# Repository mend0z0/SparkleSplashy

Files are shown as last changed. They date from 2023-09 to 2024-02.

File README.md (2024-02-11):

## Latest update

``
Latest update, or process that is going through
``

# Project

Description...

## Category

__Home/Office Automation__

## Features

- 
- 
- 

## Tech Stack

### Hardware

- **MCU:** ATSAM4SD16BA
- **Connection:** 
- **PCB Layers:** 4Layers (None-controlled Impedance)
- **CAD:** KiCAD

### Firmware

- **OS:** FreeRTOS
- **Programming Language:** C
- **IDE:** Microchip Studio

### Application

- **IDE:** Qt6
- **Operating System:** Linux/Windows
- **Device:** Laptop

### Mechanical

- **CAD:** Solid Edge
- **Printing Method:** 3D Printing

## Block Diagrams

SystemDesign

Hardware

Firmware

## Screenshots

### Hardware

#### CAD View

_CADView

#### 3D_View

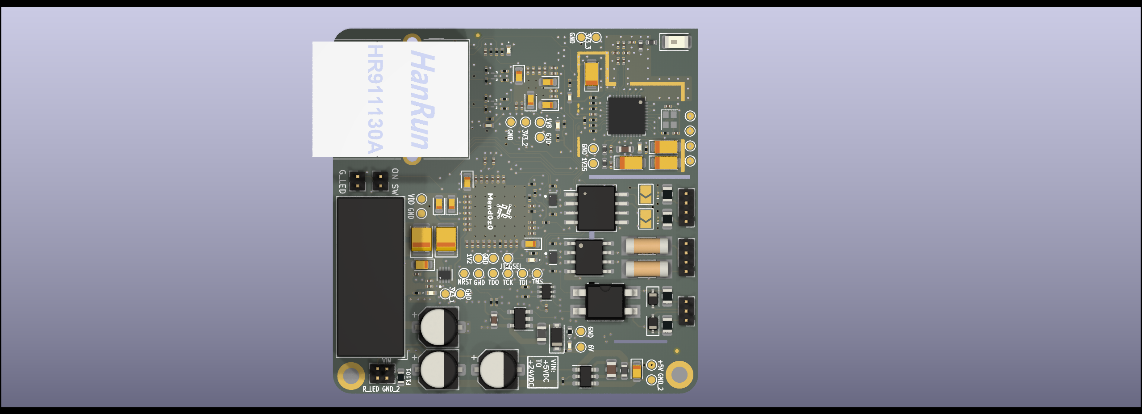
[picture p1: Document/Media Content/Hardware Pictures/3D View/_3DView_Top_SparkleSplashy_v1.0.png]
_3DView_Top


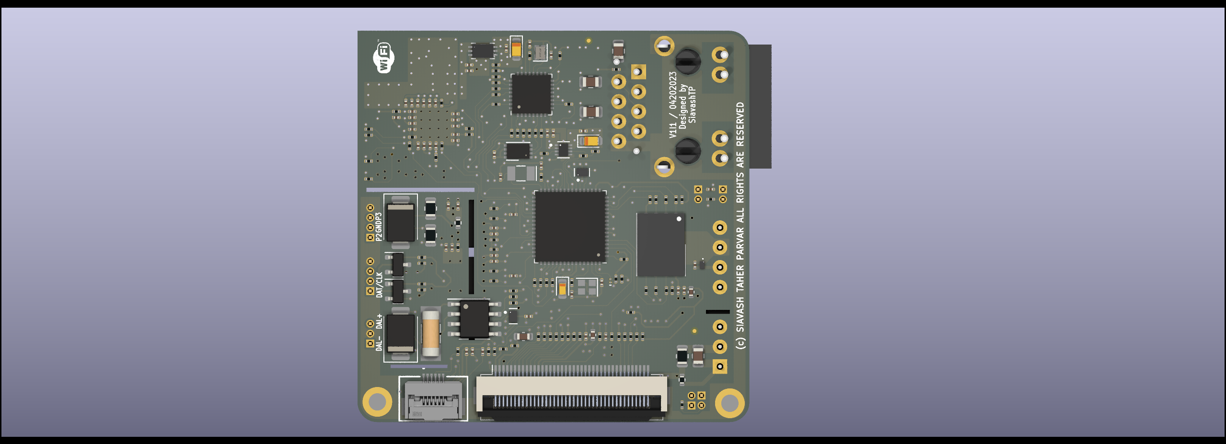
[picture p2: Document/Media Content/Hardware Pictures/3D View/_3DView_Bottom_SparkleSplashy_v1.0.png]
_3DView_Bottom

 
#### Assembled Hardware

_ASMView_Top

_ASMView_Bottom

### Application
App Screenshot

## Demo

Insert gif or link to demo, it'll be my youtube channel

## LOGO

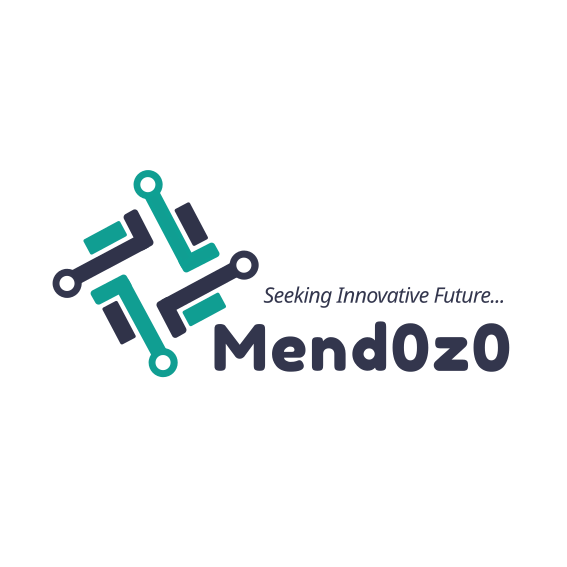
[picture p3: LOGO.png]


## Author

- [@Siavash Taher Parvar](https://www.linkedin.com/in/mend0z0)

## Support

[Support Link](https://github.com/sponsors/mend0z0)

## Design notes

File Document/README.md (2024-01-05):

1. Block Diagrams: 
	1. _FBD_HW_Prj_vXY.svg
	2. _FBD_SYS_Prj_vXY.svg
	3. _FBD_FW_Prj_vXY.svg

2. Datasheet: 

3. Media Content: 
	1. Application Screenshot:

	2. Hardware Picture:
		1. 3D View:
			1. _3DView_Top_Prj_vXY.png
			2. _3DView_Bottom_Prj_vXY.png

		2. Assembled Hardware:
			1. _ASMView_Top_Prj_vXY.png
			2. _ASMView_Bottom_Prj_vXY.png

		3. CAD View:
			1._CADView_Prj_vXY.svg

	3. Videos:

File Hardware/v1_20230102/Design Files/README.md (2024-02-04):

# TODO list

A brief description of this todo list belongs to what project

## Tasks

- #### MUST to DO (List the works that proper working of project depends on these tasks):
    - Correct 24KR_1/20W footprint
    - Review the schematic and replacing the limiting resistor possibly with PTC!
    - Correcting the link for part -CW105550A-15NJ-.
    - It's absolete (NC7WZ14P6X-L22347) find another one!
    - Adding the LCD to BOM! (correcting it's library)
    - 
- #### Important (List the works that efficient and optimized functionality of project depends on these tasks):
    - 
    -
    - 
- #### General (List tasks that are good to be done but the functionality of project doesn't depend on these):
    - 
    -
    -

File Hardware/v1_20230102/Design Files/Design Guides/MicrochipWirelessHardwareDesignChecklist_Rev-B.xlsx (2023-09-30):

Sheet: Checklist
Microchip Wireless Hardware Design Checklist
Introduction: This checklist is provided as a "Best Pratice" guide for your RF design. It can be used as-is or as part of our free design review service called WirelessCheck. If you would like use this value added service, please click here->. |  |  |  |  |  |  | Link to WirelessCheck (https://www.microchip.com/design-check-services)
Instructions for WirelessCheck Customers: Fill in "Customer" column for all checkpoints during the design phase and prior to requesting design review support from Microchip. While raising design review support request, attach the completed checklist along with the design files (Schematic, BoM, PCB Layout File, Gerber files). A Microchip Support Engineer will review and provide his/her comments in the "Microchip" column and communicate this back to you.
Instructions for as-is useage: Fill in "Customer" column for all checkpoints during the design phase. This will provide you with a checklist of typical areas of concern for your RF design and some suggestions on best practices from Microchip RF Engineers.
S.No. | Design Item | Description | Customer |  | Microchip |  | Customer
 |  |  | Verified (Yes/No/NA) | Comment if any | OK/NOT OK | Microchip Review Comments | Response for Review Comments
1 | General Considerations:
1.1 | Documentation | Did you refer the latest version of the documents for the design such as Silicon chip/Module datasheet, Errata and Reference/Evaluation kit design documents, chip-down collateral package (for chip-down design)?
1.2 | Device (Silicon Chip/Module) | Is the device ordering part number used in the design BoM verified?
1.3 | Reference Design File | Microchip Wireless Reference PCB design files will be mostly in Altium Tool format. Customer should convert into their other CAD tools if needed.
1.4 | Pin check | Is the pinout of the schematic logical symbol against the data sheet verified?
1.5 | Footprint Check | Is the PCB footprint of the silicon chip/module verified against the package outline drawing or recommended footprint/land pattern drawing detailed in the data sheet? It is recommended to use the same footprint as in the reference design.
2 | PCB Stack Up Considerations:
2.1 | PCB Stack up | Use the same PCB Layer Stackup as in the reference design. If in case following a different PCB layer stackup to meet the custom design requirement, confirm the following items before the start of the design • Check with PCB Fabrication Vendor for the manufacturability of the stackup. • Ensure to follow a good reference plane for RF ground and Digital/Analog Ground plane and other high speed design requirements. • Check the controlled trace impedance requirements for the design and get the required trace width and spacing details from the PCB Fabrication Vendor.
3 | Power Supply Considerations:
3.1 | Power Supply Pins | Do all the power pins connected to the correct supply rails in the design and it is within the required tolerance value as detailed in the datasheet?
3.2 | Power Supply Source | Is the power supply source clean without any noise? Note: It is recommended to use LDO. If you are using the switching regulator, ensure that the sufficient filtering are added to suppress the switching noise (ripple) on the power rail as it impacts the RF performance.
3.3 | Power Budgeting | Is the power budgeting performed to ensure the power source component capable to supply the required current to the circuit in all functional conditions?
3.4 | Power Trace | Is the power rail trace thickness/width selected appropriately based on the expected peak power consumption, with certain margin? Use a power trace calculator to find the minimum required trace width. PCB Trace Width Calculator (For Reference): https://www.desmith.net/NMdS/Electronics/TraceWidth.html
3.5 | Ground | Do the grounding specification followed as in the datasheet or in the corresponding silicon chip/module reference/evaluation design kit? It is preferred to use simple solid ground plane unless otherwise specified.
3.6 | Power Sequencing | Did you check the device (silicon/module) requires any specific power up/down sequencing in terms of the order and delays of the power supplies?
3.7 | Thermal Pad /Ground Paddle | Did you check whether the device (silicon chip/module) require thermal pad ground connection? Note: Ensure that an array of GND vias connecting the thermal pad to the ground plane has sufficient low impedance ground return path which provides a better ground to the device and also acts as thermal sink. Also, connect the GND pin to the GND Paddle for better grounding in addition to the separate ground via.
3.8 | Ferrite Beads | Did you verify whether the ferrite beads placed in the design as specified in the recommended power pins of the silicon chip/module? Note: Place the ferrite beads as close as possible to the power pin.
3.9 | Bulk Capacitors | Did you verify whether the recommended bulk capacitors placed on the power rails of the design? Refer the Datasheet and/or reference design document for the recommended values.
3.10 | Decoupling/Bypass Capacitors | Did you verify whether the recommended decoupling capacitors placed on each power pins in the design? Refer the Datasheet and/or reference design document for the recommended values. Note: Ensure that the decoupling capacitors are effective at Radio Frequencies. Many passive capacitors are self-resonant at RF, therefore review S21 plots and frequency response curves. It is recommended to use COG and avoid Y5V and Z5U dielectric type capacitors.
3.11 | Placement & Routing | a. Prioiritze the placement and routing in the following order, (i) RF Section (ii) Buck or Boost LC Section (iii) Clock Section (iv) High Speed Signals (v) Other Power Section (vi) and finally low priority section placement and signals. b. Did you place the decoupling capacitors close to the power pins for high-frequency noise filtering? Note: Refer "Reference" worksheet Image-1 for the recommended decap routing. c. Did you verify whether each Ground pin have at least one ground via? d. Did you place vias very close to the power pads to connect the power/ground pins to the power/ground plane? This helps in minimizing stray inductance and IR (voltage) drop on the power line. e. Did you place multiple vias when Power trace/island changes the plane for current distribution?
3.12 | Copper Pour | Did you eliminate Island (Unconnected or floating or Dead) Copper Pour amd peninsulas of copper pour? Note: Refer "Reference" worksheet, Image-3 and Image-4 to know more about Island/s and peninsula/s.
4 | Reset and Chip Enable Considerations:
4.1 | Reset | Did you verify the connection and pullup/pulldown recommendation for the RESET pin in the datasheet?
4.2 | Chip Enable | Did you verify the connection and pullup/pulldown recommendation for the Chip Enable pin in the datasheet?
5 | Clocking Considerations:
5.1 | Clock Source | Recommend to follow the same clock source part (Crystal/TCXO) as in the reference design. As the clock parameters directly impact the RF performancem, customer should understand the impact on the performance involved if using different clock source part.
5.2 | Clock Trace Routing | a. Are the clock traces routed away from RF signals? b. Are the guarding ground vias placed along the crystals and the clock traces?
6 | I/O's:
6.1 | Pullups/Pulldowns | Are the recommended pullup and pulldown resistors placed on the I/O's with the suggested values as listed in the datasheet or reference design?
6.2 | Application Interface | Are the mandatory interfaces connected to communicate with the device (silicon chip/module) for the end application requirement?
6.3 | Impedance controlled trace | Is the impedance control requirement verified? Note: Unless otherwise stated, the single ended trace impedance should be 50Ω , differential trace impedance of USB should be 90Ω and other differential trace impedance should be 100Ω. Refer Device Datasheet and its design guide. Use an impedance calculator to calculate the trace width for a specific trace impedance. Check with fab house to optimize the materials and controlled impedance. Request for a TDR (Time Domain Reflectometry) test to the PCB fabricator for QA.
6.4 | Signal integrity | Did you complete the Signal integrity check such as, trace length match, impedance control requirements, proper termination requirement for the critical highspeed signals? Refer the reference kit design document for cross verification.
6.5 | Debug Interface | Did you check the required programming and debug interfaces like JTAG,SW? Ensure to expose the traces for debug.
6.6 | Test Interface | Did you check whether any dedicated test interface requires to communicate with the RF transceiver to perform RF level test such as, continuous Tx, Rx with Tx power control, channel selection, data rate selection for RF Validation, Regulatory Certification, and Production testing?
6.7 | Unused pins | Does all unused inputs terminated as recommened in datasheet?. Refer the evaluation kit design document and datasheet guidance.
6.8 | Test coverage | Did you check whether every (maximum possible) trace have a touch-down point (open solder mask on the via or some passive component pads apart from IC pads) for continuity testing in PCB manufacturing?
7 | RF Design Considerations:
7.1 | Module Based Designs - RF Design Considerations:
7.1.1 | Module Placement | Is the module placed in the base board as per the datasheet recommendation for best RF performance case? Refer "Reference" worksheet -> FCC KDB : Reference-1 for the FCC Guidance
7.1.2 | Mechanical Cutout/Slot | Did you verify the host board for mechanical cut out/slot area requirement? Refer module datasheet recommendation.
7.1.3 | Electrical Keep out Area | Did you check the host board copper keep out area requirement for the Top placement layer and all other PCB layers? Refer the module datasheet for the recommendation. Note: Ensure that no traces/metal structures are placed under antennas.
7.1.4 | GND Shielding and Stitching Vias | Are the sufficient GND area, fences/stitching vias for RF traces placed? Refer "Reference" worksheet Image-2 for the proper "via" stitching fences.
7.1.5 | Clearance | Is the minimum clearance requirement verified? • Antenna on the module must not be placed in direct contact or close proximity to plastic casing/objects. • Do not enclose the antenna within a metal structure.
7.1.6 | External Antenna (Applicable for only a module with external antenna connector) | Did you use the same antenna as specified in the Microchip Module certification test report? Note: If different antenna is preferred to use, refer to Q&A especially section III, B, C and D of FCC KDB (https://apps.fcc.gov/oetcf/kdb/forms/FTSSearchResultPage.cfm?switch=P&id=39060) for to use the Microchip regulatory compliance certification of the module.
7.2 | Chip-down Based Designs -RF Design Considerations:
7.2.1 | RF Front End Components and PCB layout. | Did you use the same RF front end design as specified in the reference design (Module design/Evaluation Kit)? Note: It is recommended to use the RF front end components and PCB Layout "AS IS" in the reference design (Module design/Evaluation Kit) to achieve the target RF Performance. Any deviation leads to degradation in RF performance.
7.2.2 | RF trace - Impedance control | Is the impedance control requirement verified for RF traces? Note: Unless otherwise stated, all the single ended RF trace impedance should be 50Ω and differential RF trace impedance should be 100Ω. Refer Device Datasheet and its design guide.
7.2.3 | Balun | Did you use the same balun circuitry as in reference design (Module design/Reference kit)? Note: All RF currents flow though the Balun. Make sure balun ground connections are solid.
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

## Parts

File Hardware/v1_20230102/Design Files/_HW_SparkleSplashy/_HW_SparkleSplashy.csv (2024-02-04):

Source: | D:\Projects\STP\SparkleSplashy\Hardware\v1_20230102\Design Files\_HW_SparkleSplashy\_HW_SparkleSplashy.kicad_sch
Date: | 2/4/2024 2:45:05 AM
Tool: | Eeschema 7.0.9
Generator: | C:\Program Files\KiCad\7.0\bin\scripting\plugins/bom_csv_grouped_by_value.py
Component Count: | 344
Collated Components:
Item | Qty | Reference(s) | Value | LibPart | Footprint | Datasheet | DNP | CURRENT RATING | Current Rating | D.C.R | DCR | Description | DescriptionCL05A475KQ5NRNC | ESR | INDCUTANCE | INDUCTANCE | Ihold | Inductance | Link | MAX DC | Package | Part NumbeR | Part Number | Part Numbner | RATED CURRENT | SCH CHECK | VBR | VOLTAGE RATE | VOLTAGE RATED | Voltage Off State | Voltage Rated
1 | 1 | ANT501 | 2450AT18A100E | _SCHLIB_SparkleSplashy:ANT_2450AT18A100E | RF_Antenna:Johanson_2450AT18x100 | https://www.johansontechnology.com/datasheets/2450AT18A100/2450AT18A100.pdf |  |  |  |  |  | 2.4GHz Chip RF Antenna 2.4GHz ~ 2.5GHz 0.5dBi Solder Surface Mount |  |  |  |  |  |  | https://www.digikey.com/en/products/detail/johanson-technology-inc/2450AT18A100E/1560676 |  |  |  | 2450AT18A100E |  |  | CHECKED
2 | 35 | C301, C302, C303, C304, C316, C317, C318, C324, C325, C332, C404, C408, C409, C410, C414, C504, C507, C508, C510, C520, C521, C524, C526, C529, C530, C603, C605, C803, C805, C1003, C1005, C1201, C1202, C1204, C1205 | 100nF/6V3 | _SCHLIB_SparkleSplashy:CAP_100nF/6V3 | Capacitor_SMD:C_0201_0603Metric | https://www.yageo.com/upload/media/product/productsearch/datasheet/mlcc/UPY-GPHC_X7R_6.3V-to-250V_22.pdf |  |  |  |  |  | 0.1 µF ±10% 6.3V Ceramic Capacitor X7R 0201 (0603 Metric) |  |  |  |  |  |  | https://www.digikey.ca/en/products/detail/yageo/CC0201KRX7R5BB104/12698853 |  | C0201 |  | CC0201KRX7R5BB104 |  |  | CHECKED
3 | 16 | C305, C306, C307, C308, C326, C327, C328, C329, C405, C411, C412, C413, C415, C501, C514, C703 | 10nF/6V3 | _SCHLIB_SparkleSplashy:CAP_10nF/6V3 | Capacitor_SMD:C_0201_0603Metric | http://www.passivecomponent.com/wp-content/uploads/datasheet/WTC_MLCC_General_Purpose.pdf |  |  |  |  |  | 10000 pF ±10% 6.3V Ceramic Capacitor X7R 0201 (0603 Metric) |  |  |  |  |  |  | https://www.digikey.ca/en/products/detail/walsin-technology-corporation/0201B103K6R3CT/9354618 |  | C0201 |  | 0201B103K6R3CT |  |  | CHECKED
4 | 4 | C309, C310, C311, C312 | 1nF/50V | _SCHLIB_SparkleSplashy:CAP_1nF/50V | Capacitor_SMD:C_0201_0603Metric | https://search.murata.co.jp/Ceramy/image/img/A01X/G101/ENG/GRM0335C1H102JE01-01A.pdf |  |  |  |  |  | 1000 pF ±5% 50V Ceramic Capacitor C0G, NP0 0201 (0603 Metric) |  |  |  |  |  |  | https://www.digikey.ca/en/products/detail/murata-electronics/GRM0335C1H102JE01D/16033845 |  | C0201 |  | GRM0335C1H102JE01D |  |  | CHECKED
5 | 31 | C313, C314, C315, C319, C331, C417, C502, C505, C506, C509, C515, C516, C519, C525, C527, C528, C602, C801, C802, C804, C901, C902, C1001, C1002, C1004, C1206, C1207, C1208, C1209, C1210, C1211 | 2u2F/6V3 | _SCHLIB_SparkleSplashy:CAP_2u2F/6V3 | Capacitor_SMD:C_0201_0603Metric | https://ele.kyocera.com/assets/products/capacitor/CM_Series_e.pdf |  |  |  |  |  | 2.2 µF ±20% 6.3V Ceramic Capacitor X5R 0201 (0603 Metric) |  |  |  |  |  |  | https://www.digikey.ca/en/products/detail/kyocera-avx/CM03X5R225M06AH/10815044 |  | C0201 |  | CM03X5R225M06AH |  |  | CHECKED
6 | 8 | C320, C321, C322, C323, C406, C407, C522, C523 | 12pF/50V | _SCHLIB_SparkleSplashy:CAP_12pF/50V | Capacitor_SMD:C_0201_0603Metric | https://www.yageo.com/upload/media/product/productsearch/datasheet/mlcc/UPY-GP_NP0_16V-to-50V_18.pdf |  |  |  |  |  | 12 pF ±5% 50V Ceramic Capacitor C0G, NP0 0201 (0603 Metric) |  |  |  |  |  |  | https://www.digikey.ca/en/products/detail/yageo/CC0201JRNPO9BN120/5194994 |  | C0201 |  | CC0201JRNPO9BN120 |  |  | CHECKED
7 | 1 | C330 | 470pF/50V | _SCHLIB_SparkleSplashy:CAP_470pF/50V | Capacitor_SMD:C_0201_0603Metric | https://product.tdk.com/system/files/dam/doc/product/capacitor/ceramic/mlcc/catalog/mlcc_automotive_general_en.pdf |  |  |  |  |  | 470 pF ±20% 50V Ceramic Capacitor X7R 0201 (0603 Metric) |  |  |  |  |  |  | https://www.digikey.ca/en/products/detail/tdk-corporation/CGA1A2X7R1H471M030BA/3949350 |  | C0201 |  | CGA1A2X7R1H471M030BA |  |  | CHECKED
8 | 1 | C401 | 10uF/50V | _SCHLIB_SparkleSplashy:CAP_10uF/50V | Capacitor_SMD:C_0805_2012Metric | https://search.murata.co.jp/Ceramy/image/img/A01X/G101/ENG/GRM21BR61H106KE43-01A.pdf |  |  |  |  |  | 10 µF ±10% 50V Ceramic Capacitor X5R 0805 (2012 Metric) |  |  |  |  |  |  | https://www.digikey.ca/en/products/detail/murata-electronics/GRM21BR61H106KE43L/10326316 |  | C0805 |  | GRM21BR61H106KE43L |  |  | CHECKED
9 | 4 | C402, C403, C1101, C1102 | 100nF/63V | _SCHLIB_SparkleSplashy:CAP_100nF/63V | Capacitor_SMD:C_0805_2012Metric | https://connect.kemet.com:7667/gateway/IntelliData-ComponentDocumentation/1.0/download/datasheet/C0805C104MMREC7210 |  |  |  |  |  | 0.1 µF ±20% 63V Ceramic Capacitor X7R 0805 (2012 Metric) |  |  |  |  |  |  | https://www.digikey.ca/en/products/detail/kemet/C0805C104MMREC7210/8645408 |  | C0805 |  | C0805C104MMREC7210 |  |  | CHECKED
10 | 5 | C416, C531, C601, C606, C702 | 1uF/6V3 | _SCHLIB_SparkleSplashy:CAP_1uF/6V3 | Capacitor_SMD:C_0201_0603Metric | http://weblib.samsungsem.com/mlcc/mlcc-ec-data-sheet.do?partNumber=CL03A105MQ3CSN |  |  |  |  |  | 1 µF ±20% 6.3V Ceramic Capacitor X5R 0201 (0603 Metric) |  |  |  |  |  |  | https://www.digikey.ca/en/products/detail/samsung-electro-mechanics/CL03A105MQ3CSNH/3894097 |  | C0201 |  | CL03A105MQ3CSNH |  |  | CHECKED
11 | 3 | C503, C511, C512 | 1pF/50V | _SCHLIB_SparkleSplashy:CAP_1pF/50V | Capacitor_SMD:C_0201_0603Metric | https://media.digikey.com/pdf/Data%20Sheets/Taiyo%20Yuden%20PDFs%20URL%20links/UMK063CG010CTHF_SS.pdf |  |  |  |  |  | 1 pF ±0.25pF 50V Ceramic Capacitor C0G, NP0 0201 (0603 Metric) |  |  |  |  |  |  | https://www.digikey.com/en/products/detail/taiyo-yuden/UMK063CG010CTHF/4811142 |  | C0201 |  | UMK063CG010CTHF |  |  | CHECKED
12 | 3 | C513, C1203, C1212 | 10uF/16V | _SCHLIB_SparkleSplashy:CAP_10uF/16V | Capacitor_SMD:C_0603_1608Metric | https://search.murata.co.jp/Ceramy/image/img/A01X/G101/ENG/GRT188R61C106KE13-01.pdf |  |  |  |  |  | 10 µF ±10% 16V Ceramic Capacitor X5R 0603 (1608 Metric) |  |  |  |  |  |  | https://www.digikey.ca/en/products/detail/murata-electronics/GRT188R61C106KE13J/13904802 |  | C0603 |  | GRT188R61C106KE13J |  |  | CHECKED
13 | 2 | C517, C518 | 1p8F/50V | _SCHLIB_SparkleSplashy:CAP_1p8F/50V | Capacitor_SMD:C_0201_0603Metric | https://media.digikey.com/pdf/Data%20Sheets/Taiyo%20Yuden%20PDFs%20URL%20links/UMK063CG1R8CTHF_SS.pdf |  |  |  |  |  | 1.8 pF ±0.25pF 50V Ceramic Capacitor C0G, NP0 0201 (0603 Metric) |  |  |  |  |  |  | https://www.digikey.com/en/products/detail/taiyo-yuden/UMK063CG1R8CTHF/7066046 |  | C0201 |  | UMK063CG1R8CTHF |  |  | CHECKED
14 | 2 | C604, C701 | 4u7F/6V3 | _SCHLIB_SparkleSplashy:CAP_4u7F/6V3 | Capacitor_SMD:C_0402_1005Metric | https://media.digikey.com/pdf/Data%20Sheets/Samsung%20PDFs/CL05A475KQ5NRNC_Spec.pdf |  |  |  |  |  | 1 µF ±20% 6.3V Ceramic Capacitor X5R 0201 (0603 Metric) | 4.7 µF ±10% 6.3V Ceramic Capacitor X5R 0402 (1005 Metric) |  |  |  |  |  | https://www.digikey.ca/en/products/detail/samsung-electro-mechanics/CL05A475KQ5NRNC/3887139 |  | C0402 |  | CL05A475KQ5NRNC |  |  | CHECKED
15 | 1 | C1103 | 100nF/16V | _SCHLIB_SparkleSplashy:CAP_100nF/16V | Capacitor_SMD:C_0201_0603Metric | http://www.passivecomponent.com/wp-content/uploads/datasheet/WTC_MLCC_General_Purpose.pdf |  |  |  |  |  | 0.1 µF ±10% 16V Ceramic Capacitor X5R 0201 (0603 Metric) |  |  |  |  |  |  | https://www.digikey.ca/en/products/detail/walsin-technology-corporation/0201X104K160CT/9354659 |  | C0201 |  |  | 0201X104K160CT |  | CHECKED
16 | 2 | D401, D402 | RCLAMP0512TQTNT | _SCHLIB_SparkleSplashy:TVS_RCLAMP0512TQTNT | _PCBLIB_SparkleSplashy:3-XDFN | https://media.digikey.com/pdf/Data%20Sheets/Semtech%20PDFs/RCLAMP0512TQ_Rev6_12-17-15.pdf |  |  |  |  |  | 8.5V Clamp 20A (1.2/50µs) Ipp Tvs Diode Surface Mount SGP1006N3T |  |  |  |  |  |  | https://www.digikey.ca/en/products/detail/semtech-corporation/RCLAMP0512TQTNT/5642185 |  |  |  | RCLAMP0512TQTNT |  |  | CHECKED
17 | 1 | D801 | TISP4011H1BJR-S | _SCHLIB_SparkleSplashy:SCR_TISP4011H1BJR-S | Diode_SMD:D_SMB | https://www.bourns.com/docs/Product-Datasheets/tisp4011h1bj.pdf |  |  |  |  |  | 5.25V Off-State Ipp TVS Thyristor DO-214AA, SMB |  |  |  |  |  |  | https://www.digikey.ca/en/products/detail/bourns-inc/TISP4011H1BJR-S/6236760 |  | SMB |  | TISP4011H1BJR-S |  |  | CHECKED |  |  |  | 5.25V
18 | 2 | D802, D803 | ESDZV5H-1BU2 | _SCHLIB_SparkleSplashy:TVS_ESDZV5H-1BU2 | Diode_SMD:Nexperia_DSN0603-2_0.6x0.3mm_P0.4mm | https://www.st.com/resource/en/datasheet/esdzv5h-1bu2.pdf |  |  |  |  |  | 11V Clamp 4A (8/20µs) Ipp Tvs Diode Surface Mount ST0201 |  |  |  |  |  |  | https://www.digikey.ca/en/products/detail/stmicroelectronics/ESDZV5H-1BU2/10414282 |  | ST0201 |  | ESDZV5H-1BU2 |  |  | CHECKED | 5.5V
19 | 1 | D901 | TISP4025H1BJR-S | _SCHLIB_SparkleSplashy:SCR_TISP4025H1BJR-S | Diode_SMD:D_SMB | https://www.bourns.com/data/global/pdfs/TISP40xxH1BJ.pdf |  |  |  |  |  | 13V Off-State 400 A Ipp TVS Thyristor DO-214AA, SMB |  |  |  |  |  |  | https://www.digikey.ca/en/products/detail/bourns-inc/TISP4025H1BJR-S/5816300 |  | SMB |  | TISP4025H1BJR-S |  |  | CHECKED |  |  |  | 13 V
20 | 2 | D902, D903 | SD22-01FTG | _SCHLIB_SparkleSplashy:TVS_SD22-01FTG | Diode_SMD:D_SOD-323 | https://www.littelfuse.com/~/media/electronics/datasheets/tvs_diode_arrays/littelfuse_tvs_diode_array_sd22_datasheet.pdf.pdf |  |  |  |  |  | 35.5V (Typ) Clamp 27A (8/20µs) Ipp Tvs Diode Surface Mount SOD-323 |  |  |  |  |  |  | https://www.digikey.ca/en/products/detail/littelfuse-inc/SD22-01FTG/13532036 |  | SOD-323 |  | SD22-01FTG |  |  | CHECKED | 23V
21 | 1 | D1101 | AQ1250-01ETG | _SCHLIB_SparkleSplashy:TVS_AQ1250-01ETG | _PCBLIB_SparkleSplashy:SOD882 | https://www.littelfuse.com/~/media/electronics/datasheets/tvs_diode_arrays/littelfuse_tvs_diode_array_aq1250-01etg_datasheet.pdf.pdf |  |  |  |  |  | 10V Clamp 50A (8/20µs) Ipp Tvs Diode Surface Mount SOD-882 |  |  |  |  |  |  | https://www.digikey.ca/en/products/detail/littelfuse-inc/AQ1250-01ETG/14317741 |  | SOD882 |  | AQ1250-01ETG |  |  | CHECKED | 5V5
22 | 1 | D1201 | NSR01F30NXT5G | _SCHLIB_SparkleSplashy:DIODE_NSR01F30NXT5G | Diode_SMD:Nexperia_DSN0603-2_0.6x0.3mm_P0.4mm | https://www.onsemi.com/pdf/datasheet/nsr01f30-d.pdf |  |  | 100 mA |  |  | Diode 30 V 100mA Surface Mount 2-DSN (0.60x0.30) |  |  |  |  |  |  | https://www.digikey.ca/en/products/detail/onsemi/NSR01F30NXT5G/2194403 |  | DSN2 |  | NSR01F30NXT5G |  |  | CHECKED |  |  |  |  | 30 V
23 | 1 | D1202 | 1N5819HW1-7-F | _SCHLIB_SparkleSplashy:DIODE_1N5819HW1-7-F | Diode_SMD:D_SOD-123F | https://www.diodes.com/assets/Datasheets/1N5819HW1.pdf |  |  | 1 A |  |  | Diode 40 V 1A Surface Mount SOD-123F |  |  |  |  |  |  | https://www.digikey.ca/en/products/detail/diodes-incorporated/1N5819HW1-7-F/5768523 |  | SOD_123F |  | 1N5819HW1-7-F |  |  | CHECKED |  |  |  |  | 40 V
24 | 1 | DIS601 | AFY240320A1-2.8INTH-C1 | _SCHLIB_SparkleSplashy:MECH_DIS_AFY240320A1-2.8INTH-C1 |  | https://www.orientdisplay.com/wp-content/uploads/2021/11/AFY240320A1-2.8INTH-C1.pdf |  |  |  |  |  | Capacitive Graphic LCD Display Module Transmissive Red, Green, Blue (RGB) TFT - Color, IPS (In-Plane Switching) MIPI, RGB, SPI 2.8" (71.12mm) 240 x 320 |  |  |  |  |  |  | https://www.digikey.ca/en/products/detail/orient-display/AFY240320A1-2-8INTH-C1/15790821 |  |  |  | AFY240320A1-2.8INTH-C1 |  |  | CHECKED
25 | 3 | EC1101, EC1102, EC1103 | 10uF/50V | _SCHLIB_SparkleSplashy:ECAP_10uF/50V | Capacitor_SMD:CP_Elec_5x5.3 | https://industrial.panasonic.com/cdbs/www-data/pdf/AAB8000/AAB8000C226.pdf |  |  |  |  |  | 10 µF 50 V Aluminum - Polymer Capacitors Radial, Can - SMD 80mOhm 1000 Hrs @ 125°C |  | 80mR |  |  |  |  | https://www.digikey.ca/en/products/detail/panasonic-electronic-components/50SVPK10M/7564810 |  | SMD(5.3X5.3) |  | 50SVPK10M |  |  | CHECKED
26 | 4 | F801, F802, F901, F902 | 0805L010/24YR | _SCHLIB_SparkleSplashy:FUSE_0805L010/24YR | Fuse:Fuse_0805_2012Metric | https://www.littelfuse.com/~/media/electronics/datasheets/resettable_ptcs/littelfuse_ptc_0805l_datasheet.pdf.pdf |  |  |  |  |  | Polymeric PTC Resettable Fuse 24V 100 mA Ih Surface Mount 0805 (2012 Metric), Concave |  |  |  |  | 100 mA |  | https://www.digikey.ca/en/products/detail/littelfuse-inc/0805L010-24YR/4556346 |  | F0805 |  | 0805L010/24YR |  |  | CHECKED |  |  |  |  | 24 V
27 | 1 | F1101 | ERB-RE1R00V | _SCHLIB_SparkleSplashy:FUSE_ERB-RE1R00V | Fuse:Fuse_0603_1608Metric | https://industrial.panasonic.com/cdbs/www-data/pdf/AFA0000/AFA0000C7.pdf |  |  |  |  |  | 1 A AC 32 V DC Fuse Board Mount (Cartridge Style Excluded) Surface Mount 0603 (1608 Metric) |  |  |  |  |  |  | https://www.digikey.ca/en/products/detail/panasonic-electronic-components/ERB-RE1R00V/2796790 |  | F0603 |  | ERB-RE1R00V |  | 1A | CHECKED |  | 32VDC
28 | 4 | FD1301, FD1302, FD1303, FD1304 | ~ | _SCHLIB_SparkleSplashy:MECH_FD | Fiducial:Fiducial_0.5mm_Mask1mm
29 | 1 | J401 | SI-60005-F | _SCHLIB_SparkleSplashy:CONN_SI-60005-F | _PCBLIB_SparkleSplashy:RJ45_Bel_SI-60062-F | https://www.belfuse.com/resources/drawings/magneticsolutions/dr-mag-si-60005-f.pdf |  |  |  |  |  | 1 Port RJ45Through Hole 10/100 Base-T, AutoMDIX |  |  |  |  |  |  | https://www.digikey.ca/en/products/detail/bel-fuse-inc/SI-60005-F/1642348 |  |  |  | SI-60005-F |  |  | CHECKED
30 | 1 | J601 | CF31401D0R0-05-NH | _SCHLIB_SparkleSplashy:CONN_CF31401D0R0-05-NH | _PCBLIB_SparkleSplashy:FPC_FH12-40S-0.5SH_1x40-1MP_P0.50mm_Horizontal | https://www.cvilux.com/uploads/drawings/101/073/CF3103S.pdf |  |  |  |  |  | 40 Position FFC, FPC Connector Contacts, Bottom 0.020" (0.50mm) Surface Mount, Right Angle |  |  |  |  |  |  | https://www.digikey.ca/en/products/detail/cvilux-usa/CF31401D0R0-05-NH/15793184 |  |  |  | CF31401D0R0-05-NH |  |  | CHECKED
31 | 1 | J602 | F305-1A7H1-11006-E100 | _SCHLIB_SparkleSplashy:CONN_F305-1A7H1-11006-E100 | _PCBLIB_SparkleSplashy:CONN_FPC_6POS_0.5P,BOTTOM | https://cdn.amphenol-cs.com/media/wysiwyg/files/drawing/f305-1.pdf |  |  |  |  |  | 6 Position FFC, FPC Connector Contacts, Bottom 0.020" (0.50mm) Surface Mount, Right Angle6 Position FFC, FPC Connector Contacts, Bottom 0.020" (0.50mm) Surface Mount, Right Angle |  |  |  |  |  |  | https://www.digikey.ca/en/products/detail/amphenol-cs-fci/F305-1A7H1-11006-E100/11564562 |  |  |  | F305-1A7H1-11006-E100 |  |  | CHECKED
32 | 1 | L501 | L-07C3N9SV6T | _SCHLIB_SparkleSplashy:INDC_L-07C3N9SV6T | Inductor_SMD:L_0402_1005Metric | https://www.johansontechnology.com/downloads/jti-cat-rf-ind.pdf |  | 300mA |  | 220mR |  | 3.9 nH Unshielded Multilayer Inductor 300 mA 220mOhm Max 0402 (1005 Metric) |  |  | 3n9H |  |  |  | https://www.digikey.com/en/products/detail/johanson-technology-inc/L-07C3N9SV6T/1915227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 |  | L0402 |  | L-07C3N9SV6T |  |  | CHECKED
33 | 1 | L502 | L-07C2N7SV6T | _SCHLIB_SparkleSplashy:INDC_L-07C2N7SV6T | Inductor_SMD:L_0402_1005Metric | https://www.johansontechnology.com/downloads/jti-cat-rf-ind.pdf |  | 300mA |  |  | 170mR | 2.7 nH Unshielded Multilayer Inductor 300 mA 170mOhm Max 0402 (1005 Metric) |  |  |  | 2n7H |  |  | https://www.digikey.com/en/products/detail/johanson-technology-inc/L-07C2N7SV6T/1830166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 |  | L0402 |  | L-07C2N7SV6T |  |  | CHECKED
34 | 2 | L503, L504 | WLCM0603TGB3N3TB | _SCHLIB_SparkleSplashy:INDC_WLCM0603TGB3N3TB | Inductor_SMD:L_0201_0603Metric | http://www.passivecomponent.com/wp-content/uploads/inductor/WLCM0603TG_Series.pdf |  | 400mA |  | 300mR |  | 3.3 nH Unshielded Multilayer Inductor 400 mA 300mOhm Max 0201 (0603 Metric) |  |  |  | 3n3H |  |  | https://www.digikey.com/en/products/detail/walsin-technology-corporation/WLCM0603TGB3N3TB/14563850 |  | L0201 |  | WLCM0603TGB3N3TB |  |  | CHECKED
35 | 1 | L505 | MLZ1005M2R2WT000 | _SCHLIB_SparkleSplashy:INDC_MLZ1005M2R2WT000 | Inductor_SMD:L_0402_1005Metric | https://product.tdk.com/en/system/files |  | 350mA |  |  | 550mR | 2.2 µH Shielded Multilayer Inductor 350 mA 550mOhm 0402 (1005 Metric) |  |  |  | 2u2H |  |  | https://www.digikey.ca/en/products/detail/tdk-corporation/MLZ1005M2R2WT000/2465140 |  | L0402 |  | MLZ1005M2R2WT000 |  |  | CHECKED
36 | 1 | L506 | CW105550A-15NJ | _SCHLIB_SparkleSplashy:INDC_CW105550A-15NJ | Inductor_SMD:L_0402_1005Metric | https://www.bourns.com/docs/Product-Datasheets/CW105550A.pdf |  | 560mA |  |  | 172mR | 15 nH Unshielded Inductor 560 mA 172mOhm Max 0402 (1005 Metric) |  |  |  | 15nH |  | 15nH | https://www.digikey.ca/en/products/detail/bourns-inc/CW105550A-15NJ/9826723 |  | L0402 |  | CW105550A-15NJ |  |  | CHECKED
37 | 1 | L1101 | 4u7H | _SCHLIB_SparkleSplashy:INDC_4u7H/420mA | Inductor_SMD:L_0603_1608Metric | https://www.bourns.com/docs/product-datasheets/cwf1610.pdf |  | 420mA |  |  | 970mR | 4.7 µH Unshielded Inductor 420 mA 970mOhm 0603 (1608 Metric) |  |  |  |  |  |  | https://www.digikey.ca/en/products/detail/bourns-inc/CWF1610-4R7K/14644638 |  | L0603 |  | CWF1610-4R7K |  |  | CHECKED
38 | 1 | L1201 | 10uH | _SCHLIB_SparkleSplashy:INDC_10uH/300mA | Inductor_SMD:L_0805_2012Metric | https://product.tdk.com/en/system/files |  | 300mA |  |  | 680mR | 10 µH Shielded Multilayer Inductor 300 mA 680mOhm 0805 (2012 Metric) |  |  |  |  |  |  | https://www.digikey.ca/en/products/detail/tdk-corporation/MLZ2012M100HTD25/4743207 |  | L0805 |  | MLZ2012M100HTD25 |  |  | CHECKED
39 | 1 | LED301 | ORANGE | _SCHLIB_SparkleSplashy:LED_ORANGE_0402 | LED_SMD:LED_0402_1005Metric | https://media.digikey.com/pdf/Data%20Sheets/Harvatek%20PDFs/B2841UD--20D000614U1930.pdf |  |  |  |  |  | Orange 605nm LED Indication - Discrete 2V 0402 (1005 Metric) |  |  |  |  |  |  | https://www.digikey.ca/en/products/detail/harvatek-corporation/B2841UD-20D000614U1930/16729512 |  | LED0402 |  | B2841UD--20D000614U1930 |  |  | CHECKED |  |  | 2V
40 | 1 | LED302 | RED | _SCHLIB_SparkleSplashy:LED_RED_0402 | LED_SMD:LED_0402_1005Metric | https://media.digikey.com/pdf/Data%20Sheets/Harvatek%20PDFs/B2841USD-20D001014U1930.pdf |  |  |  |  |  | Red 624nm LED Indication - Discrete 2V 0402 (1005 Metric) |  |  |  |  |  |  | https://www.digikey.ca/en/products/detail/harvatek-corporation/B2841USD-20D001014U1930/16729514 |  | LED0402 |  | B2841USD-20D001014U1930 |  |  | CHECKED |  |  | 2V
41 | 2 | LED303, LED401 | AMBER | _SCHLIB_SparkleSplashy:LED_AMBER_0402 | LED_SMD:LED_0402_1005Metric | https://media.digikey.com/pdf/Data%20Sheets/Harvatek%20PDFs/B2841UY--20D000414U1930.pdf |  |  |  |  |  | Amber LED Indication - Discrete 2V 0402 (1005 Metric) |  |  |  |  |  |  | https://www.digikey.ca/en/products/detail/harvatek-corporation/B2841UY-20D000414U1930/16729525 |  | LED0402 |  | B2841UY--20D000414U1930 |  |  | CHECKED |  |  | 2V
42 | 3 | LED1201, LED1202, LED1203 | GREEN | _SCHLIB_SparkleSplashy:LED_GREEN_0402 | LED_SMD:LED_0402_1005Metric | https://media.digikey.com/pdf/Data%20Sheets/Harvatek%20PDFs/B2841NG--05D000514U1930.pdf |  |  |  |  |  | Green 529nm LED Indication - Discrete 2.8V 0402 (1005 Metric) |  |  |  |  |  |  | https://www.digikey.ca/en/products/detail/harvatek-corporation/B2841NG-05D000514U1930/16729536 |  | LED0402 |  | B2841NG--05D000514U1930 |  |  | CHECKED |  |  | 2V8
43 | 1 | LED1204 | BLUE | _SCHLIB_SparkleSplashy:LED_BLUE_0402 | LED_SMD:LED_0402_1005Metric | https://media.digikey.com/pdf/Data%20Sheets/Harvatek%20PDFs/B2841NB--20C001414U1930.pdf |  |  |  |  |  | Blue 470nm LED Indication - Discrete 3.3V 0402 (1005 Metric) |  |  |  |  |  |  | https://www.digikey.ca/en/products/detail/harvatek-corporation/B2841NB-20C001414U1930/16729522 |  | LED0402 |  | B2841NB--20C001414U1930 |  |  | CHECKED |  |  | 3V3
44 | 2 | MH1301, MH1302 | ~ | _SCHLIB_SparkleSplashy:MECH_MH | MountingHole:MountingHole_2.2mm_M2_DIN965_Pad_TopBottom
45 | 2 | Q1001, Q1002 | 2N7002AQ-7 | _SCHLIB_SparkleSplashy:MOSFET_2N7002AQ-7 | Package_TO_SOT_SMD:SOT-23 | https://www.diodes.com/assets/Datasheets/2N7002AQ.pdf |  |  |  |  |  | N-Channel 60 V 180mA (Ta) 370mW (Ta) Surface Mount SOT-23-3 |  |  |  |  |  |  | https://www.digikey.ca/en/products/detail/diodes-incorporated/2N7002AQ-7/6186937 |  | SOT-23-3 |  | 2N7002AQ-7 |  |  | CHECKED
46 | 25 | R301, R425, R427, R519, R601, R603, R604, R605, R606, R607, R608, R610, R611, R612, R613, R707, R708, R709, R1101, R1201, R1205, R1206, R1207, R1208, R1210 | 10KR_1/20W | _SCHLIB_SparkleSplashy:RES_10KR_1/20W | Resistor_SMD:R_0201_0603Metric | https://www.seielect.com/Catalog/SEI-RMCF_RMCP.pdf |  |  |  |  |  | 10 kOhms ±1% 0.05W, 1/20W Chip Resistor 0201 (0603 Metric) Thick Film |  |  |  |  |  |  | https://www.digikey.ca/en/products/detail/stackpole-electronics-inc/RMCF0201FT10K0/1714990 |  | R0201 |  | RMCF0201FT10K0 |  |  | CHECKED
47 | 7 | R302, R303, R304, R305, R306, R903, R905 | 3K3R_1/20W | _SCHLIB_SparkleSplashy:RES_3K3R_1/20W | Resistor_SMD:R_0201_0603Metric | https://www.seielect.com/Catalog/SEI-RMCF_RMCP.pdf |  |  |  |  |  | 3.3 kOhms ±1% 0.05W, 1/20W Chip Resistor 0201 (0603 Metric) Thick Film |  |  |  |  |  |  | https://www.digikey.ca/en/products/detail/stackpole-electronics-inc/RMCF0201FT3K30/4439996 |  | R0201 |  | RMCF0201FT3K30 |  |  | CHECKED
48 | 22 | R307, R308, R309, R310, R311, R406, R506, R801, R802, R803, R804, R901, R902, R1001, R1002, R1003, R1004, R1007, R1008, R1211, R1212, R1213 | 100R_1/20W | _SCHLIB_SparkleSplashy:RES_100R_1/20W | Resistor_SMD:R_0201_0603Metric | https://www.seielect.com/Catalog/SEI-RMCF_RMCP.pdf |  |  |  |  |  | 100 Ohms ±1% 0.05W, 1/20W Chip Resistor 0201 (0603 Metric) Thick Film |  |  |  |  |  |  | https://www.digikey.ca/en/products/detail/stackpole-electronics-inc/RMCF0201FT100R/1714988 |  | R0201 |  | RMCF0201FT100R |  |  | CHECKED
49 | 6 | R312, R313, R314, R408, R409, R426 | 499R_1/20W | _SCHLIB_SparkleSplashy:RES_499R_1/20W | Resistor_SMD:R_0201_0603Metric | https://www.seielect.com/Catalog/SEI-RMCF_RMCP.pdf |  |  |  |  |  | 499 Ohms ±1% 0.05W, 1/20W Chip Resistor 0201 (0603 Metric) Thick Film |  |  |  |  |  |  | https://www.digikey.ca/en/products/detail/stackpole-electronics-inc/RMCF0201FT499R/3906018 |  | R0201 |  | RMCF0201FT499R |  |  | CHECKED
50 | 4 | R315, R316, R418, R424 | 4K7R_1/20W | _SCHLIB_SparkleSplashy:RES_4K7R_1/20W | Resistor_SMD:R_0201_0603Metric | https://www.seielect.com/Catalog/SEI-RMCF_RMCP.pdf |  |  |  |  |  | 4.7 kOhms ±1% 0.05W, 1/20W Chip Resistor 0201 (0603 Metric) Thick Film |  |  |  |  |  |  | https://www.digikey.ca/en/products/detail/stackpole-electronics-inc/RMCF0201FT4K70/1715026 |  | R0201 |  | RMCF0201FT4K70 |  |  | CHECKED
51 | 10 | R401, R410, R411, R412, R413, R501, R502, R503, R504, R505 | 0R_1/20W | _SCHLIB_SparkleSplashy:RES_0R_1/20W | Resistor_SMD:R_0201_0603Metric | https://www.seielect.com/Catalog/SEI-RMCF_RMCP.pdf |  |  |  |  |  | 0 Ohms Jumper Chip Resistor 0201 (0603 Metric) Thick Film |  |  |  |  |  |  | https://www.digikey.ca/en/products/detail/stackpole-electronics-inc/RMCF0201ZT0R00/1756897 |  | R0201 |  | RMCF0201ZT0R00 |  |  | CHECKED
52 | 4 | R402, R403, R404, R405 | 49R9_1/20W | _SCHLIB_SparkleSplashy:RES_49R9_1/20W | Resistor_SMD:R_0201_0603Metric | https://www.seielect.com/Catalog/SEI-RMCF_RMCP.pdf |  |  |  |  |  | 49.9 Ohms ±1% 0.05W, 1/20W Chip Resistor 0201 (0603 Metric) Thick Film |  |  |  |  |  |  | https://www.digikey.ca/en/products/detail/stackpole-electronics-inc/RMCF0201FT49R9/1715030 |  | R0201 |  | RMCF0201FT49R9 |  |  | CHECKED
53 | 1 | R407 | 3K01R_1/20W | _SCHLIB_SparkleSplashy:RES_3K01R_1/20W | Resistor_SMD:R_0201_0603Metric | https://www.yageo.com/upload/media/product/productsearch/datasheet/rchip/PYu-RC_Group_51_RoHS_L_12.pdf |  |  |  |  |  | 3.01 kOhms ±1% 0.05W, 1/20W Chip Resistor 0201 (0603 Metric) Moisture Resistant Thick Film |  |  |  |  |  |  | https://www.digikey.ca/en/products/detail/yageo/RC0201FR-073K01L/3202405 |  | R0201 |  | RC0201FR-073K01L |  |  | CHECKED
54 | 23 | R414, R415, R416, R417, R420, R421, R422, R423, R509, R510, R511, R512, R609, R614, R615, R616, R617, R701, R702, R703, R704, R705, R706 | 27R4_1/20W | _SCHLIB_SparkleSplashy:RES_27R4_1/20W | Resistor_SMD:R_0201_0603Metric | https://www.yageo.com/upload/media/product/productsearch/datasheet/rchip/PYu-RC_Group_51_RoHS_L_12.pdf |  |  |  |  |  | 27.4 Ohms ±1% 0.05W, 1/20W Chip Resistor 0201 (0603 Metric) Moisture Resistant Thick Film |  |  |  |  |  |  | https://www.digikey.ca/en/products/detail/yageo/RC0201FR-0727R4L/5280413 |  | R0201 |  | RC0201FR-0727R4L |  |  | CHECKED
55 | 4 | R419, R513, R602, R618 | 100KR_1/20W | _SCHLIB_SparkleSplashy:RES_100KR_1/20W | Resistor_SMD:R_0201_0603Metric | https://industrial.panasonic.com/cdbs/www-data/pdf/RDA0000/AOA0000C304.pdf |  |  |  |  |  | 100 kOhms ±1% 0.05W, 1/20W Chip Resistor 0201 (0603 Metric) Automotive AEC-Q200 Thick Film |  |  |  |  |  |  | https://www.digikey.ca/en/products/detail/panasonic-electronic-components/ERJ-1GNF1003C/2036340 |  | R0201 |  | ERJ-1GNF1003C |  |  | CHECKED
56 | 4 | R507, R508, R518, R520 | 1MR_1/20W | _SCHLIB_SparkleSplashy:RES_1MR_1/20W | Resistor_SMD:R_0201_0603Metric | https://www.seielect.com/Catalog/SEI-RMCF_RMCP.pdf |  |  |  |  |  | 1 MOhms ±1% 0.05W, 1/20W Chip Resistor 0201 (0603 Metric) Thick Film |  |  |  |  |  |  | https://www.digikey.com/en/products/detail/stackpole-electronics-inc/RMCF0201FT1M00/3906028 |  | R0201 |  | RMCF0201FT1M00 |  |  | CHECKED
57 | 10 | R514, R515, R516, R517, R1103, R1104, R1202, R1203, R1204, R1209 | 1KR_1/20W | _SCHLIB_SparkleSplashy:RES_1KR_1/20W | Resistor_SMD:R_0201_0603Metric | https://www.seielect.com/Catalog/SEI-RMCF_RMCP.pdf |  |  |  |  |  | 1 kOhms ±1% 0.05W, 1/20W Chip Resistor 0201 (0603 Metric) Thick Film |  |  |  |  |  |  | https://www.digikey.ca/en/products/detail/stackpole-electronics-inc/RMCF0201FT1K00/1714998 |  | R0201 |  | RMCF0201FT1K00 |  |  | CHECKED
58 | 3 | R805, R1005, R1006 | 10R_1/20W | _SCHLIB_SparkleSplashy:RES_10R_1/20W | Resistor_SMD:R_0201_0603Metric | https://www.seielect.com/Catalog/SEI-RMCF_RMCP.pdf |  |  |  |  |  | 10 Ohms ±5% 0.05W, 1/20W Chip Resistor 0201 (0603 Metric) Thick Film |  |  |  |  |  |  | https://www.digikey.ca/en/products/detail/stackpole-electronics-inc/RMCF0201JT10R0/3906030 |  | R0201 |  | RMCF0201JT10R0 |  |  | CHECKED
59 | 1 | R806 | 1R_1/4W | _SCHLIB_SparkleSplashy:RES_1R_1/4W | Resistor_SMD:R_0402_1005Metric | https://www.koaspeer.com/pdfs/SG73P.pdf |  |  |  |  |  | 1 Ohms ±5% 0.25W, 1/4W Chip Resistor 0402 (1005 Metric) Automotive AEC-Q200, Pulse Withstanding Thick Film |  |  |  |  |  |  | https://www.digikey.ca/en/products/detail/koa-speer-electronics-inc/SG73P1EWTTP1R0J/14316746 |  | R0402 | SG73P1EWTTP1R0J |  |  |  | CHECKED
60 | 2 | R807, R808 | 680R_1/8W | _SCHLIB_SparkleSplashy:RES_680R_1/8W | Resistor_SMD:R_0805_2012Metric | https://www.seielect.com/Catalog/SEI-RMCF_RMCP.pdf |  |  |  |  |  | 680 Ohms ±5% 0.125W, 1/8W Chip Resistor 0805 (2012 Metric) Automotive AEC-Q200 Thick Film |  |  |  |  |  |  | https://www.digikey.ca/en/products/detail/stackpole-electronics-inc/RMCF0805JT680R/1757825 |  | R0805 |  | RMCF0805JT680R |  |  | CHECKED
61 | 1 | R904 | 820R_1/20W | _SCHLIB_SparkleSplashy:RES_820R_1/20W | Resistor_SMD:R_0201_0603Metric | https://industrial.panasonic.com/cdbs/www-data/pdf/RDA0000/AOA0000C304.pdf |  |  |  |  |  | 820 Ohms ±1% 0.05W, 1/20W Chip Resistor 0201 (0603 Metric) Automotive AEC-Q200 Thick Film |  |  |  |  |  |  | https://www.digikey.ca/en/products/detail/panasonic-electronic-components/ERJ-1GNF8200C/2036102 |  | R0201 |  | ERJ-1GNF8200C |  |  | CHECKED
62 | 1 | R906 | 4K7R_1W | _SCHLIB_SparkleSplashy:RES_4K7R_1W | Resistor_SMD:R_MELF_MMB-0207 | https://www.seielect.com/catalog/sei-mlfa.pdf |  |  |  |  |  | 4.7 kOhms ±1% 1W Chip Resistor MELF, 0207 Automotive AEC-Q200 Metal Film |  |  |  |  |  |  | https://www.digikey.ca/en/products/detail/stackpole-electronics-inc/MLFA1FTC4K70/8571818 |  | MELF |  | MLFA1FTC4K70 |  |  | CHECKED
63 | 2 | R1009, R1011 | 47KR_1/20W | _SCHLIB_SparkleSplashy:RES_47KR_1/20W | Resistor_SMD:R_0201_0603Metric | https://www.seielect.com/Catalog/SEI-RMCF_RMCP.pdf |  |  |  |  |  | 47 kOhms ±5% 0.05W, 1/20W Chip Resistor 0201 (0603 Metric) Thick Film |  |  |  |  |  |  | https://www.digikey.ca/en/products/detail/stackpole-electronics-inc/RMCF0201JT47K0/1758250 |  | R0201 |  | RMCF0201JT47K0 |  |  | CHECKED
64 | 2 | R1010, R1012 | 1KR_1W | _SCHLIB_SparkleSplashy:RES_1KR_1W | Resistor_SMD:R_MELF_MMB-0207 | https://www.seielect.com/catalog/sei-mlfa.pdf |  |  |  |  |  | 1 kOhms ±1% 1W Chip Resistor MELF, 0207 Automotive AEC-Q200 Metal Film |  |  |  |  |  |  | https://www.digikey.ca/en/products/detail/stackpole-electronics-inc/MLFA1FTC1K00/8571812 |  | MELF |  | MLFA1FTC1K00 |  |  | CHECKED
65 | 1 | R1102 | 0.1R_1/2W | _SCHLIB_SparkleSplashy:RES_0.1R_1/2W | Resistor_SMD:R_0805_2012Metric | https://industrial.panasonic.com/cdbs/www-data/pdf/RDN0000/AOA0000C313.pdf |  |  |  |  |  | 100 mOhms ±1% 0.5W, 1/2W Chip Resistor 0805 (2012 Metric) Automotive AEC-Q200, Current Sense Thick Film |  |  |  |  |  |  | https://www.digikey.ca/en/products/detail/panasonic-electronic-components/ERJ-6DSFR10V/6004391 |  | R0805 |  | ERJ-6DSFR10V |  |  | CHECKED
66 | 1 | R1214 | 93K1R_1/20W | _SCHLIB_SparkleSplashy:RES_93K1R_1/20W | Resistor_SMD:R_0201_0603Metric | https://www.seielect.com/Catalog/SEI-RMCF_RMCP.pdf |  |  |  |  |  | 93.1 kOhms ±1% 0.05W, 1/20W Chip Resistor 0201 (0603 Metric) Thick Film |  |  |  |  |  |  | https://www.digikey.ca/en/products/detail/stackpole-electronics-inc/RMCF0201FT93K1/5965937 |  | R0201 |  | RMCF0201FT93K1 |  |  | CHECKED
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

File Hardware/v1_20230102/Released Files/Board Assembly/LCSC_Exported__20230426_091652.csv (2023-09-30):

LCSC Part Number | Manufacture Part Number | Manufacturer | Customer NO. | Package | Description | RoHS | Order Qty. | Min\Mult Order Qty. | Unit Price | Order Price
C131223 | 16-213/BHC-AN1P2/3T | Everlight Elec |  | 402 | blue 0402 Light Emitting Diodes (LED) ROHS | YES | 10 | 1\10 | 0.0378 | 0.38
C138139 | RC0201FR-0747KL | YAGEO |  | 201 | 50mW Thick Film Resistors ±1% 47kΩ 0201 Chip Resistor - Surface Mount ROHS | YES | 100 | 100\100 | 0.001 | 0.1
C843835 | CRCW0201100KFKED | Vishay Intertech |  | 201 | 50mW Thick Film Resistors ±1% 100kΩ 0201 Chip Resistor - Surface Mount ROHS | YES | 50 | 50\50 | 0.0086 | 0.43
C161411 | GRM0335C1H1R0WA01D | Murata Electronics |  | 201 | 50V 1pF C0G 0201 Multilayer Ceramic Capacitors MLCC - SMD/SMT ROHS | YES | 50 | 50\50 | 0.0103 | 0.52
C161477 | GRM033R61E102KA01D | Murata Electronics |  | 201 | 25V 1nF X5R ±10% 0201 Multilayer Ceramic Capacitors MLCC - SMD/SMT ROHS | YES | 100 | 1\100 | 0.0026 | 0.26
C2889502 | 0805 ±1% 680Ω | VO |  | 805 | 125mW Thick Film Resistors ±1% 680Ω 0805 Chip Resistor - Surface Mount ROHS | YES | 100 | 100\100 | 0.0019 | 0.19
C171936 | WR02X100JAL | Walsin Tech Corp |  | 201 | 50mW Thick Film Resistors ±5% 10Ω 0201 Chip Resistor - Surface Mount ROHS | YES | 100 | 100\100 | 0.0011 | 0.11
C2979784 | MMB02070C1001FB200 | Vishay Intertech |  | MELF | 1W Thin Film Resistor ±1% 1kΩ MELF Chip Resistor - Surface Mount ROHS | YES | 5 | 5\5 | 0.0684 | 0.34
C161372 | GRM0335C1E120JA01D | Murata Electronics |  | 201 | 25V 12pF C0G ±5% 0201 Multilayer Ceramic Capacitors MLCC - SMD/SMT ROHS | YES | 100 | 100\100 | 0.0025 | 0.25
C86044 | GRM21BR72A104KAC4L | Murata Electronics |  | 805 | 100V 100nF X7R ±10% 0805 Multilayer Ceramic Capacitors MLCC - SMD/SMT ROHS | YES | 20 | 20\20 | 0.0288 | 0.58
C2969937 | LD56100DPU33R | STMicroelectronics |  | DFN-8(1.2x1.6) | 1A null 12V~12V positive 5.5V DFN-8(1.2x1.6) Linear Voltage Regulators (LDO) ROHS | YES | 4 | 1\1 | 0.856 | 3.42
C226534 | AC0201FR-073K3L | YAGEO |  | 201 | 50mW Thick Film Resistors ±1% 3.3kΩ 0201 Chip Resistor - Surface Mount ROHS | YES | 100 | 100\100 | 0.0017 | 0.17
C318540 | CL03A105MO3NRNC | Samsung Electro-Mechanics |  | 201 | 16V 1uF X5R ±20% 0201 Multilayer Ceramic Capacitors MLCC - SMD/SMT ROHS | YES | 10 | 10\10 | 0.0461 | 0.46
C880757 | 0201B103K250CT | Walsin Tech Corp |  | 201 | 25V 10nF X7R ±10% 0201 Multilayer Ceramic Capacitors MLCC - SMD/SMT ROHS | YES | 50 | 50\50 | 0.0147 | 0.74
C1952739 | F980J476MMA | Kyocera AVX |  | 603 | 47uF 6.3V 10Ω@100kHz ±20% 0603 Tantalum Capacitors ROHS | YES | 20 | 1\1 | 0.3023 | 6.05
C207019 | 0805L010/24YR | Littelfuse |  | 805 | 24V 100mA 100A 300mA 0805 Resettable Fuses ROHS | YES | 10 | 5\5 | 0.0695 | 0.7
C89334 | 2450AT18A100E | Johanson Dielectrics |  | 1206 | 0.5dBi 2.4GAntenna 2.4GHz 2W 1206 Antennas ROHS | YES | 3 | 1\1 | 0.4455 | 1.34
C2839439 | CL03A225MQ3CSNC | Samsung Electro-Mechanics |  | 201 | 6.3V 2.2uF 0201 Multilayer Ceramic Capacitors MLCC - SMD/SMT ROHS | YES | 60 | 20\20 | 0.0182 | 1.09
C474863 | RC0201FR-0793K1L | YAGEO |  | 201 | 50mW Thick Film Resistors ±1% 93.1kΩ 0201 Chip Resistor - Surface Mount ROHS | YES | 100 | 100\100 | 0.0007 | 0.07
C138165 | RC0201FR-071KL | YAGEO |  | 201 | 50mW Thick Film Resistors ±1% 1kΩ 0201 Chip Resistor - Surface Mount ROHS | YES | 100 | 100\100 | 0.0009 | 0.09
C2932476 | CL21A106KBYQNNE | Samsung Electro-Mechanics |  | 805 | 50V 10uF X5R ±10% 0805 Multilayer Ceramic Capacitors MLCC - SMD/SMT ROHS | YES | 5 | 1\5 | 0.1171 | 0.59
C474642 | RC0201FR-073K01L | YAGEO |  | 201 | 50mW Thick Film Resistors ±1% 3.01kΩ 0201 Chip Resistor - Surface Mount ROHS | YES | 100 | 1\100 | 0.0011 | 0.11
C2844318 | C0201X6S104K160NT | SANYEAR |  | 201 | 16V 100nF 0201 Multilayer Ceramic Capacitors MLCC - SMD/SMT ROHS | YES | 100 | 50\50 | 0.0072 | 0.72
C161416 | GRM0335C1H1R8WA01D | Murata Electronics |  | 201 | 50V 1.8pF C0G 0201 Multilayer Ceramic Capacitors MLCC - SMD/SMT ROHS | YES | 50 | 50\50 | 0.008 | 0.4
C364993 | HPCR0402F330RK9 | Resistor.Today |  | 402 | 100mW Thick Film Resistors ±1% 330Ω 0402 Chip Resistor - Surface Mount ROHS | YES | 100 | 1\100 | 0.0063 | 0.63
C295786 | RC0201FR-071ML | YAGEO |  | 201 | 50mW Thick Film Resistors ±1% 1MΩ 0201 Chip Resistor - Surface Mount ROHS | YES | 100 | 100\100 | 0.0009 | 0.09
C716999 | ERJ1GN0R00C | PANASONIC |  | 201 | 50mW Thick Film Resistors 0Ω 0201 Chip Resistor - Surface Mount ROHS | YES | 100 | 100\100 | 0.007 | 0.7
C130722 | NCD0402C1 | Foshan NationStar Optoelectronics |  | 402 | Green/Yellow-Green 0402 Light Emitting Diodes (LED) ROHS | YES | 20 | 20\20 | 0.0359 | 0.72
C29276 | AQY212EHAX | PANASONIC |  | SOP-4-2.54mm | 1 Form A(SPST-NO) 1.25V 60V 0.85Ω 550mA AC,DC SOP-4-2.54mm Solid State Relays - MOS Output (PhotoMOS) ROHS | YES | 3 | 1\1 | 0.856 | 2.57
C965400 | NQ01WMF1000TEE | UNI-ROYAL(Uniroyal Elec) |  | 201 | 50mW ±1% 100Ω 0201 Chip Resistor - Surface Mount ROHS | YES | 100 | 100\100 | 0.0027 | 0.27
C3000902 | CRCW02014K70FKED | Vishay Intertech |  | 201 | 50mW Thick Film Resistors ±1% 4.7kΩ 0201 Chip Resistor - Surface Mount ROHS | YES | 50 | 50\50 | 0.0089 | 0.45
C226565 | AC0201FR-0749R9L | YAGEO |  | 201 | 50mW Thick Film Resistors ±1% 49.9Ω 0201 Chip Resistor - Surface Mount ROHS | YES | 100 | 100\100 | 0.0018 | 0.18
C71911 | 16-213/SDRC/S530-A3/TR8 | Everlight Elec |  | 402 | 639nm~639nm Red 0402 Light Emitting Diodes (LED) ROHS | YES | 10 | 10\10 | 0.0505 | 0.51
C507855 | 2N7002AQ-7 | Diodes Incorporated |  | SOT-23 | 60V 180mA 5Ω@10V,115mA 370mW N Channel SOT-23 MOSFETs ROHS | YES | 10 | 1\10 | 0.0325 | 0.33
C907680 | W25N01GVZEIG | Winbond Elec |  | WSON-8-EP(6.1x8) | WSON-8-EP(6.1x8) NAND FLASH ROHS | YES | 3 | 1\1 | 1.2075 | 3.62
C86277 | GRM188R61C106MA73D | Murata Electronics |  | 603 | 16V 10uF X5R ±20% 0603 Multilayer Ceramic Capacitors MLCC - SMD/SMT ROHS | YES | 10 | 10\10 | 0.0425 | 0.43
C423620 | 0201WMF274JTEE | UNI-ROYAL(Uniroyal Elec) |  | 201 | 50mW Thick Film Resistors ±1% 27.4Ω 0201 Chip Resistor - Surface Mount ROHS | YES | 100 | 1\100 | 0.0005 | 0.05
C2686246 | JMK105BBJ475MVMF | Taiyo Yuden |  | 402 | 6.3V 4.7uF 0402 Multilayer Ceramic Capacitors MLCC - SMD/SMT ROHS | YES | 20 | 20\20 | 0.0261 | 0.52
C273599 | TJ-S1005SW4TGLC0A-A5 | TOGIALED |  | 402 | Orange 0402 Light Emitting Diodes (LED) ROHS | YES | 20 | 10\10 | 0.0465 | 0.93
C2071056 | AP63205WU-7 | Diodes Incorporated |  | TSOT-26-6 | Step-down type Fixed 2A 5V 3.8V~32V TSOT-26-6 DC-DC Converters ROHS | YES | 6 | 1\1 | 0.4901 | 2.94
C713497 | ERJ1GNF4990C | PANASONIC |  | 201 | 50mW Thick Film Resistors ±1% 499Ω 0201 Chip Resistor - Surface Mount ROHS | YES | 50 | 50\50 | 0.0114 | 0.57
C170195 | WR02X1002FAL | Walsin Tech Corp |  | 201 | 50mW Thick Film Resistors ±1% 10kΩ 0201 Chip Resistor - Surface Mount ROHS | YES | 100 | 100\100 | 0.0007 | 0.07
C383389 | MLZ1005M2R2WT000 | TDK |  | 402 | 350mA 2.2uH ±20% 60mA 550mΩ 0402 Inductors (SMD) ROHS | YES | 10 | 10\10 | 0.0621 | 0.62
C404749 | MLZ2012M100HTD25 | TDK |  | 805 | 300mA 10uH ±20% 200mA 680mΩ 0805 Inductors (SMD) ROHS | YES | 5 | 1\5 | 0.1125 | 0.56
C2675856 | SN74LVC2G17DRYR | Texas Instruments |  | SON-6(1x1.5) | Schmitt Trigger 1 32mA 1.65V~5.5V 32mA SON-6(1x1.5) Buffer/Driver/Transceiver ROHS | YES | 10 | 1\1 | 0.2641 | 2.64
C5266012 | CR0201FH2402G | LIZ Elec |  | 201 | ±1% 24kΩ 0201 Chip Resistor - Surface Mount ROHS | YES | 100 | 100\100 | 0.001 | 0.1
C5142541 | TCC0201X7R104K6R3ZT | CCTC |  | 201 | 6.3V 100nF X7R 0201 Multilayer Ceramic Capacitors MLCC - SMD/SMT ROHS | YES | 100 | 1\100 | 0.001 | 0.1
C542290 | 50SVPK10M | PANASONIC |  | SMD | 50V 10uF Polymer ±20% 80mΩ 27.5mA@120Hz SMD Solid Capacitors ROHS | YES | 5 | 1\1 | 0.7446 | 3.72
C2041435 | L-07C2N7SV6T | Johanson Dielectrics |  | 402 | 300mA 2.7nH 170mΩ 0402 Inductors (SMD) ROHS | YES | 20 | 20\20 | 0.0273 | 0.55
C2759531 | HP02WAF100KTCE | UNI-ROYAL(Uniroyal Elec) |  | 402 | 100mW ±1% 1Ω 0402 Chip Resistor - Surface Mount ROHS | YES | 50 | 1\50 | 0.0039 | 0.2
C720289 | LMERW330F4K70Q9L | Resistor.Today |  | MELF | 330mW Metal Film Resistors ±1% 4.7kΩ MELF Chip Resistor - Surface Mount ROHS | YES | 20 | 20\20 | 0.0372 | 0.74
C308920 | TPSB336M016R0350 | Kyocera AVX |  | CASE-B-3528 | 33uF 16V 350mΩ@100kHz ±20% CASE-B-3528 Tantalum Capacitors ROHS | YES | 6 | 1\1 | 0.2482 | 1.49
C308915 | TPSA226K006R0500 | Kyocera AVX |  | CASE-A-3216 | 22uF 6.3V 500mΩ@100kHz ±10% CASE-A-3216 Tantalum Capacitors ROHS | YES | 10 | 1\1 | 0.1396 | 1.4
C965350 | NQ01WMF8200TEE | UNI-ROYAL(Uniroyal Elec) |  | 201 | 50mW ±1% 820Ω 0201 Chip Resistor - Surface Mount ROHS | YES | 100 | 100\100 | 0.0012 | 0.12
C694489 | CGA1A2X7R1H471KT0YNN | TDK |  | 201 | 50V 470pF X7R ±10% 0201 Multilayer Ceramic Capacitors MLCC - SMD/SMT ROHS | YES | 20 | 20\20 | 0.0356 | 0.71
C102618 | AP3012KTR-G1 | Diodes Incorporated |  | SOT-23-5 | boost converterType Adjustable 1.25V~29V 500mA 2.6V~16V SOT-23-5 DC-DC Converters ROHS | YES | 5 | 5\5 | 0.1178 | 0.59

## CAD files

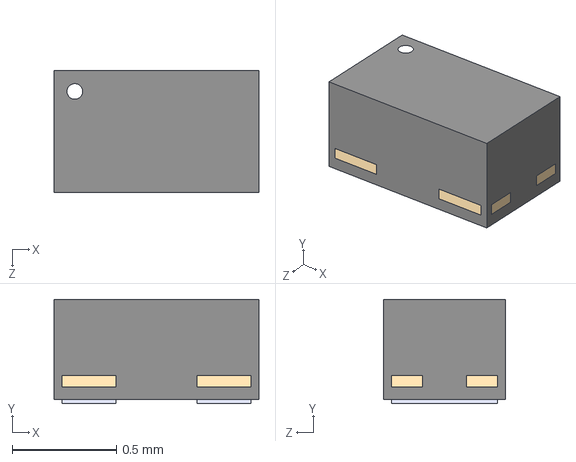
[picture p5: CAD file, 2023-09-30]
Hardware/v1_20230102/Design Files/_HW_SparkleSplashy/3D Parts/PMEG2005AEL_315.step
0.985 x 0.5 x 0.585 mm

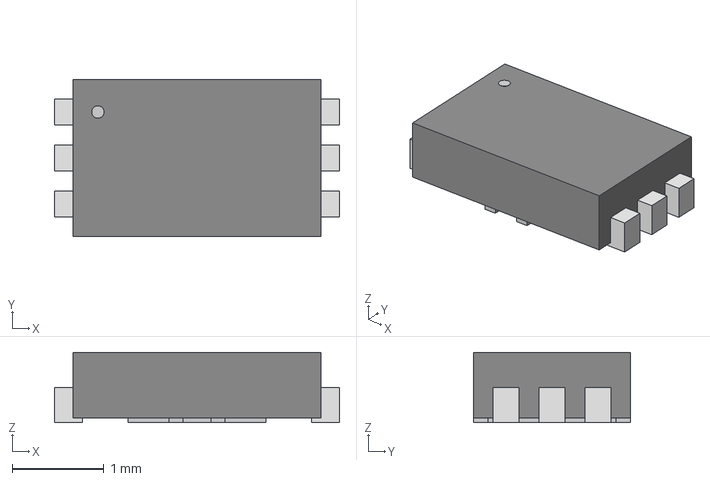
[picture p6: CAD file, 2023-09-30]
Hardware/v1_20230102/Released Files/Source Files/3D Parts/HVSOF6_ROM.step
3.10 x 1.70 x 0.765 mm

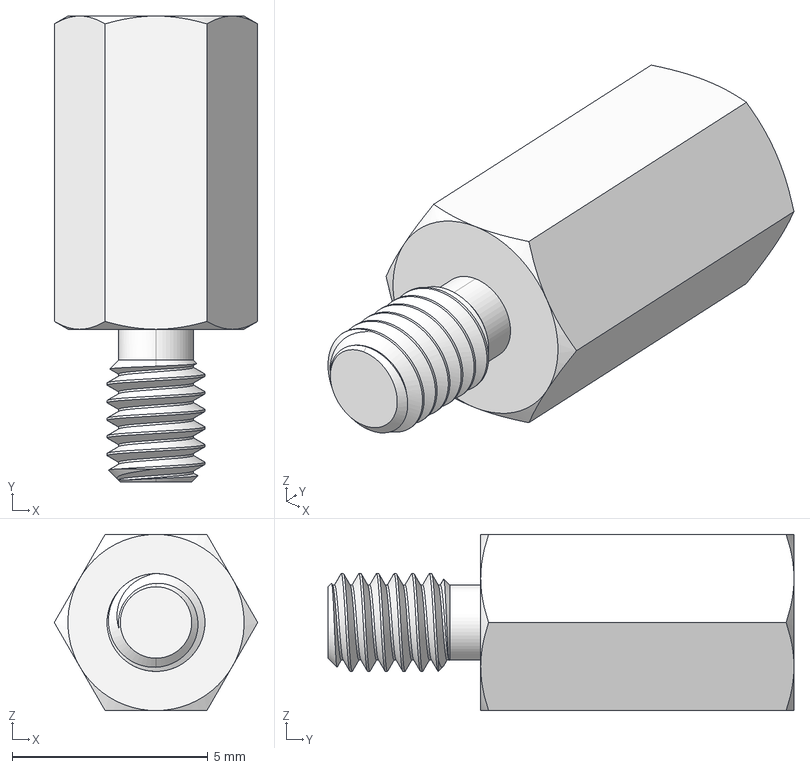
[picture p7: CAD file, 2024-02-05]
CAD model/_Sub_Mechanical_Project/v1_20240204/Design Folder/_MECH_SparkleSplashy/Hex Standoff, Male-Female, M2.5, L8mm.stp
5.20 x 11.9 x 4.50 mm

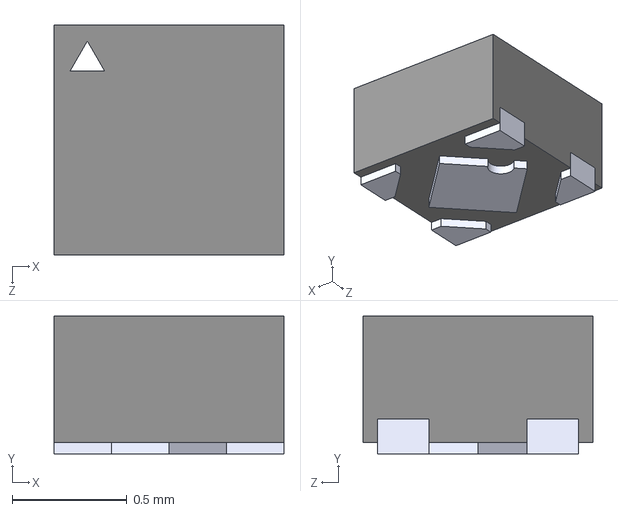
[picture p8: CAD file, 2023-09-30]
Hardware/v1_20230102/Design Files/_HW_SparkleSplashy/3D Parts/MIC5524-3.3YMT-T5.step
1.00 x 0.6 x 1.00 mm

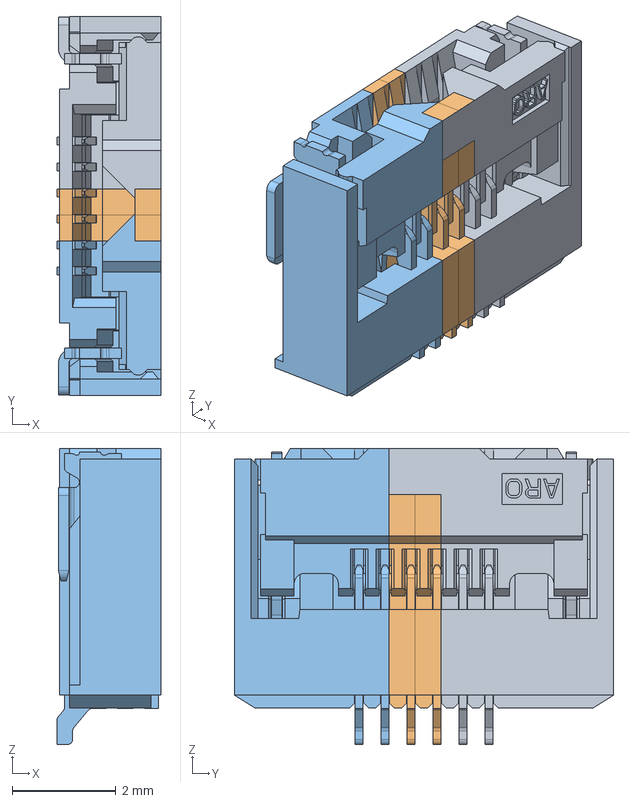
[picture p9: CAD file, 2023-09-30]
Hardware/v1_20230102/Released Files/Source Files/3D Parts/F305-1A7H1-11006-E100--3DModel-STEP-533217.STEP
2.00 x 7.30 x 5.70 mm
F305_L
F305_M x 2
F305_R

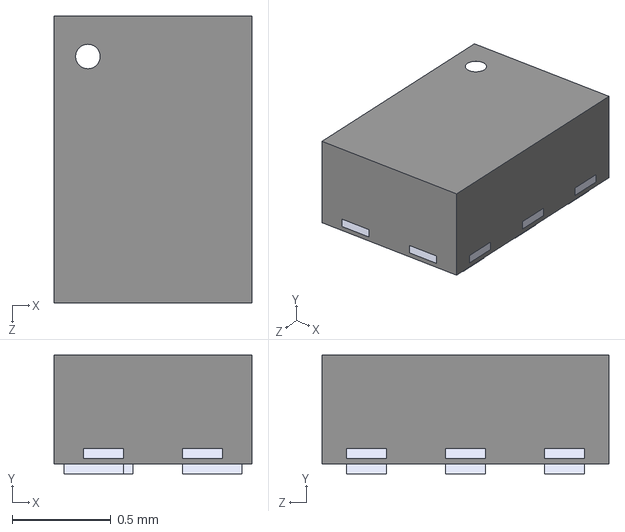
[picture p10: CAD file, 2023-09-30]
Hardware/v1_20230102/Design Files/_HW_SparkleSplashy/3D Parts/PSON50P145X100X60-6N.step
1.00 x 0.6 x 1.45 mm

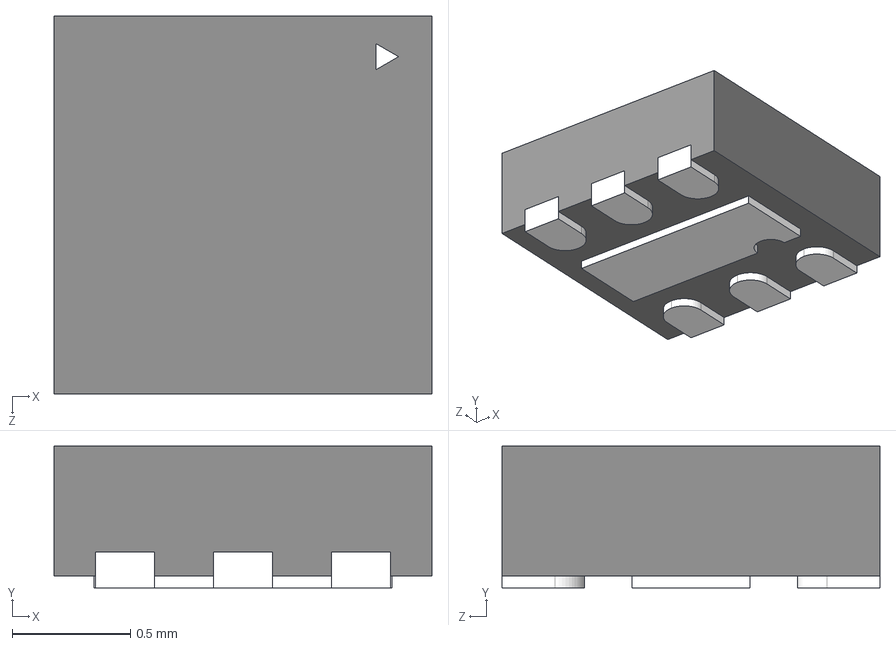
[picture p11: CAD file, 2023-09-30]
Hardware/v1_20230102/Released Files/Source Files/3D Parts/SON50P160X160X60-7N.step
1.60 x 0.6 x 1.60 mm

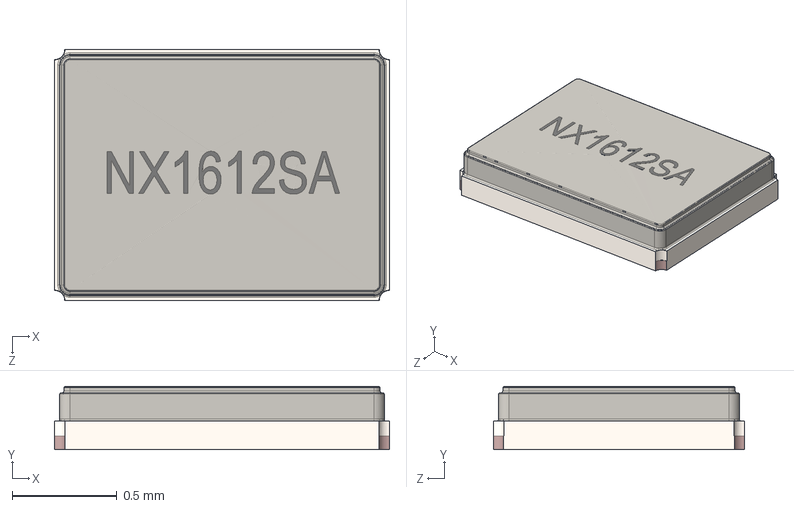
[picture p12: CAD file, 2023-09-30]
Hardware/v1_20230102/Design Files/_HW_SparkleSplashy/3D Parts/User Library-NX1612SA.step
1.60 x 0.302 x 1.20 mm

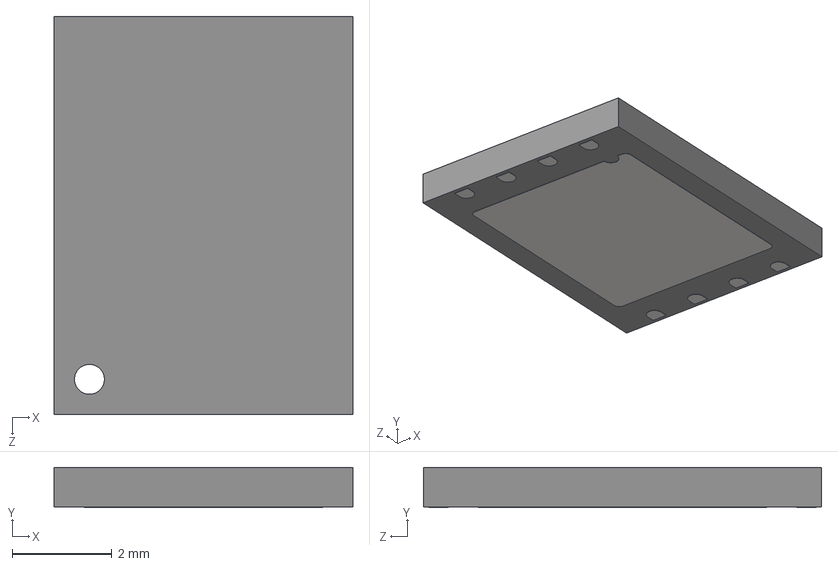
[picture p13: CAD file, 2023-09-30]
Hardware/v1_20230102/Released Files/Source Files/3D Parts/User Library-WSON8x6.step
6.00 x 0.81 x 8.00 mm

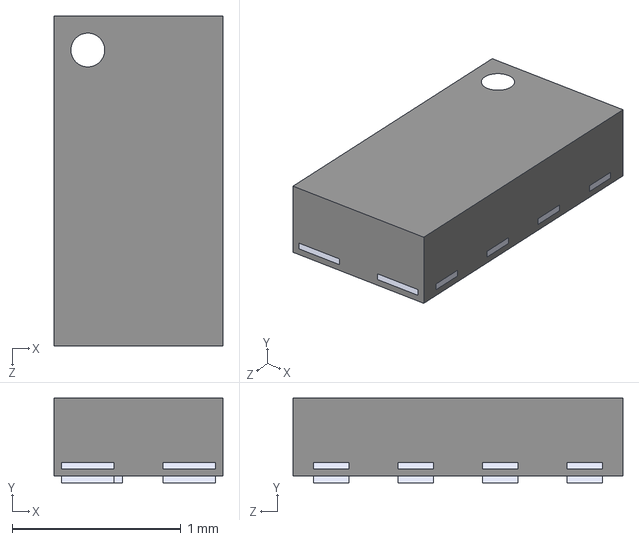
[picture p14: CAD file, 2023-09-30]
Hardware/v1_20230102/Design Files/_HW_SparkleSplashy/3D Parts/PSON50P195X100X50-8N.step
1.00 x 0.5 x 1.95 mm

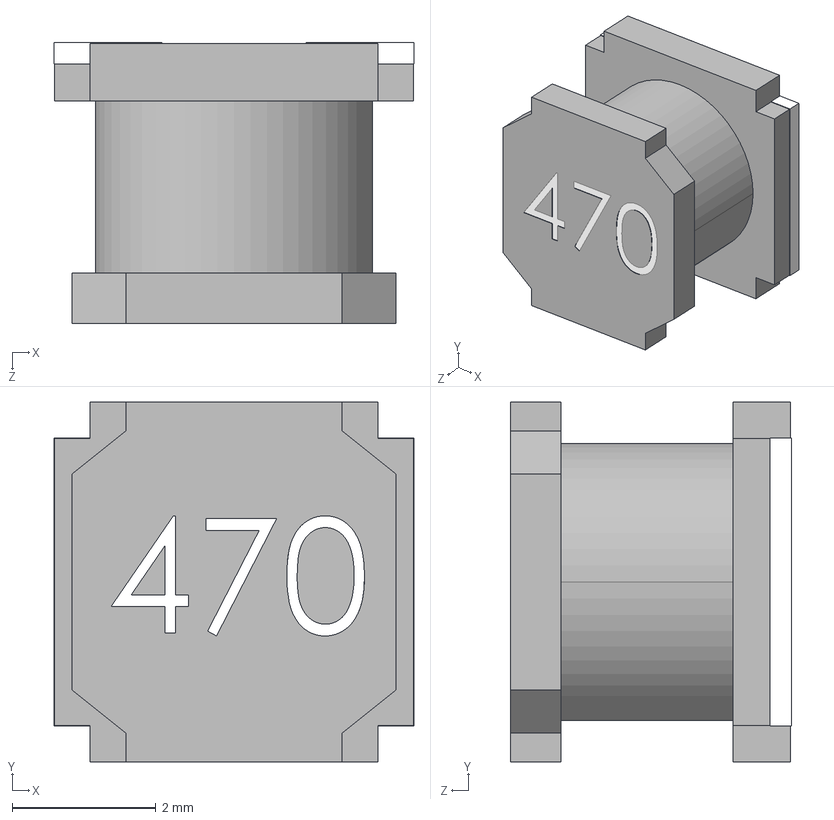
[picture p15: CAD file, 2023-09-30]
Hardware/v1_20230102/Released Files/Source Files/3D Parts/User Library-TYS5040.step
5.00 x 5.00 x 3.90 mm

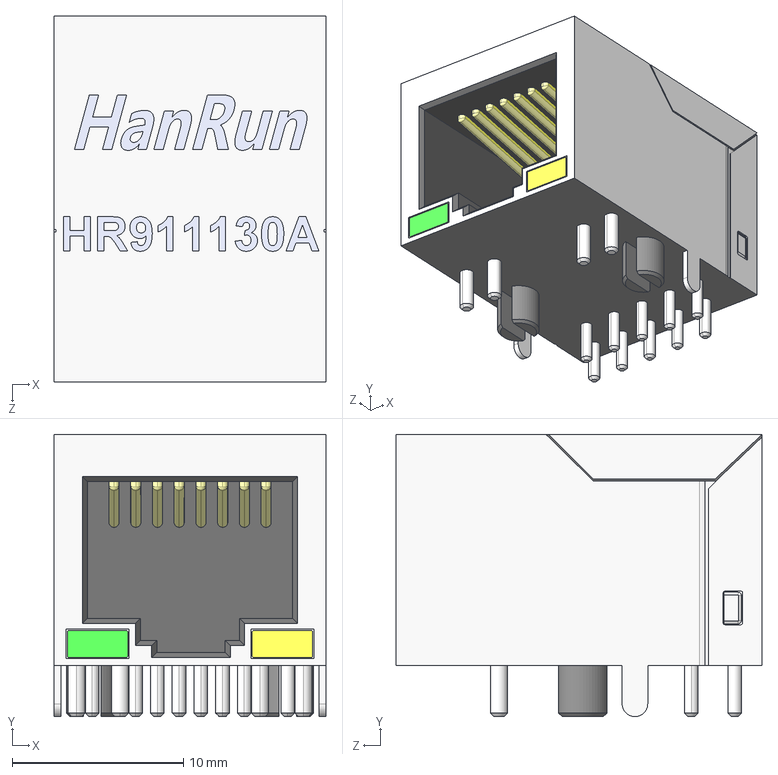
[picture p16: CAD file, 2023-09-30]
Hardware/v1_20230102/Released Files/Source Files/3D Parts/User Library-HR911130A.step
15.9 x 16.5 x 21.4 mm

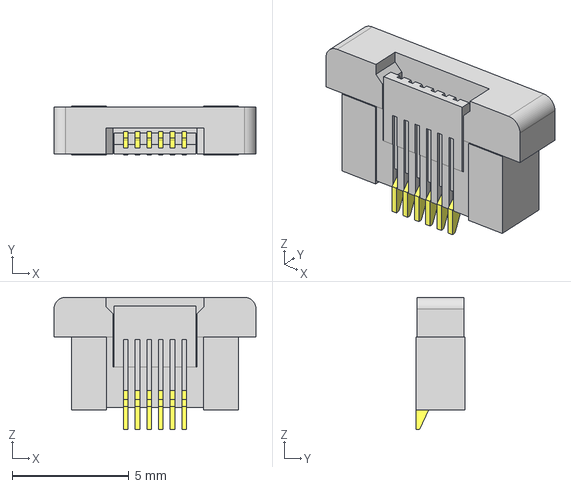
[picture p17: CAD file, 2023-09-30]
Hardware/v1_20230102/Design Files/_HW_SparkleSplashy/3D Parts/ZF5S-06-01-T-WT.step
8.65 x 2.10 x 5.67 mm
C-297-06-01_pins
ZF5S-06-01-WT_socket

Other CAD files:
CAD model/_Sub_Mechanical_Project/v1_20240204/Design Folder/_MECH_SparkleSplashy/M2.5 Nut.SLDPRT
CAD model/_Sub_Mechanical_Project/v1_20240204/Design Folder/_MECH_SparkleSplashy/User Library-M2_5-A4-socket-cap-screw-din 912.step
Hardware/v1_20230102/Design Files/_HW_SparkleSplashy/3D Parts/LAN8720A-CP.step
Hardware/v1_20230102/Design Files/_HW_SparkleSplashy/3D Parts/PSON50P145X100X54-6N.step
Hardware/v1_20230102/Design Files/_HW_SparkleSplashy/3D Parts/User Library-CDRH3D23.step
Hardware/v1_20230102/Design Files/_HW_SparkleSplashy/3D Parts/User Library-DFN-8 2x2.step
Hardware/v1_20230102/Design Files/_HW_SparkleSplashy/3D Parts/User Library-DO-214BA.step
Hardware/v1_20230102/Design Files/_HW_SparkleSplashy/3D Parts/User Library-FPC-40-2.step
Hardware/v1_20230102/Design Files/_HW_SparkleSplashy/3D Parts/User Library-XFDFN-8E.igs
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

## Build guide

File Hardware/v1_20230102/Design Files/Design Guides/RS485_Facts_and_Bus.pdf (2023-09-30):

# RS485 Facts and Bus

Michael Hungershausen, www.iftools.com

October 2019

he following document collects the most important facts about the RS485 standard together with background information (▲) to understand what is behind these features. This information leads to guidelines (►) for a correct connection of the complete system. Some hints to connection traps (▼) complement the chapters.
Read the chapters in their sequence as they are relating to each other.
A summary for the connection guidelines and some bus schematics conclude this article.

### Signal type

The RS485 lines are complementary differential signals (A+, B-). A positive voltage difference between A+ and B- is assigned to logical ‘1’ (Idle), a negative voltage to ’0’. The bus is called 2-wire bus.
▲ In this way disturbances from the environment, which enter both lines at the same time, shift the line levels simultaneously and do not change the difference voltage.
The receivers are designed for voltage shifts in the range of -7V to +12V, the common mode range, which is ±9.5V to the middle of the RS485 bus voltage range of 0 to +5V.
The logical value can still be correctly decoded when the bus gets a shifting impact.
- To achieve this optimally the data wires of equal length have to be twisted so that irradiations enter both wires equally. A shielded bus cable further helps to keep out disturbances, especially in rough environment.
▼ Make sure that you place the bus in an as clean as possible environment. For example placing it side by side with a motor supply cable will cause undefined errors because of the high and changing electromagnetic field.

### Ground line

Because only the voltage differences are measured the ground line could be omitted.
▲ This only works for ideal environment. If equalizing currents arise they have to flow through the data lines instead of the balancing ground line. These currents can come from long buses, different power supplies for the devices, disturbances from outside and many other reasons. Undefined errors are the result, especially for higher bit rates.
In addition the receivers internally need a ground to decode the signal, even if it is a voltage difference. If no ground line is present they generate an unstable and fluctuating virtual ground which is different to a real ground.
- The recommendation is: Don’t ‘optimize’ the ground wire away, connect all bus participants with ground, make the 2-wire bus a 3-wire one. If you need a floating bus device use a RS485 isolator.
▼ Some devices do not offer a ground connection for whatever reason. Consider to replace them for other types or connect to their internal ground.

### Bus topology

The bus wires must be routed from device to device without significant stubs. It is not recommended to use a straight backbone with more or less long branch lines.
▲ At the end of every stub wire the signal is reflected and runs back to the main bus. These reflections are delayed depending on the length of the stub and will interfere with the original signal. The results are distorted signals and therewith unclear bits.
- Wire the bus from device to device. There must be only two ends, no branch lines.
▼ If you split the bus into segments by adding repeaters or isolators make sure that every segment has its own correct topology.
Especially the termination and biasing resistors (see next chapters) have to be doubled.

### Bus termination

Both bus ends have to be terminated through one resistor each between A+ and B-.
▲ As mentioned in the ‘bus topology’ part the signal is reflected at the end of the bus wires

T

and runs back and forth again on the line, causing distorted signals. To avoid this the signal reflections must be damped at both wire ends. This is done by ‘burning’ the energy in resistors between the data lines.
The standard value is 120Ω for each resistor, resulting in 60Ω total resistance between both data lines. The power rating is 0.25W.
Some devices offer a switch to enable a termination resistor for use in case they are the first or last device on the bus.
- Terminate both bus ends with 120Ω/0.25W resistors between the data lines.
▼ Make sure that exactly two resistors are wired and no device between the ends has its bus termination unintentionally activated, e.g. a former bus end device. That would result in high bus load and collapsing bus voltages by overcharged bus drivers.
Measure the resistance when the bus is off.

### Voltage swing

The differential voltage (swing) is +200mV up to +5V and -200mV downto -5V per definition. The value between -200mV and +200mV is undefined.
▲ When the voltages are too small the receiver chips will not return a reliable logical value, especially in a rough environment. These small voltages occur when the bus is undriven and inactive when no device is sending, all are listening on the bus.
So this inactive bus condition needs a special treatment, the bus biasing, see the next part. In addition small active bus voltages are very failure-prone and give the hint, that the bus is not correctly designed with too much load.
- Examine the bus voltages with a scope and make sure, that the active bus difference voltages are high enough. Voltages above +2V and below -2V are recommended.
▼ Small voltage swings (sometimes only from one weak device) are a hint that the bus is overloaded. Consider splitting the bus into segments with repeaters.

### Bus biasing

A bus pull up and down resistor is necessary to set the voltage when the bus is floating (no sender is active).
▲ The bus voltages in the inactive state has to be set for some reasons. The main reason is that the receivers do not detect voltages between ±200mV reliably as fail save ’1’. Both data lines are nearly shorted through the two 120Ω resistors with a voltage difference of 0V.

The detected logic level must be equal to the idle state which is logical ’1’. If instead a logical ’0’ would be read it would lead to a break condition and no start bit can be recognized, because the first falling edge would not be seen.
So the bus voltage must be set to a value a bit greater than +200mV. This is done by adding a pull up of 680Ω from A+ to +5V and a pull down of 680Ω from B- to ground. Together with the 2*120Ω termination resistors the resulting voltage is a bit over +200mV.
Another reason for the biasing (with equal resistors) is that the bus is fixed in the middle of the 5V working range at 2.5V. In this way the level shift range is optimally placed in the common mode range, see chapter ‘signal type’. In the floating state the bus sensitivity for disturbances is much higher than in the actively driven state.
- Add a 680Ω resistor anywhere from A+ to +5V and 680Ω from B- to ground. For a long distance bus use 1300Ω resistors instead, but on both ends of the bus, for a more smooth current distribution.
▼ The biasing is often neglected and omitted. This works until the first inexplicable error occurs.
Some devices have internal pull up and down resistors in the kΩ range. And the input resistors of the devices also change the levels. So measure the rest voltage when the bus is quiet and adapt the resistor values if necessary.

### Bus length

The maximum bus length must fit to the maximum bit rate. If the rate is too high the bus must be divided into segments.
▲ The twisted bus cable has a quite high impedance and capacitance which lead to distorted signal edges and bits. The longer the bus the lower the maximum bit rate can be.
Bit rates of up to 100kbps can be transferred up to 1km in an ideal environment. For higher bit rates the length decreases fast, consult respective tables. To have more immunity simply half the mentioned bus length for a given bit rate.
- Measure the real bus length and consider using repeaters to reinforce the signal and improve the quality if the bus is too long for the given maximum bit rate.
▼ Especially rough environment can decrease the acceptable range significantly. Use the highest bit rate when bus devices can switch the rate under operating conditions.

### Bus load

For the attached sending devices the bus is a high load with its termination and biasing resistors. All bus participants additionally increase the load with their input resistors.
▲ A short calculation for the minimum resistance between A+ and D- is around 52Ω. This includes the termination resistors, the pull up/down resistors and the maximum allowed bus devices (32 devices at the standard 12kΩ (unit load) input resistance each). For the minimum recommended voltage swing of ±2V the current is ±38mA.
This current has to be delivered by the drivers at the maximum bit rate and bus impedance.
- Not all devices have sufficient drivers under all circumstances. The best is to capture the bus with a digital scope and check the outputs of all devices. Make sure that all voltages are inside the recommended range. Measure the parallel resistance in the inactive bus state.
▼ The switching behavior can depend on many parameters which must be checked and probably have not be taken into account. The total parallel resistance of the devices, the bus length and bit rate, the power supply of the bus drivers, the environment and a lot more.

### Summary

This part sums up the above chapters for correct bus design:
Use twisted wire pairs of equal length.
For rough environment use shielded cables Use a ground line for all devices.
Wire from device to device, no stubs. Terminate at both bus ends with 120Ω between A+ and B-.
Make sure (measure) that the termination resistance of the unpowered bus is 60Ω and not much less.
Bias the bus to a difference voltage of a bit over +200mV at 2.5V against ground. Check if the bus speed fits to the bus length even under bad conditions.
Make sure that the voltage swing is in the range of above +2V and below -2V under all operating conditions.
Use repeaters if necessary to split the bus into segments to decrease the bus load. Treat every segment as an independent bus

### Schematics and diagrams

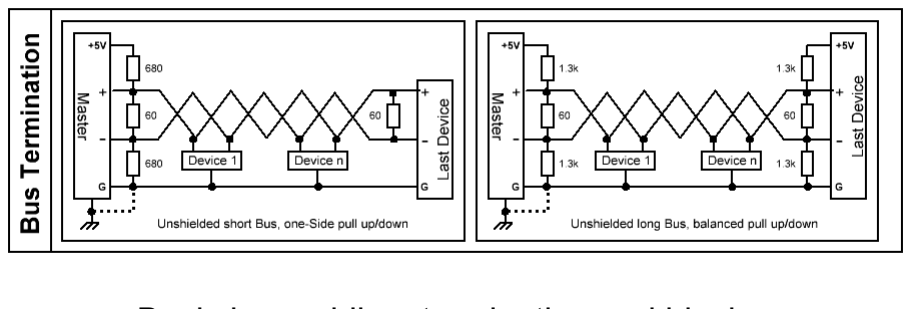
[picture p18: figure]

Basic bus cabling, termination and biasing

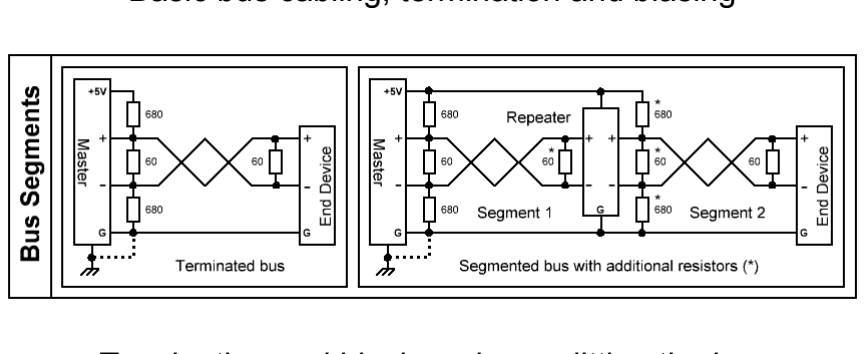
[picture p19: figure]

Termination and biasing when splitting the bus

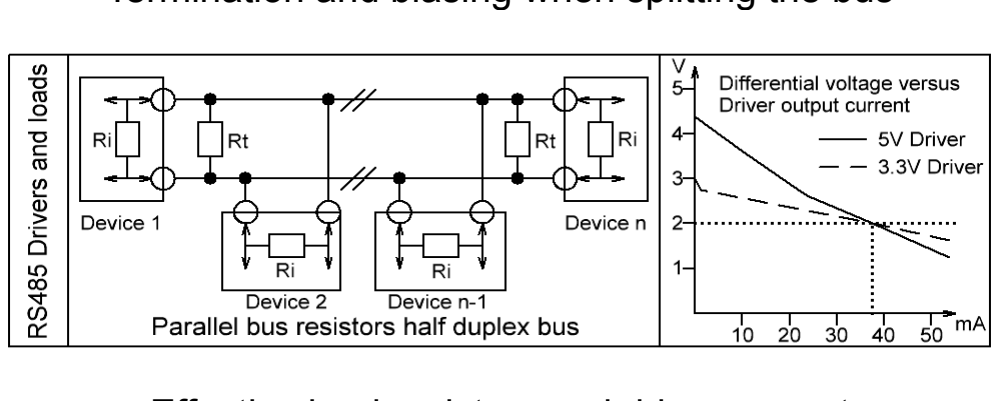
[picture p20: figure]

Effective load resistors and driver current

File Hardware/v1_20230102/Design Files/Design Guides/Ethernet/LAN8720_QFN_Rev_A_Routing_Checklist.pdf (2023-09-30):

REV | CHANGE DESCRIPTION | NAME | DATE
A | Release | | 7-25-12

Any assistance, services, comments, information, or suggestions provided by SMSC (including without limitation any comments to the effect that the Company’s product designs do not require any changes) (collectively, “SMSC Feedback”) are provided solely for the purpose of assisting the Company in the Company’s attempt to optimize compatibility of the Company’s product designs with certain SMSC products. SMSC does not promise that such compatibility optimization will actually be achieved. Circuit diagrams utilizing SMSC products are included as a means of illustrating typical applications; consequently, complete information sufficient for construction purposes is not necessarily given. Although the information has been checked and is believed to be accurate, no responsibility is assumed for inaccuracies. SMSC reserves the right to make changes to specifications and product descriptions at any time without notice.

### DOCUMENT DESCRIPTION

Routing Checklist for the LAN8720, 24-pin QFN Package

SMSC

### 80 Arkay Drive

Hauppauge, New York | 11788
Document Number | Revision
RC614946 | A

Revision A

## Routing Checklist for LAN8720

Information Particular for the 24-pin QFN Package

### LAN8720 QFN Phy Interface:

1. The traces connecting the transmit outputs (TXP, pin 21) & (TXN, pin 20) to the magnetics must be run as differential pairs. The differential impedance should be 100 ohms.
2. The traces connecting the receive inputs (RXP, pin 23) & (RXN, pin 22) from the magnetics must be run as differential pairs. The differential impedance should be 100 ohms.
3. For differential traces running from the LAN controller to the magnetics, SMSC recommends routing these traces on the component side of the PCB with a contiguous digital ground plane on the next layer. This will minimize the use of vias and avoid impedance mismatches by switching PCB layers.
4. Refer to Figure No. 1 for differential pair routing details.
5. The VDD1A/VDD2A power supply should be routed as a mini-plane and can be routed on an internal power plane layer.
6. Refer to Figure No. 2 for VDD1A/VDD2A power plane details.

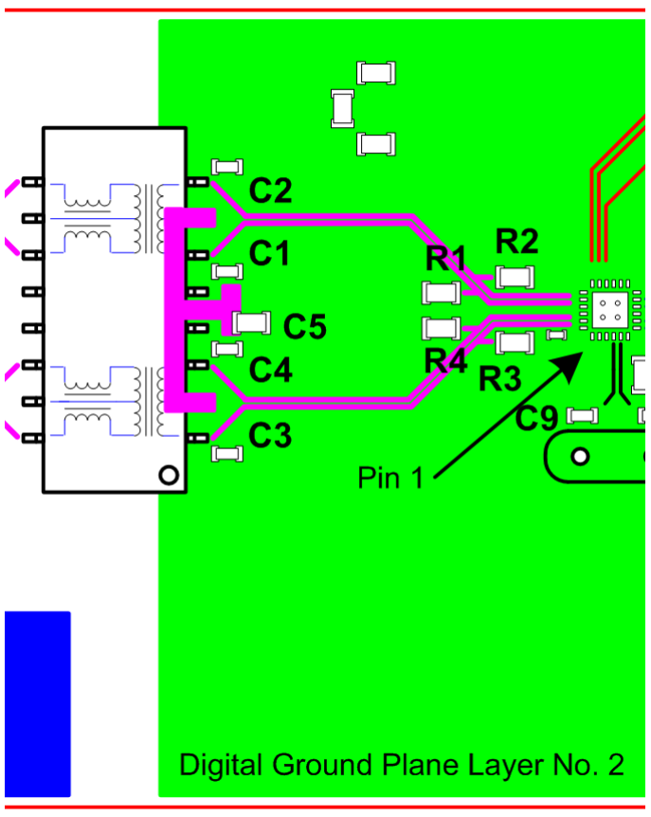
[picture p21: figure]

### Figure No. 1

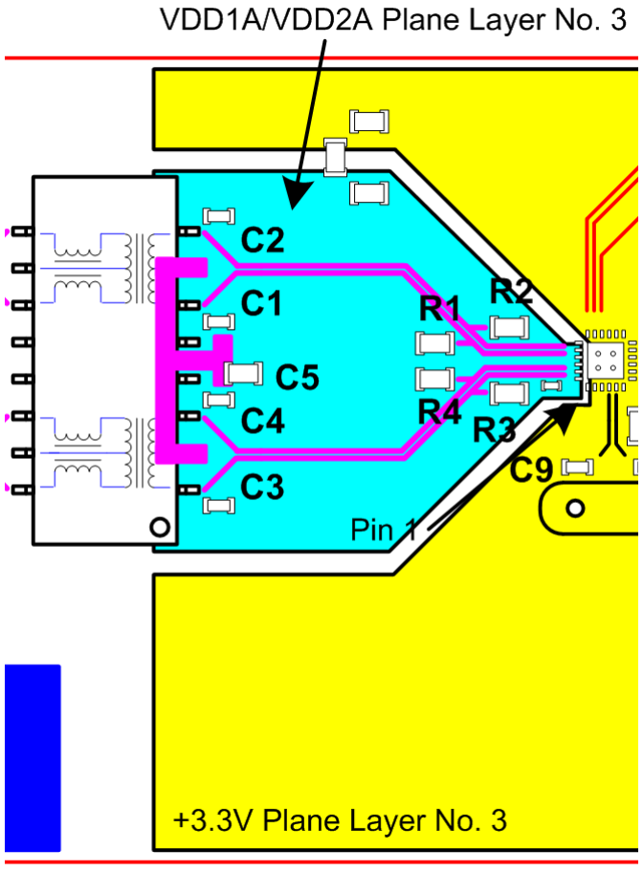
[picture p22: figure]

### Figure No. 2

### LAN8720 QFN Magnetics:

1. The traces connecting the transmit outputs from the magnetics to pins 1 & 2 on the RJ45 connector must be run as differential pairs. Again, the differential impedance should be 100 ohms.
2. The traces connecting the receive inputs on the magnetics from pins 3 & 6 on the RJ45 connector must be run as differential pairs. Again, the differential impedance should be 100 ohms.
3. For differential traces running from the magnetics to the RJ45 connector, SMSC recommends routing these traces on the component side of the PCB with all power planes (including chassis ground) cleared out from under these traces. This will minimize the use of vias and minimize any unwanted noise from coupling into the differential pairs. The plane clear out boundary is usually halfway through the magnetics.

### RJ45 Connector:

1. Try to keep all other signals out of the Ethernet front end (RJ45 through the magnetics to the LAN chip). Any noise from other traces may couple into the Ethernet section and cause EMC problems.
2. Also recommended, is the construction of a separate chassis ground that can be easily connected to digital ground at one point. This plane provides the lowest impedance path to earth ground.
3. Refer to Figure No. 3 for Ethernet front end routing details.

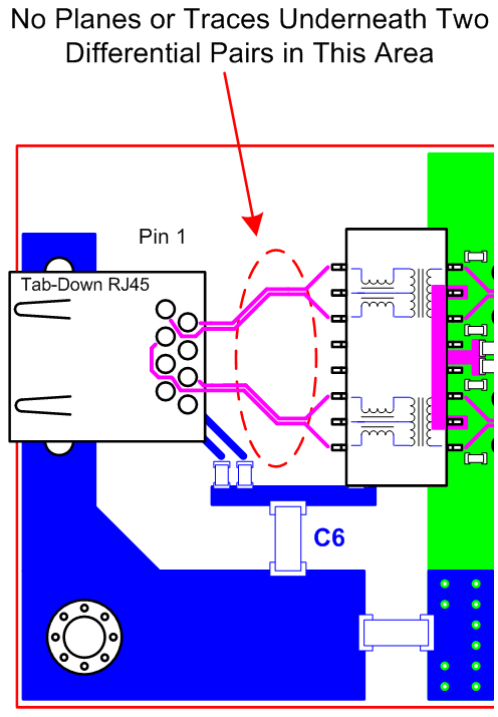
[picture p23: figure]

### Figure No. 3

### Power Supply Connections:

1. Route the (2) VDD1A and VDD2A pins of the LAN8720 QFN directly into a solid, +3.3V power plane (created with a ferrite bead). The pin-to-plane trace should be as short as possible and as wide as possible.
2. In addition, route the (2) VDD1A and VDD2A decoupling capacitors for the LAN8720 QFN power pins as short as possible to each separate power pin. There should be a short, direct copper connection as well as a connection to each power plane (+3.3V & digital ground plane) for each cap.
3. Route the (1) VDDIO pin of the LAN8720 QFN directly into a solid, variable voltage (+1.8V to +3.3V) power plane. The pin-to-plane trace should be as short as possible and as wide as possible.
4. In addition, route the (1) VDDIO decoupling capacitor for the LAN8720 power pin as short as possible to the power pin. There should be a short, direct copper connection as well as a connection to each power plane (power plane & digital ground plane) for the cap.

### Ground Connections:

1. The single digital ground pin (pin 25, EDP) on the LAN8720 QFN should be connected directly into a solid, contiguous, internal ground plane. The EDP pad on the component side of the PCB should be connected to the internal digital ground plane with 4 power vias in a 2x2 grid.
2. We recommend that all Ground pins be tied together to the same ground plane. We do not recommend running separate ground planes for any of our LAN products.

### VDDCR:

1. The VDDCR pin, pin 6, must be routed with a heavy, wide trace with multiple vias to the single decoupling cap and the single bulk capacitor associated with it. A mini-plane is also acceptable.

### Crystal Connections:

1. The routing for the crystal or clock circuitry should be kept as small as possible and as short as possible. Refer to Figure No. 4 below for details.
2. A small ground flood routed under the crystal package on the component layer of PCB may improve the emissions signature. Stitch the flood with multiple vias into the digital ground plane directly below it.
3. The REF_CLK Out Mode is not part of the RMII Specification. Timing in this mode is not compliant with the RMII specification. To ensure proper system operation, a timing analysis of the MAC and LAN8720 must be performed. Some MACs may require a small delay (500 pS – 1.0 nS) to the RXD[1..0] & CRS_DV signals. One method to achieve such a delay is to serpentine the signals from the Phy to the MAC.

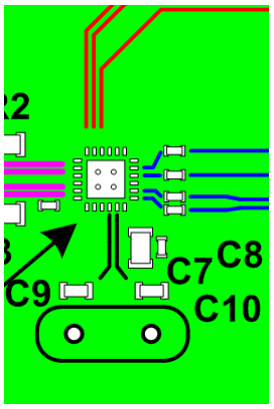
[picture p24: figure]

### Figure No. 4

### Clock Oscillator Connections:

1. Place the 50 MHz clock oscillator approximately half-way between the LAN8720 and the RMII MAC in the application. This should ensure relatively matched clock runs to each.
2. Place the series terminations for splitting the 50 MHz clock as close as possible to the clock oscillator in the design.
3. As controlled by the different component placements, the two resultant clock traces should be matched to within 0.10” and have an overall trace length of less than 6.0”.

### MAC REFCLK Connections:

1. Place the series termination for the MAC supplied 50 MHz clock as close as possible to the MAC in the design.
2. As controlled by the different component placements, the resultant clock trace should be as short as possible.

### RBIAS Resistor:

1. The RBIAS resistor (pin 24) should be routed with a short, wide trace. Any noise induced onto this trace may cause system failures. Do not run any traces under the RBIAS resistor.

### RMII Interface:

1. The RMII interface on the LAN8720 should be constructed using 68-ohm traces.
2. Similar groups of the RMII interface should be routed together on the PCB. Transmit channel signals should be routed together and separate from Receive channel signals.
3. RMII signals considered critical should be routed on the top layer next to a contiguous, digital ground plane. Slower RMII signals can be routed on the bottom layer of the PCB.
4. As with any high-speed digital design, inter-space and intra-space guidelines between RMII signals should help to improve crosstalk and signal integrity issues.
5. Refer to Figures No. 5 and No. 6 for details on RMII signal routing.

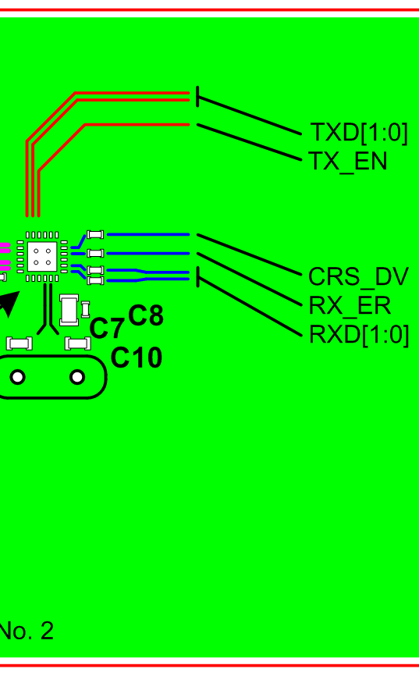
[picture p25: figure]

### Figure No. 5

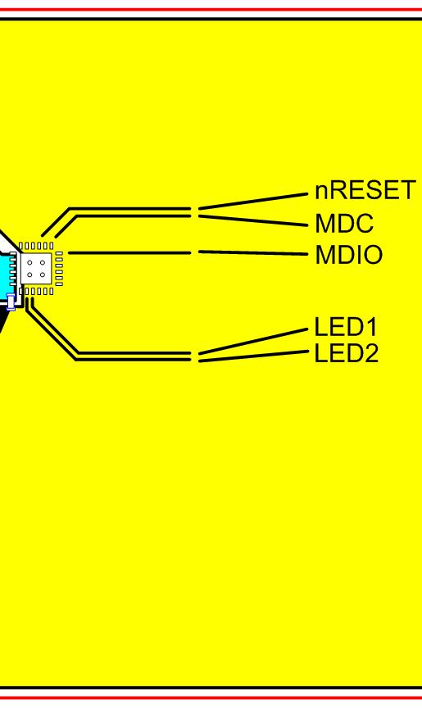
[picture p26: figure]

### Figure No. 6

### RMII Series Terminations:

1. If the designer has elected to use impedance matching terminations in his design, these series resistors should be placed as close as possible to the source of the driving signal.
2. The RMII Series Terminations should be considered critical components. To ensure the best signal integrity and good EMI performance, these critical components should be placed on the component side of the PCB. This will ensure that these components will be referenced to a contiguous ground plane reference on Layer 2 of the design. This will also minimize the use of vias in routing these signals.

### Required External Pull-ups:

1. There are no critical routing instructions for the Required External Pull-up connections.

### Mode Pins:

1. Since the MODE Pins are shared with the RXD[1..0] and CRS_DV signals of the LAN8720, any resistor used for termination for the power-on-reset MODE selection, should be placed on the component side of the PCB. This will minimize vias and ensure the reference plane remains constant.
2. Any stub added to the RMII lines due to MODE pin terminations should be kept to a minimum.

### Phy Address Pins:

1. Phy Address pin PHYAD0 should also be considered critical. This pin is shared with the RX_ER function of the RMII interface. Any resistor used for termination for the power-on-reset Phy Address selection, should be placed on the component side of the PCB. This will minimize vias and ensure the reference plane remains constant for these three signals.
2. Any stub added to the RMII line due to PHYAD0 termination should be kept to a minimum.

### LED Pins:

1. There are no critical routing instructions for the LED Pin connections.

### Interrupt Functionality:

1. There are no critical routing instructions for the Interrupt connection.

### Miscellaneous:

1. SMSC recommends utilizing at least a four-layer design for boards for the LAN8720 QFN device. The design engineer should be aware, however, as tighter EMC standards are applied to his product and as faster signal rates are utilized by his design, the product design may benefit by utilizing up to eight layers for the PCB construction.
2. As with any high-speed design, the use of series resistors and AC terminations is very application dependant. Buffer impedances should be anticipated and series resistors added to ensure that the board impedance matches the driver. Any critical clock lines should be evaluated for the need for AC terminations. Prototype validation will confirm the optimum value for any series and/or AC terminations.
3. Bulk capacitors for each power plane should be routed immediately into power planes with traces as short as possible and as wide as possible.
4. Following these guidelines and other general design rules in PCB construction should ensure a clean operating system.
5. Trace impedance depends upon many variables (PCB construction, trace width, trace spacing, etc.). The electrical engineer needs to work with the PCB designer to determine all these variables.

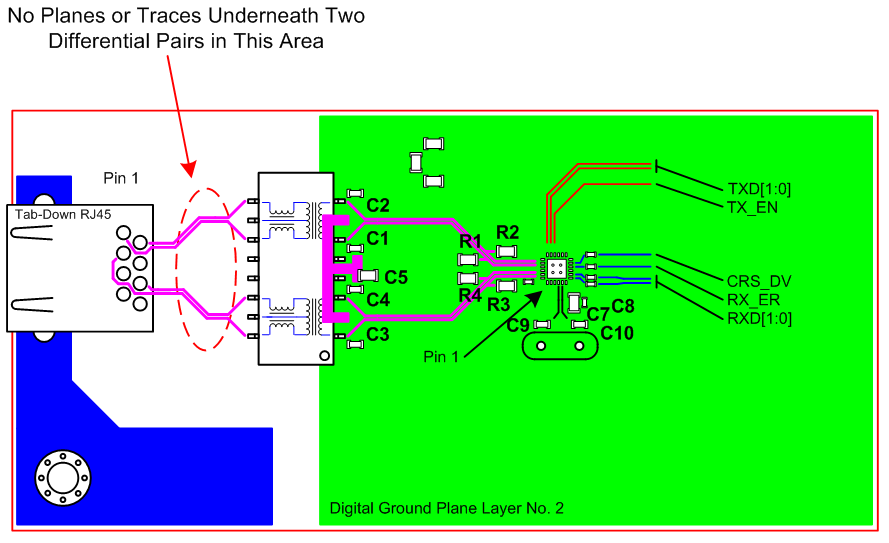
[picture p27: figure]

Page 14 of 15

### Figure No. 7

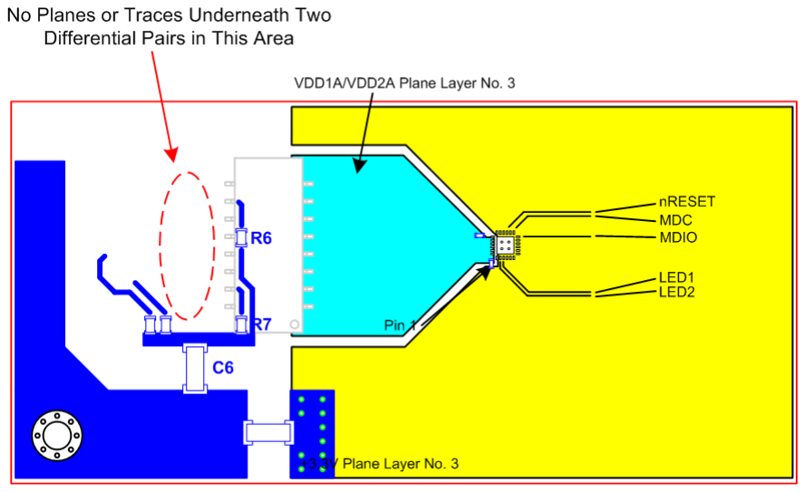
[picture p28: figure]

Page 15 of 15

### Figure No. 8

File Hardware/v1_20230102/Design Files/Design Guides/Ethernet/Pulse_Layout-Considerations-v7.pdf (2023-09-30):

Connecting People Now and in the Future

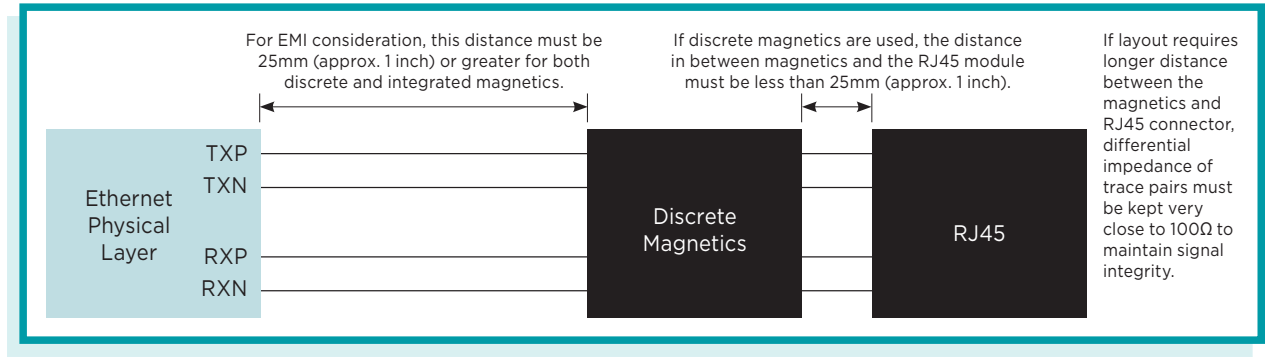
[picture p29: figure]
discrete and integrated magnetics.; TXP TXN; RXP RXN; Discrete; Magnetics; Ethernet Physical Layer; If layout requires longer distance between the magnetics and RJ45 connector, differential impedance of trace pairs must be kept very close to 100Ω to maintain signal integrity.

### 1 networking.pulseelectronics.com

Note: This document is for reference only; please contact your PHY/IC supplier for specific board layout recommendations.

Pulse Electronics’ Networking BU offers a broad line of networking and telecommunication products, including our Ethernet magnetics and Ethernet connector modules (which incorporate the Ethernet magnetic into the connector). Both of these product categories include components optimized for use in 100BASE-TX, 1000BASE-T and 2.5/5/10GBASE-T systems, including PoE, Extended Temperature, and high isolation applications.

Our Ethernet magnetics are RoHS compliant, qualified at major PHY suppliers, and optimized for all major LAN transceivers. All of them provide electrical circuit isolation that meets IEEE 802.3, while maintaining the high standard of signal integrity needed for the most demanding applications. Our Ethernet connector modules are designed and manufactured to meet or exceed IEEE 802.3 standards.

We developed this document to help our customers using these Ethernet products when laying out printed circuit boards (PCBs) intended to interface with an Ethernet network. It includes recommendations on PCB layout to reduce EMI and maintain signal integrity. For additional board layout assistance or specific design guidelines, contact the supplier of the PHY you have chosen.

Many factors go into laying out a PCB efficiently. Complexity, board space, and the number and types of devices required will often dictate routing and placement strategies.

Component Placement Guidelines
Component placement can affect signal quality, emissions, and component operating temperature. When performing a board layout, the CAD tool must not be used to route the differential pairs automatically without intervention. In most cases, the differential pairs must be routed manually. The following guidelines offer direction on optimizing the PCB design process:
- Minimize potential problems directly related to EMI, which could cause the system to fail to meet applicable government test specifications.
- Simplify the task of routing traces. To some extent, component orientation will affect the complexity of trace routing. The overall objective is to minimize turns and crossovers between traces.
- Optimize the distance between the Ethernet magnetic and the RJ45 connector. It should be kept to less than 25 mm (approx. 1 inch). Refer to Figure 1 for guidance on placement of these components.

Introduction

Best Practices for PCB Design

Figure 1. Pulse Ethernet Magnetic and RJ45 Placement

# Layout Considerations for Pulse Ethernet Magnetics and Ethernet Connector Modules

For EMI consideration, this distance must be 25mm (approx. 1 inch) or greater for both

If discrete magnetics are used, the distance in between magnetics and the RJ45 module must be less than 25mm (approx. 1 inch).

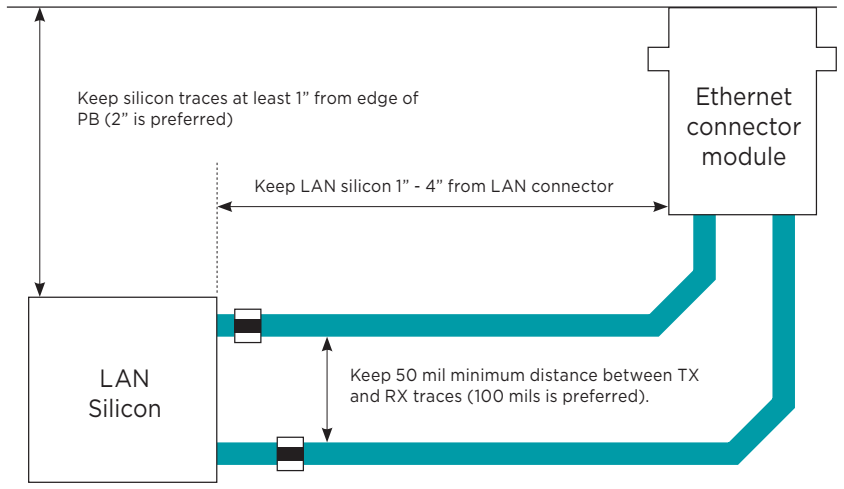
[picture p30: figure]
PB (2” is preferred); Keep 50 mil minimum distance between TX and RX traces (100 mils is preferred).; Ethernet connector module; LAN Silicon
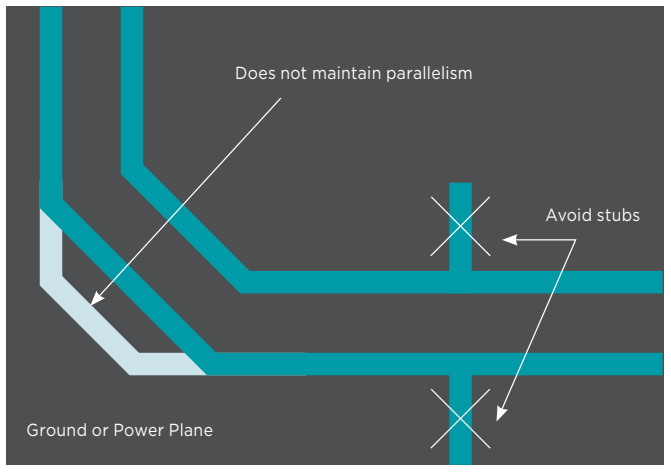
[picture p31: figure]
Ground or Power Plane; Does not maintain parallelism; Avoid stubs

### 2 networking.pulseelectronics.com

- Isolate the PHY from the Ethernet magnetic; the distance between them needs to be 25 mm (approx. 1 inch) or greater. Among PHY vendors, this rule is considered good design practice for EMI considerations.
- Keep the PHY device and the differential transmit pairs at least 25 mm (approx. 1 inch) from the edge of the PCB, up to the Ethernet magnetic. If using an Ethernet connector module, which incorporates the magnetic, the differential pairs should be routed to the back of the connector module, away from the board edge.
- Minimizing the amount of space needed for the Ethernet LAN interface is important because other interfaces will compete for physical space on a motherboard near the Ethernet connector module. Ethernet LAN circuits need to be located as close to the connector as possible.
- Refer to Figure 2 for some basic placement distance guidelines. Although it shows two differential pairs, it can be generalized for 1000BASE-T to 10GBASE-T systems with four analog pairs. The ideal placement for the Ethernet silicon would be approximately one inch behind the Ethernet magnetic. This figure also illustrates the need to keep the LAN silicon away from the board edge and the magnetics module for best EMI performance.

Figure 2. General Placement Distances

Trace Length and Symmetry
- Critical signal traces should be kept as short as possible to decrease the likelihood of any effects from other signals with high-frequency noise, including noise carried on power and ground planes. Keeping the traces as short as possible also helps reduce capacitive loading.
- Differential pairs should be routed to be as short and symmetrical as possible. The overall length of differential pairs should be less than four inches as measured from the controller across the Ethernet magnetic to the connector.
- The lengths of the differential traces (within each pair) should be equal to within 50 mils (1.25 mm) and as symmetrical as possible. Asymmetrical
and unequal length traces in the differential pairs contribute to common mode noise.
- To reduce crosstalk interference on signals between pairs, the distance between unlike differential pairs must be more than 50 mils (1.25 mm). This rule also
applies to differential pairs from other transceiver
circuits on the same board.
- Stubs should be avoided on all signal traces, especially the differential signal pairs. See Figure 3.

Keep silicon traces at least 1” from edge of

Keep LAN silicon 1” - 4” from LAN connector

Figure 3. Differential Signal Pair – Stubs

### 3 networking.pulseelectronics.com

- Within the pairs (for example, TD+ and TD-) the trace lengths should be run parallel to each other and matched in length. Matched lengths minimize delay differences, avoiding an increase in common mode noise and increased EMI.
- Signal traces should not be run such that they cross a plane split. See Figure 4. A signal crossing a plane split may cause unpredictable return path currents and would likely impact signal quality as well, potentially creating EMI problems.
- Media Dependent Interface (MDI) signal traces should have 50 Ω to ground or 100 Ω differential controlled impedance.

Differential Pair Trace Routing
To minimize the effects of crosstalk and propagation delays on sections of the board on which high-speed signals are routed, follow these trace routing guidelines:
- Place digital signals far away from the analog traces to help maintain signal integrity. A good rule of thumb to follow is that no digital signal should be located within 300 mils (7.5 mm) of the differential pairs.
- If digital signals on other board layers cannot be separated by a ground plane, they should be routed at right angles with respect to the differential pairs.
- Although ganged Ethernet connector modules are allowed, the signals for each circuit must also be carefully separated.
- Keep maximum separation within differential pairs to 10 mils.
- Ideally, there should be no crossover or via on the signal paths. Route
an entire trace pair on a single layer if possible. Vias present impedance
discontinuities and should be minimized; at most, use two vias per trace. For high-speed signals, keep the number of corners and vias to a minimum. If a 90° bend is required, use two 45° bends instead, as illustrated in Figure 5.
- Route traces away from board edges by a distance greater than the trace height above the ground plane. This allows the field around the
trace to couple more easily to the ground plane rather than to adjacent
wires or boards.
- Do not route traces and vias under crystals or oscillators. This will prevent coupling to or from the clock. As a general rule, place traces from clocks and drives at a minimum distance from apertures by a distance that is greater than the largest aperture dimension.
- Do not route differential pairs over splits in the associated reference plane.
- Place differential termination components as close as possible to the LAN silicon.

Signal Trace Geometry
- The key factors in controlling trace EMI radiation are the trace length and the ratio of trace width to trace height above the ground plane. To minimize trace inductance, high-speed signals and signal layers that are close to a ground or power plane should be as short and wide as practical. Ideally, this trace width to height above the ground plane ratio is between 1: 1 and 3:1. To maintain trace impedance, the width of the trace should be modified when changing from one board layer to another if the two layers are not equidistant from the power or ground plane.
- Each pair of signals should have a differential impedance of 100 Ω + 15%. If a particular tool cannot design differential traces, it is permissible to specify 55 Ω to 65 Ω single-ended traces as long as the spacing between the two traces is minimized. As an example, consider a differential trace pair on Layer I that is 8 mils (0.2 mm) wide and 2 mils (0.05 mm) thick, with a spacing of 8 mils (0.2 mm). If the fiberglass layer is 8 mils (0.2 mm) thick with a dielectric constant, ER, of 4.7, the calculated single-ended impedance would be approximately 61 Ω and the calculated differential impedance would be approximately 100 Ω.
- It is necessary to compensate for trace-to-trace edge coupling, which can lower the differential impedance by up to 10 Ω, when the traces within a pair are closer than 30 mils (edge-to-edge).

Power and Ground Planes
Good grounding requires minimizing inductance levels in the interconnections and keeping ground returns short, signal loop areas small, and power inputs bypassed to signal return. These practices will significantly reduce EMI radiation. The following guidelines help reduce circuit inductance in both backplanes and motherboards.
- Route traces over a continuous plane with no interruptions. Do not route over a split power or ground plane. If there are vacant areas on a ground or power plane, avoid routing signals over the vacant area. This will increase inductance and EMI radiation levels.

Figure 4. Differential Signal Pair-Plane Crossing

Ground or Power Plane

Does NOT cross Power
or Ground Planes

Figure 5. Trace Routing

45°

45°

### 4 networking.pulseelectronics.com

- Separate noisy digital grounds from analog grounds to reduce coupling. Noisy digital grounds may affect sensitive DC subsystems.
- Connect all ground vias to every ground plane and every power via to all power planes at equal potential. This helps reduce circuit inductance.
- Physically locate grounds between a signal path and its return. This will minimize the loop area.
- Avoid fast rise and fall times as much as possible. Signals with fast rise and fall times contain many high-frequency harmonics, which can radiate EMI.
- Split ground planes beneath magnetic modules. The RJ45 connector side of the magnetic module should have chassis ground beneath it.

Ground Planes Under the Ethernet Magnetic
There should be no ground planes beneath a discrete LAN magnetics package in order to minimize any possible coupling between components that are relatively close to the surface of the PCB (as illustrated in Figure 6). For integrated connector modules, the chassis ground plane should run under the component to connect with the shield of the connector (as shown in Figure 7). Within the connector module, all magnetic components are far enough away from the PCB to prevent any unwanted coupling of signals.

Troubleshooting Common Physical Layout Issues
Check for these common physical layer design and layout mistakes in LAN on motherboard designs.
1. Unequal length of the two traces within a differential pair. Inequalities create common-mode noise and will distort the transmit or receive waveforms.
2. Lack of symmetry between the two traces within a differential pair. Asymmetry can create common-mode noise and distort the waveforms. For each component and via that one trace encounters, the other trace should encounter the same component or via at the same distance from the Ethernet silicon.
3. Excessive distance between the Ethernet silicon and the Ethernet magnetic. Long traces on FR-4 fiberglass epoxy substrate will attenuate the analog signals. In addition, any impedance mismatch in the traces will be aggravated if they are longer than four inches.
4. Routing any other trace parallel to and close to one of the differential traces. If crosstalk gets onto the receive channel, it will cause degraded long cable BER. Crosstalk getting onto the transmit channel can cause excessive EMI emissions and can cause poor transmit BER on long cables. At a minimum, other signals should be kept 0.3 inches from the differential traces.
5. Routing one pair of differential traces too close to another pair of differential traces. After exiting the Ethernet silicon, the trace pairs should be kept 0.3 inches or more away from the other trace pairs. The only possible exceptions are in the vicinities where the traces enter or exit the Ethernet magnetic, the RJ45 connector, and the Ethernet silicon.
6. Re-use of an out-of-date physical layer schematic in an Ethernet silicon design. The terminations and decoupling can be different from one PHY to another.

Figure 7. The Chassis Ground Plane Should Run Beneath the Integrated Connector Module (ICM).

Figure 6. No Ground Planes Beneath Discrete Magnetics

Circuit Ground Plane

Discrete
Magnetics
package

Pulse ICM

Chassis
Ground

No Ground Plane
Under Magnetics

RJ45 Connector Placed
Above Chassis Ground

Chassis Ground

### 5 networking.pulseelectronics.com

7. Incorrect differential trace impedances. It is important to have ~100 Ω impedance between the two traces within a differential pair. This becomes even more important as the differential traces become longer. To calculate differential impedance, many impedance calculators only multiply the single-ended impedance by two, but this does not take into account edge-to-edge capacitive coupling between the two traces. When the two traces within a differential pair are kept close to each other, the edge coupling can lower the effective differential impedance by 5 Ω to 20 Ω. Short traces will have fewer problems if the differential impedance is slightly off target.

Termination Plane and Chassis Ground
In 1000BASE-T, 2.5GBASE-T, 5GBASE-T, and 10GBASE-T systems, the main design elements are the transceiver (PHY), the Ethernet magnetic and the RJ45 connector. In many cases, the Ethernet magnetic and RJ45 connector can be replaced with an Ethernet connector module. Because the transmission line medium extends onto the printed circuit board, special attention must be paid to layout and routing of the differential signal pairs.

Printed circuit boards for 1000BASE-T, 2.5GBASE-T,
5GBASE-T, and 10GBASE-T designs often have six or more
layers. In these designs, it is common practice to terminate
center tap Ethernet magnetic connections to ground as
a path for low frequency noise. Depending on the overall shielding and grounding design, the specific ground used for this purpose can vary. We recommend the use of a dedicated termination plane, with the center tap leads connected to the termination plane through 75 Ω resistors.

The termination plane is typically fabricated in Layer I, with a matching chassis ground plane underneath as illustrated in Figure 8. The clearance between the termination plane and any traces should be at least 50 mils (1.25 mm) to prevent arcing during high voltage tests. The termination plane and chassis ground layer combination has some capacitance, which can be augmented by adding a discrete 1500 pF capacitor.

The Ethernet connector module also contains the termination
plane, 75 Ω termination resistors and a 1000 pF to 1500
pF capacitor. If integrated components are going to be used, their internal design needs to be evaluated carefully. The electrical parameters, EMI, and high voltage test results should be equivalent to, or better than, the characteristics of a discrete design.

Additional capacitors are required to interconnect chassis ground and signal ground. The suggested technique is to use several different capacitor values (for example, two 1000 pF, one 4.7 mF, and one 10 µF). Depending on available board space, one set of capacitors should be placed on each side of the Ethernet magnetic. Modifications to this interconnection scheme are possible.

In general, no ground plane should extend under the TX and RX differential pairs, under the Ethernet magnetic, or under the RJ45 jack. In cases where common mode capacitors are used for EMI suppression, a ground plane may be located under the TX and RX signals; however, the plane must not extend beyond the capacitors. When designing 4-layer boards, the ground plane should exist on layer 4, assuming the differential pair is routed on layer 1. On 2-layer boards, the ground plane can be located on layer 2, the layer adjacent to the TX and RX signal pairs. Under no circumstances should a ground plane exist under the Ethernet magnetic, the RJ45 connector, or in between the Ethernet magnetic and RJ45 connector. See Figure 9.

Layout Issues and Configurations Specific to 1000BASE-T to 10GBASE-T Four-Pair Ethernet Applications

Figure 8. Termination Plane and Chassis Ground

Signal
Ground
Plane
(Layer2)

Gap

Pads for
Termination
Resistors

Chassis
Ground
(Layer2

Termination Plane
(Layers 1 and 6)

Magnetics
Module

RJ45
Connector

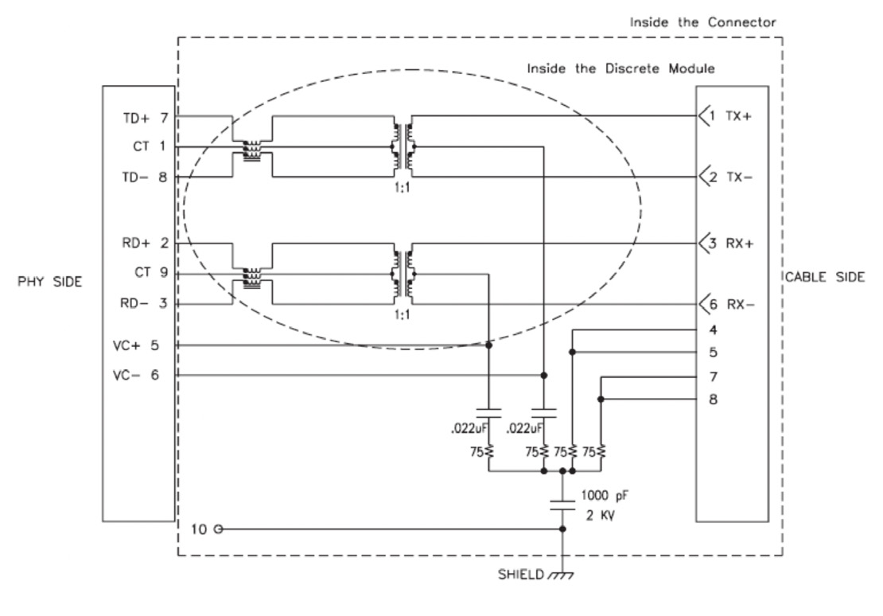
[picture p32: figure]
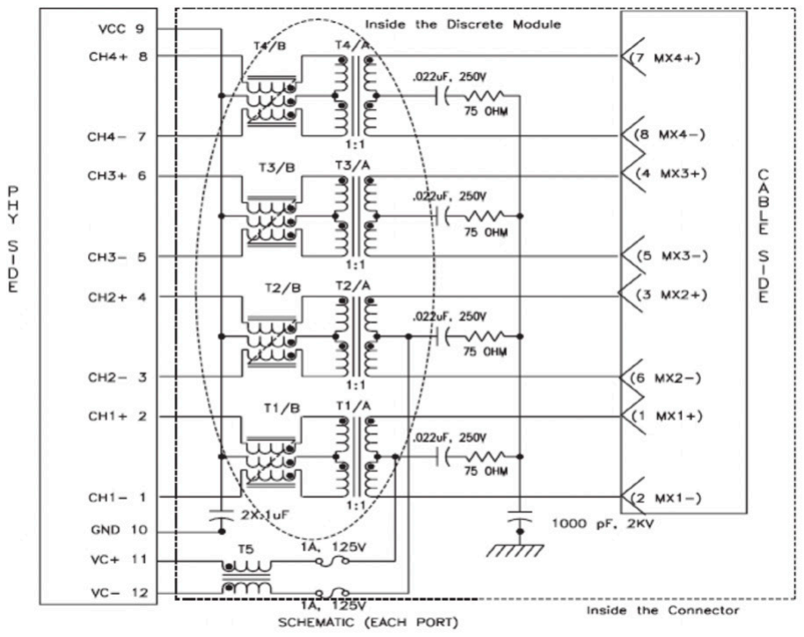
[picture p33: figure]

### 6 networking.pulseelectronics.com

Figure 9. Ground Planes

Isolation and Termination
According to the IEEE 802.3af and the IEEE802.3at standards, certain isolation requirements need to be met in all PoE equipment. In addition, EMI limitations should be considered, as specified in the FCC and European EN regulations.

PoE Best Practices
- Layering ground planes is advisable. Route connector/discrete module ground pins to chassis/analog ground if possible. Keep signal traces from PHY to connector/discrete module as short as possible. If traces exceed 3-4 inches, pay close attention to line impedance imbalance.
- Using Bob Smith Termination (BST - 75 Ω resistors and high voltage cap to chassis ground) to terminate cable side center taps is advisable for best EMI performance (included in most connector solutions). Consult the PHY manufacturer’s application notes for further layout considerations.
- To maintain 1500Vrms isolation between two adjacent layers of a NEMA FR-4 multi-layer PCB, a minimum of 15 mils isolation thickness is recommended. This provides a safe margin for hi-pot requirements.
- Take special care when routing the ground and power signals lines.

PoE Application Circuits
Figure 10 and Figure 11 illustrate 100BASE-TX and 1000BASE-T, 2.5GBASE-T, 5GBASE-T, and 10GBASE-T PoE application circuits.

Layout Issues and Configurations Specific to Power over Ethernet (PoE) Applications

Figure 10. 100BASE-TX PoE Application Circuit | Figure 11. 1000BASE-T, 2.5GBASE-T, 5GBASE-T, and 10GBASE-T PoE Application Circuit

Ground

Discrete or Integrated Solution

Magnetic | RJ45

TX

RX

Ethernet
Physical Layer

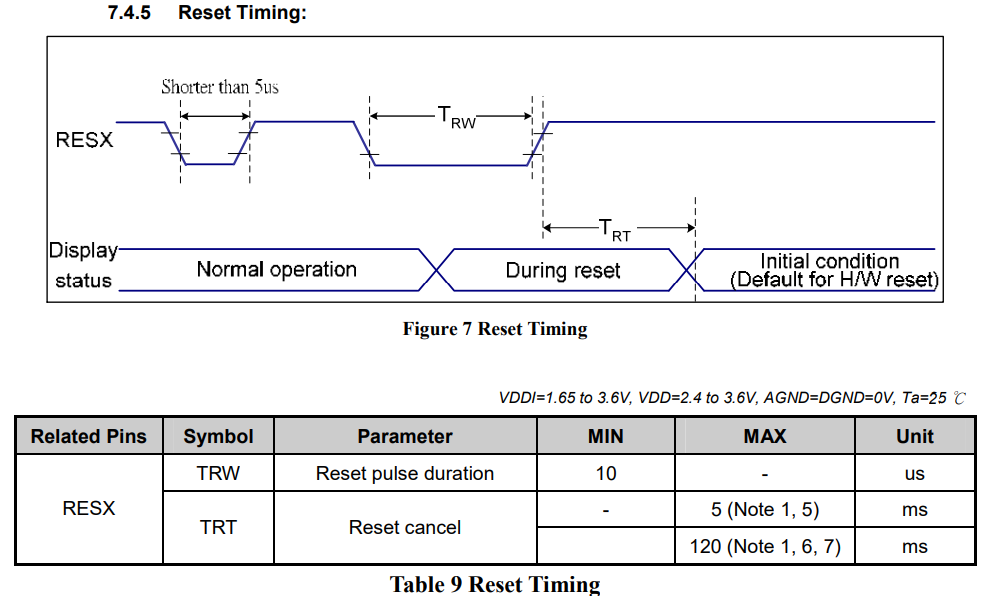
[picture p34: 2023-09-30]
Hardware/v1_20230102/Design Files/Design Guides/RGB_Reset.png

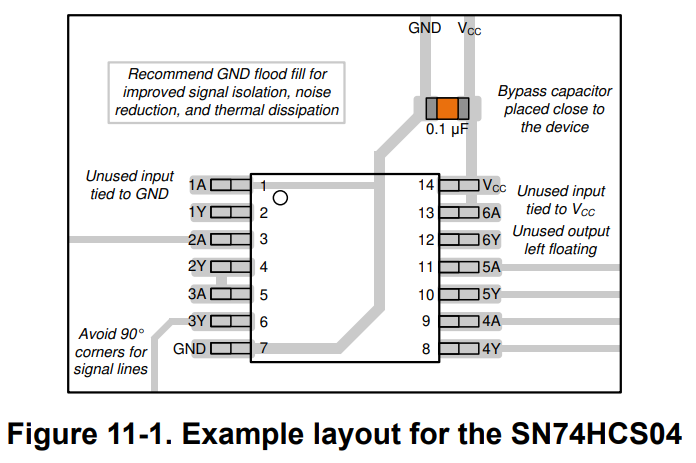
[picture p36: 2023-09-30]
Hardware/v1_20230102/Design Files/Design Guides/sn74hcs04.png

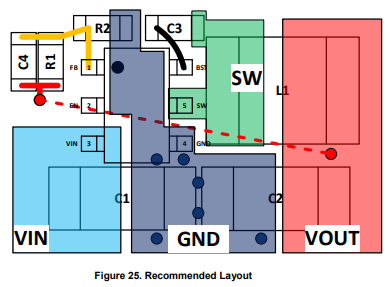
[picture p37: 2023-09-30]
Hardware/v1_20230102/Design Files/Design Guides/AP63205 PCB LAYOUT.png

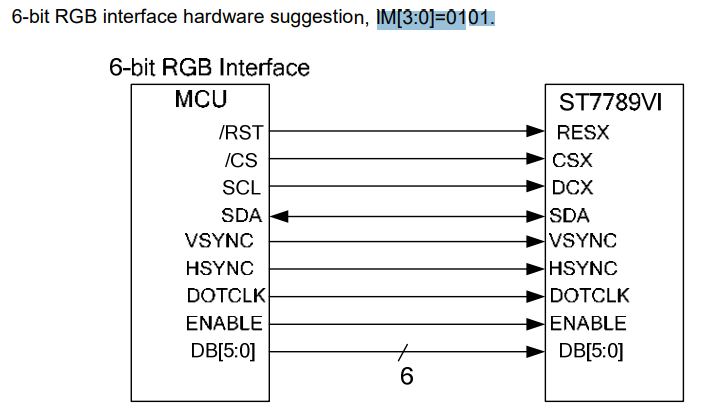
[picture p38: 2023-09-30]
Hardware/v1_20230102/Design Files/Design Guides/6BIT-RGB_Interface.png

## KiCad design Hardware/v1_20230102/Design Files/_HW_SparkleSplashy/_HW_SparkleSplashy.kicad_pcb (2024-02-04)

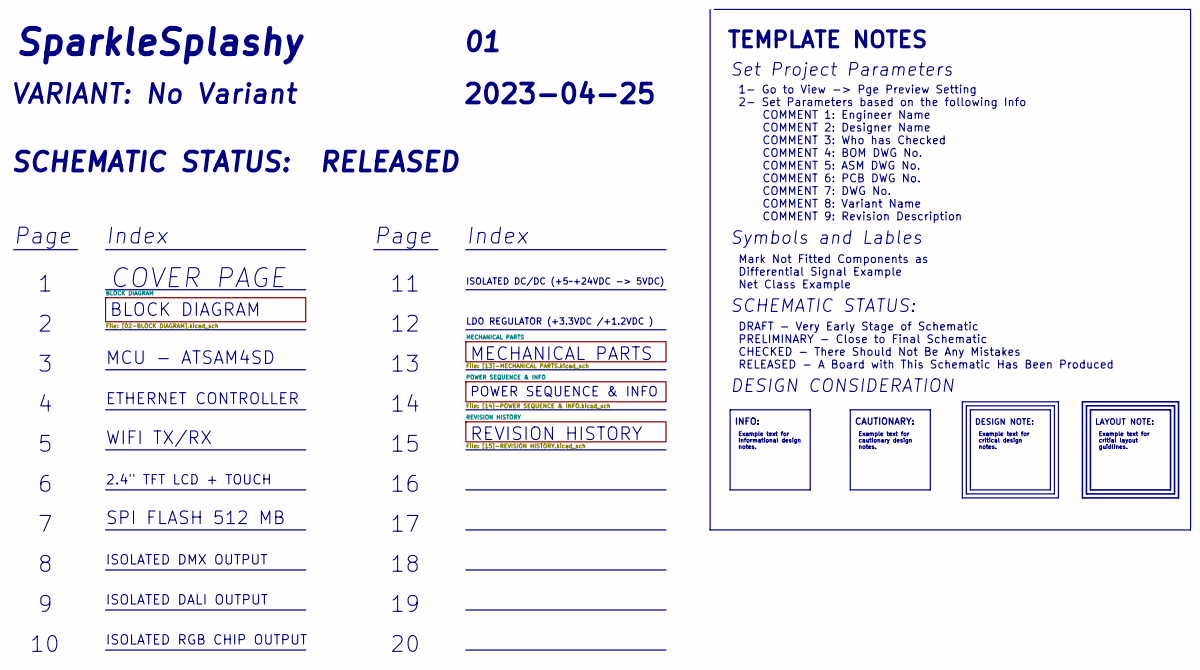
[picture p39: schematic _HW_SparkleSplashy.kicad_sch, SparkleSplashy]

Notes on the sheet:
DRAFT - Very Early Stage of Schematic PRELIMINARY - Close to Final Schematic CHECKED - There Should Not Be Any Mistakes RELEASED - A Board with This Schematic Has Been Produced
Index
VARIANT: ${COMMENT8}
INFO:
WIFI TX/RX
${ISSUE_DATE}
ISOLATED DC/DC (+5~+24VDC -> 5VDC)
COVER PAGE
SCHEMATIC STATUS:
2.4" TFT LCD + TOUCH
MECHANICAL PARTS
Symbols and Lables
POWER SEQUENCE & INFO
DESIGN NOTE:
Set Project Parameters
1- Go to View -> Pge Preview Setting 2- Set Parameters based on the following Info COMMENT 1: Engineer Name COMMENT 2: Designer Name COMMENT 3: Who has Checked COMMENT 4: BOM DWG No. COMMENT 5: ASM DWG No. COMMENT 6: PCB DWG No. COMMENT 7: DWG No. COMMENT 8: Variant Name COMMENT 9: Revision Descrip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
Page
${REVISION}
MCU - ATSAM4SD
ISOLATED DMX OUTPUT
Example text for Informational design notes.
${TITLE}
LDO REGULATOR (+3.3VDC /+1.2VDC )
BLOCK DIAGRAM
REVISION HISTORY
ISOLATED RGB CHIP OUTPUT
SPI FLASH 512 MB
Example text for critical design notes.
Example text for critial layout guidlines.
ETHERNET CONTROLLER
SCHEMATIC STATUS:
LAYOUT NOTE:
CAUTIONARY:
ISOLATED DALI OUTPUT
Example text for cautionary design notes.
Mark Not Fitted Components as Differential Signal Example Net Class Example
DESIGN CONSIDERATION
RELEASED
TEMPLATE NOTES

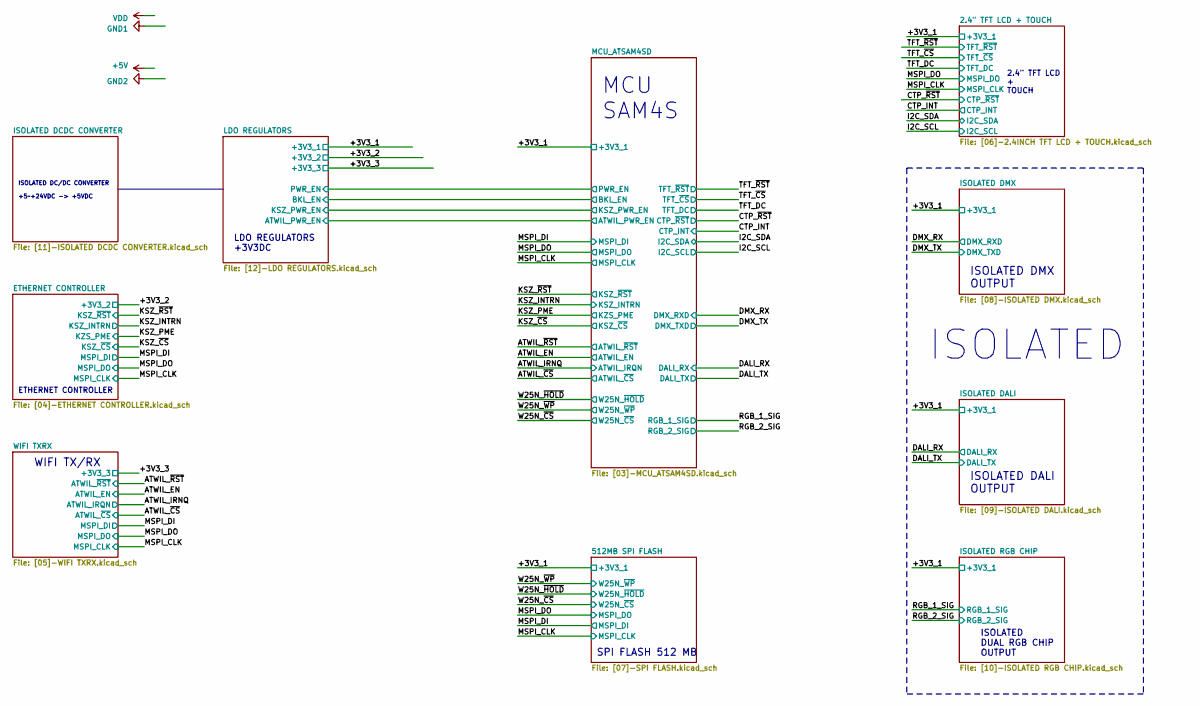
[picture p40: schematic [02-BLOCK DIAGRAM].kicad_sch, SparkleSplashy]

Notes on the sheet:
ETHERNET CONTROLLER
ISOLATED
WIFI TX/RX
SPI FLASH 512 MB
ISOLATED DALI OUTPUT
2.4" TFT LCD + TOUCH
LDO REGULATORS +3V3DC
ISOLATED DMX OUTPUT
ISOLATED DC/DC CONVERTER +5~+24VDC -> +5VDC
MCU SAM4S
ISOLATED DUAL RGB CHIP OUTPUT

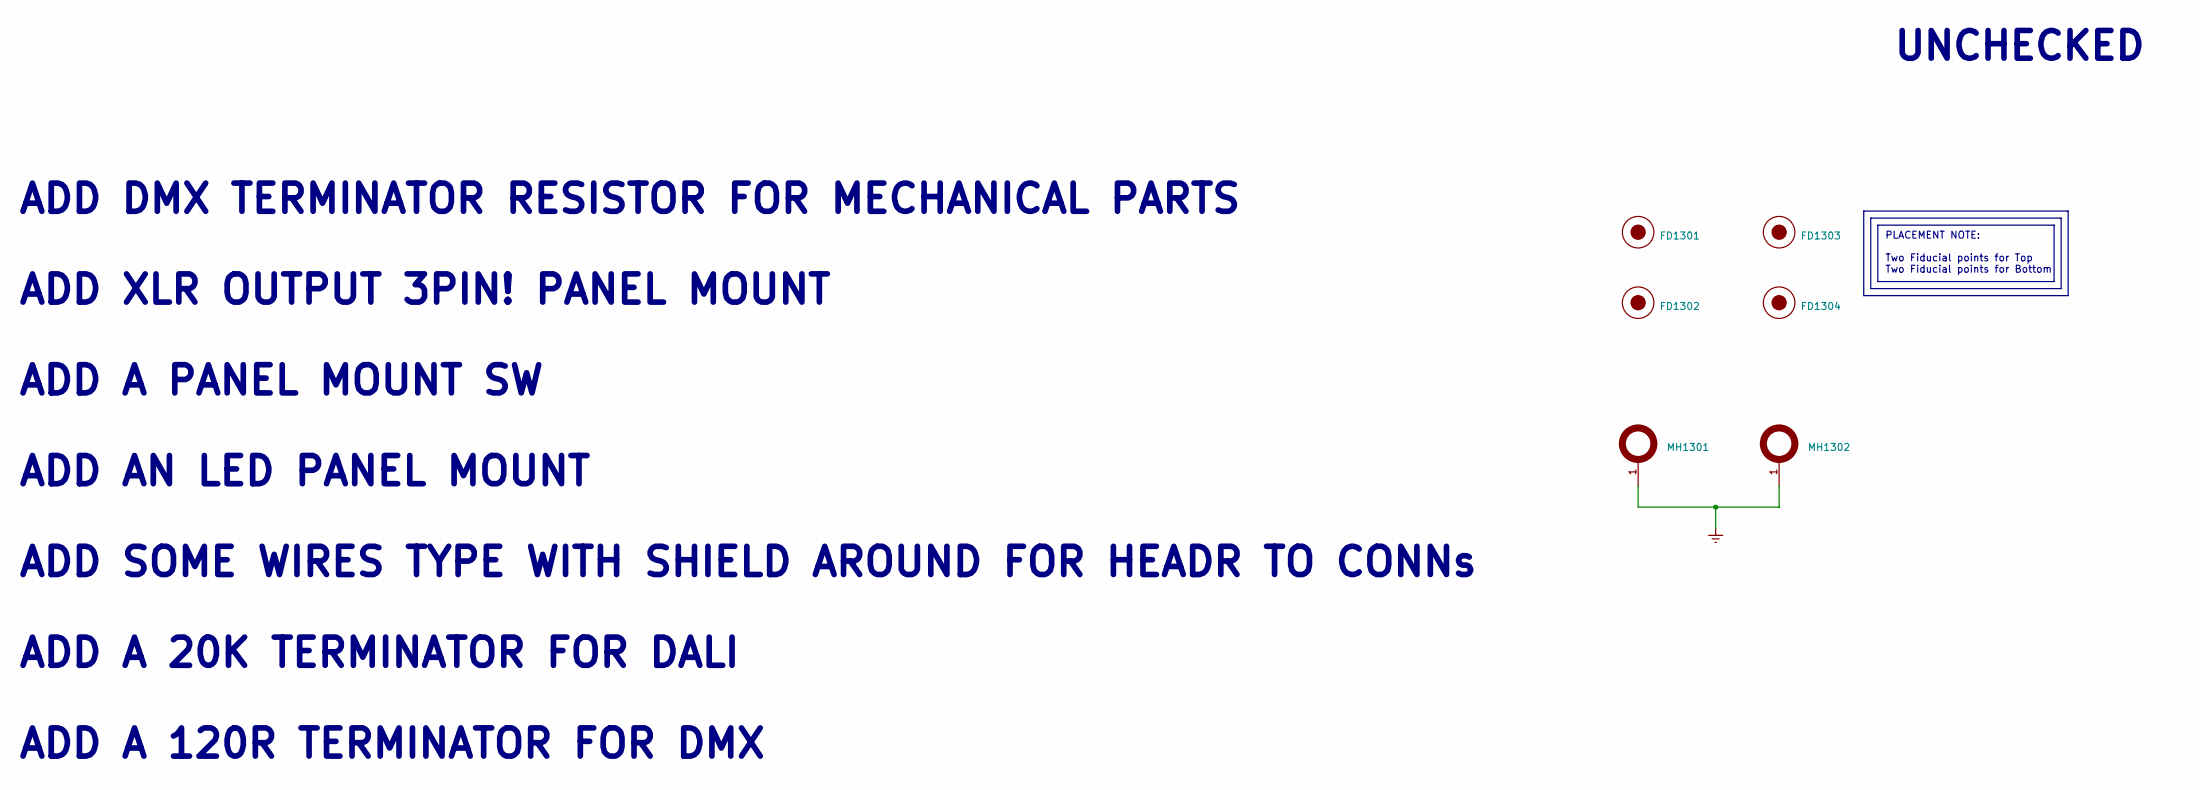
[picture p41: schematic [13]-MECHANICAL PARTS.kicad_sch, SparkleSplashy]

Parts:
FD1301, FD1302, FD1303, FD1304: Fiducial_0.5mm_Mask1mm
MH1301, MH1302: MountingHole_2.2mm_M2_DIN965_Pad_TopBottom

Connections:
Earth: MH1301.1, MH1302.1; also elsewhere on the board

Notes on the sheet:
ADD DMX TERMINATOR RESISTOR FOR MECHANICAL PARTS ADD XLR OUTPUT 3PIN! PANEL MOUNT ADD A PANEL MOUNT SW ADD AN LED PANEL MOUNT ADD SOME WIRES TYPE WITH SHIELD AROUND FOR HEADR TO CONNs ADD A 20K TERMINATOR FOR DALI ADD A 120R TERMINATOR FOR DMX
PLACEMENT NOTE: Two Fiducial points for Top Two Fiducial points for Bottom
UNCHECKED

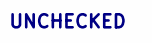
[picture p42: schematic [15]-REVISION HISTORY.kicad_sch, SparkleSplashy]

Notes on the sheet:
UNCHECKED

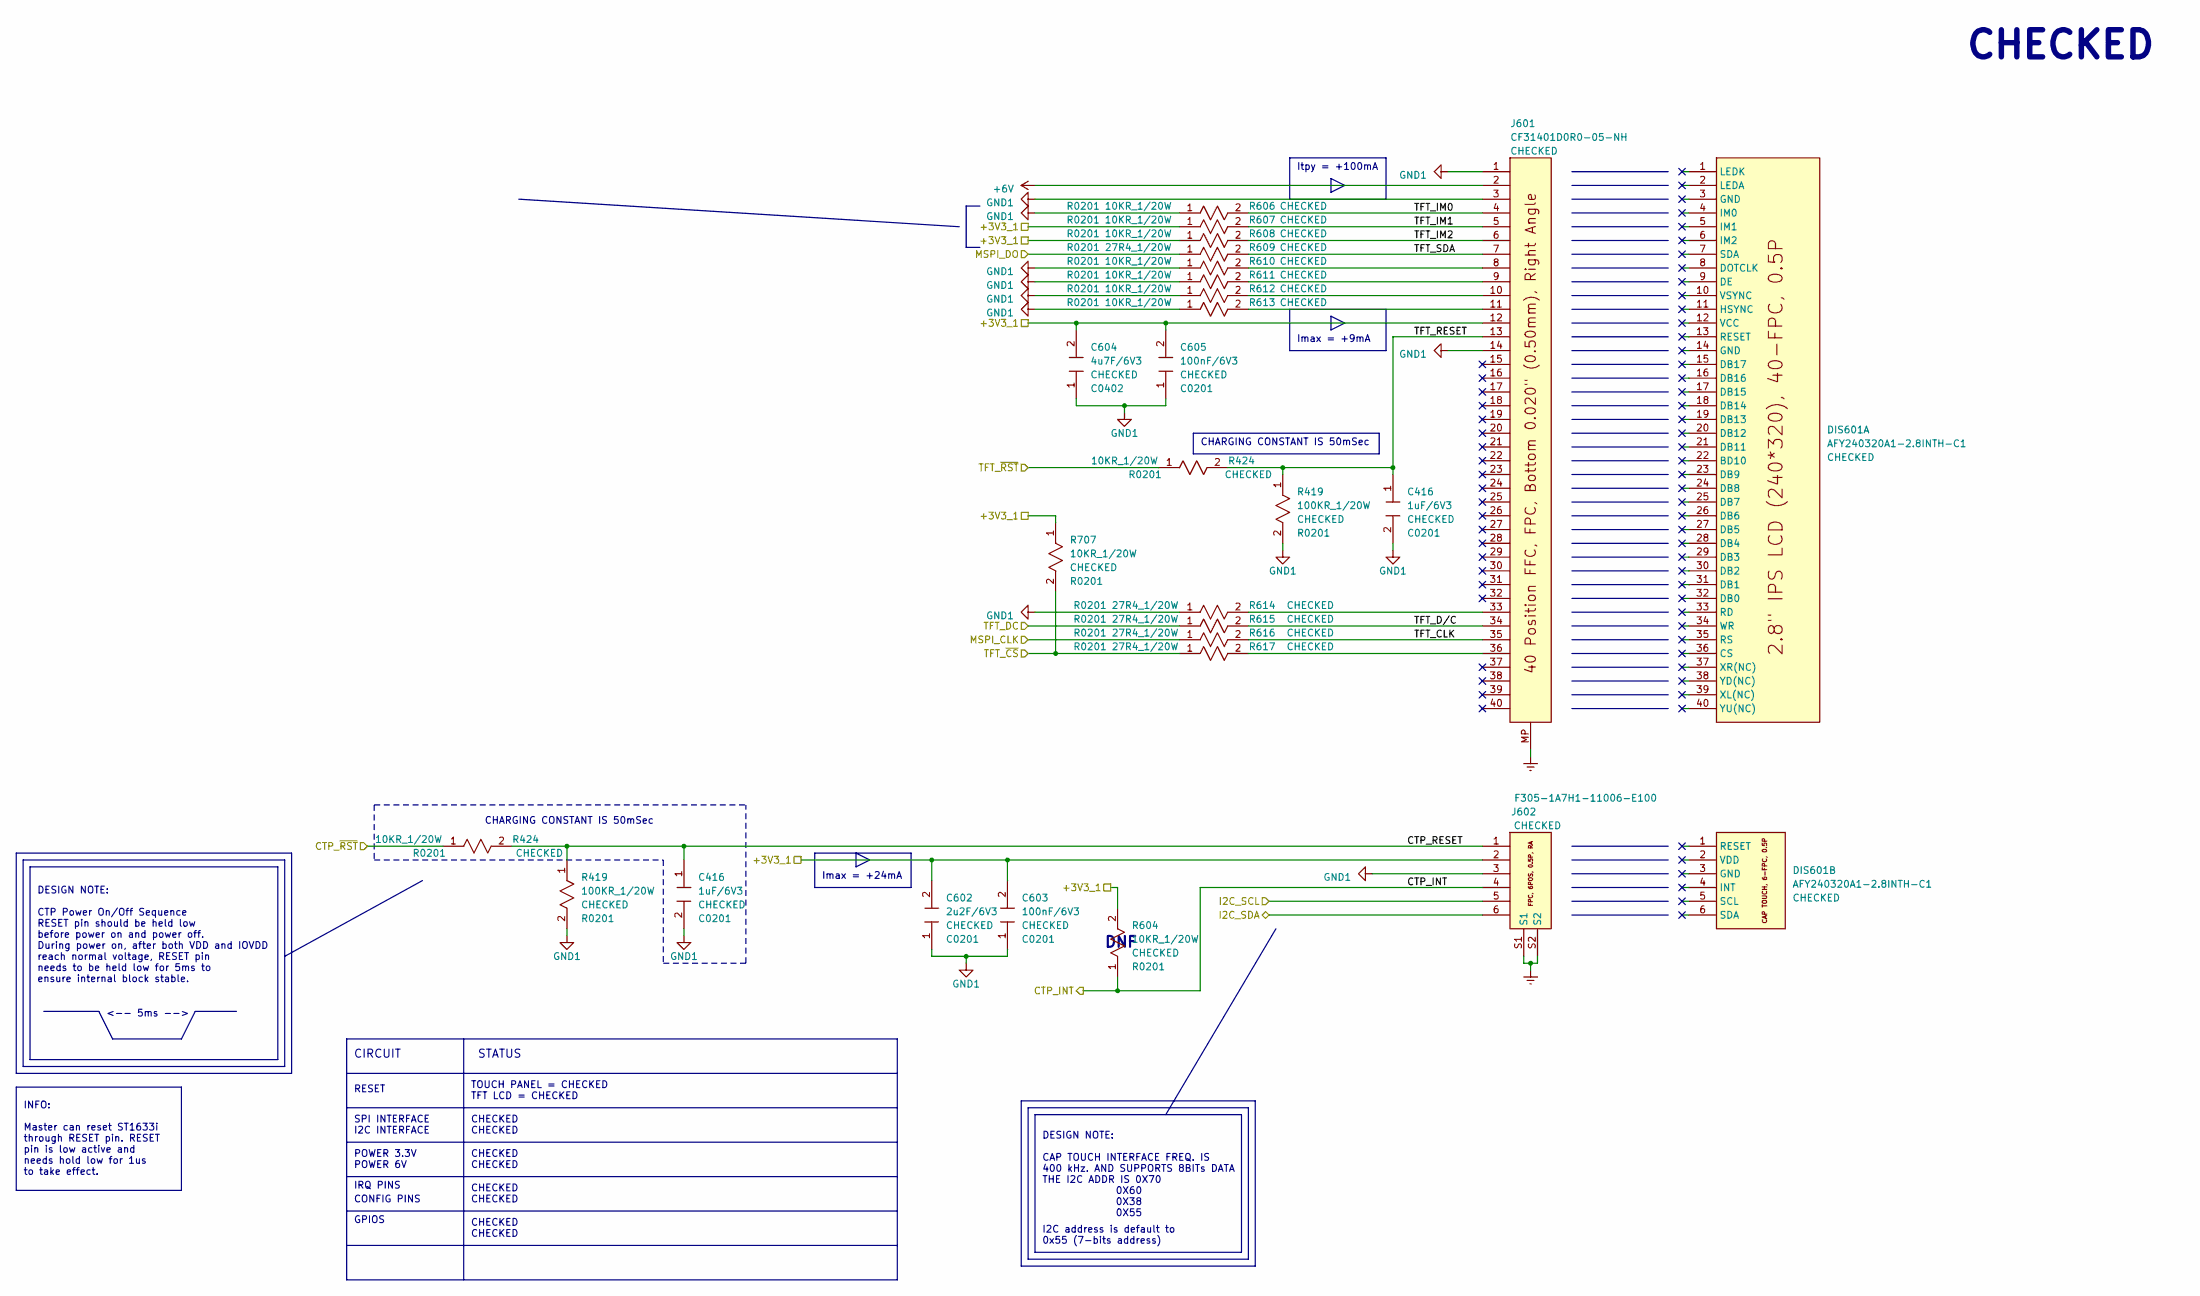
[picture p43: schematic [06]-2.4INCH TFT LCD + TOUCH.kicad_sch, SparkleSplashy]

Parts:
C416: 1uF/6V3; C_0201_0603Metric; Part Number CL03A105MQ3CSNH
C602: 2u2F/6V3; C_0201_0603Metric; Part Number CM03X5R225M06AH
C603, C605: 100nF/6V3; C_0201_0603Metric; Part Number CC0201KRX7R5BB104
C604: 4u7F/6V3; C_0402_1005Metric; Part Number CL05A475KQ5NRNC
DIS601: AFY240320A1-2.8INTH-C1; Part Number AFY240320A1-2.8INTH-C1
J601: CF31401D0R0-05-NH; FPC_FH12-40S-0.5SH_1x40-1MP_P0.50mm_Horizontal; Part Number CF31401D0R0-05-NH
J602: F305-1A7H1-11006-E100; CONN_FPC_6POS_0.5P,BOTTOM; Part Number F305-1A7H1-11006-E100
R419: 100KR_1/20W; R_0201_0603Metric; Part Number ERJ-1GNF1003C
R424, R604, R606, R607, R608, R610, R611, R612, R613, R707: 10KR_1/20W; R_0201_0603Metric; Part Number RMCF0201FT10K0
R609, R614, R615, R616, R617: 27R4_1/20W; R_0201_0603Metric; Part Number RC0201FR-0727R4L

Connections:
+6V: J601.2; also elsewhere on the board
/BLOCK DIAGRAM/2.4" TFT LCD + TOUCH/TFT_CLK: J601.35, R616.2
/BLOCK DIAGRAM/2.4" TFT LCD + TOUCH/TFT_D/C: J601.34, R615.2
/BLOCK DIAGRAM/2.4" TFT LCD + TOUCH/TFT_IM0: J601.4, R606.2
/BLOCK DIAGRAM/2.4" TFT LCD + TOUCH/TFT_IM1: J601.5, R607.2
/BLOCK DIAGRAM/2.4" TFT LCD + TOUCH/TFT_IM2: J601.6, R608.2
/BLOCK DIAGRAM/2.4" TFT LCD + TOUCH/TFT_SDA: J601.7, R609.2
/BLOCK DIAGRAM/CTP_INT: J602.4, R604.1; also elsewhere on the board
/BLOCK DIAGRAM/I2C_SCL: J602.5; also elsewhere on the board
/BLOCK DIAGRAM/I2C_SDA: J602.6; also elsewhere on the board
/BLOCK DIAGRAM/MSPI_CLK: R616.1; also elsewhere on the board
/BLOCK DIAGRAM/MSPI_DO: R609.1; also elsewhere on the board
/BLOCK DIAGRAM/TFT_DC: R615.1; also elsewhere on the board
Earth: J601.MP, J602.S1, J602.S2; also elsewhere on the board
unnamed: J601.8, R610.2
unnamed: J601.9, R611.2
unnamed: J601.10, R612.2
unnamed: J601.11, R613.2
unnamed: J601.33, R614.2
unnamed: J601.36, R617.2

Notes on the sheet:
TOUCH PANEL = CHECKED TFT LCD = CHECKED
STATUS
CIRCUIT
CHECKED CHECKED
SPI INTERFACE I2C INTERFACE
CONFIG PINS
POWER 3.3V POWER 6V
DESIGN NOTE: CTP Power On/Off Sequence RESET pin should be held low before power on and power off. During power on, after both VDD and IOVDD reach normal voltage, RESET pin needs to be held low for 5ms to ensure internal block stable.
DESIGN NOTE: CAP TOUCH INTERFACE FREQ. IS 400 kHz. AND SUPPORTS 8BITs DATA THE I2C ADDR IS 0X70 0X60 0X38 0X55
GPIOS
I2C address is default to 0x55 (7-bits address)
Imax = +24mA
IRQ PINS
Itpy = +100mA
<-- 5ms -->
INFO: Master can reset ST1633i through RESET pin. RESET pin is low active and needs hold low for 1us to take effect.
CHARGING CONSTANT IS 50mSec
DNF
RESET
Imax = +9mA
CHECKED

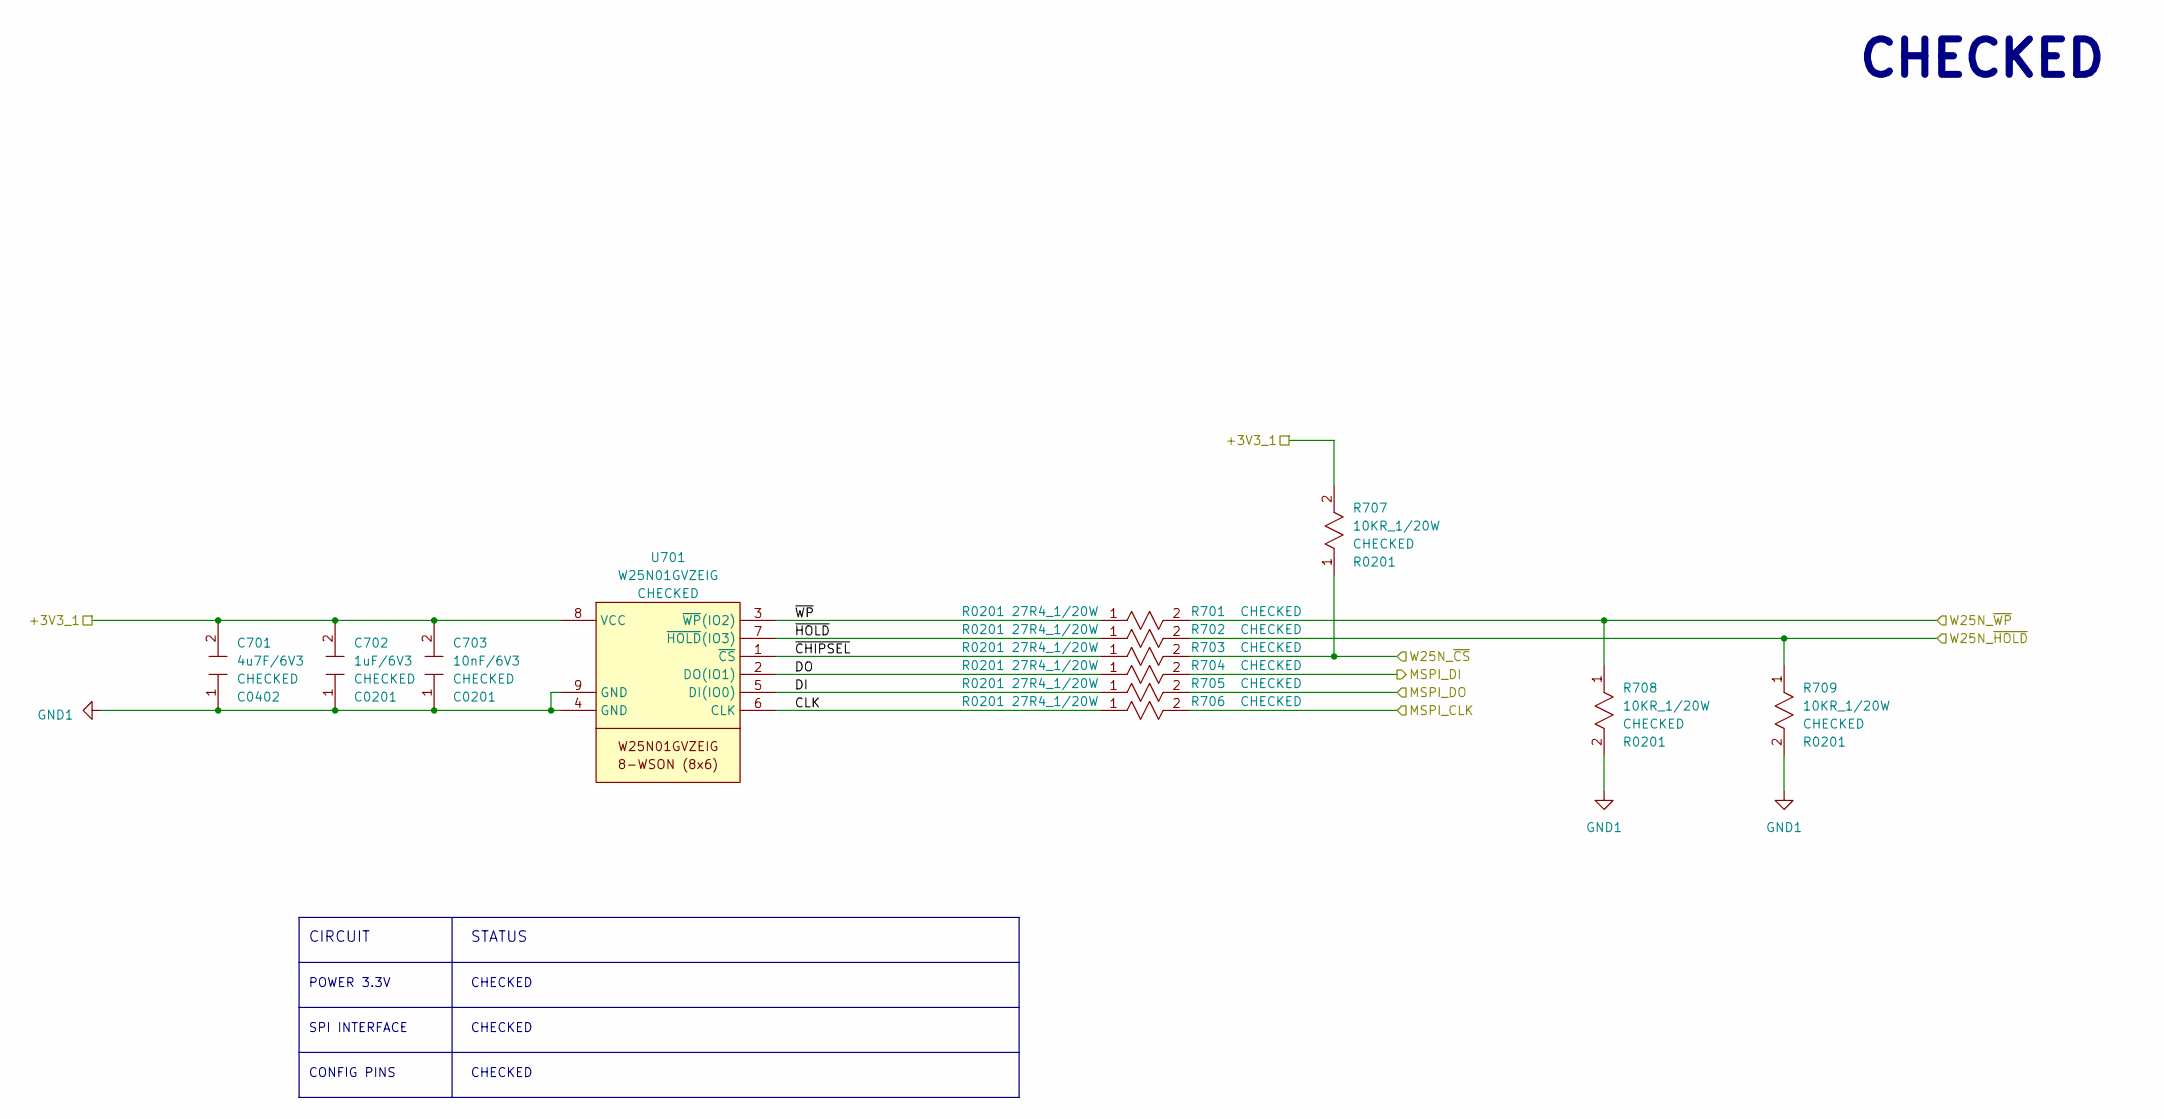
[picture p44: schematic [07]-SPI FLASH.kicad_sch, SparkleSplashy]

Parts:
C701: 4u7F/6V3; C_0402_1005Metric; Part Number CL05A475KQ5NRNC
C702: 1uF/6V3; C_0201_0603Metric; Part Number CL03A105MQ3CSNH
C703: 10nF/6V3; C_0201_0603Metric; Part Number 0201B103K6R3CT
R701, R702, R703, R704, R705, R706: 27R4_1/20W; R_0201_0603Metric; Part Number RC0201FR-0727R4L
R707, R708, R709: 10KR_1/20W; R_0201_0603Metric; Part Number RMCF0201FT10K0
U701: W25N01GVZEIG; WSON-8-1EP_8x6mm_P1.27mm_EP3.4x4.3mm; Part Number W25N01GVZEIG

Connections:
/BLOCK DIAGRAM/512MB SPI FLASH/CLK: R706.1, U701.6 (CLK)
/BLOCK DIAGRAM/512MB SPI FLASH/DI: R705.1, U701.5 (DI(IO0))
/BLOCK DIAGRAM/512MB SPI FLASH/DO: R704.1, U701.2 (DO(IO1))
/BLOCK DIAGRAM/512MB SPI FLASH/~CHIPSEL: R703.1, U701.1 (~CS)
/BLOCK DIAGRAM/512MB SPI FLASH/~HOLD: R702.1, U701.7 (~HOLD(IO3))
/BLOCK DIAGRAM/512MB SPI FLASH/~WP: R701.1, U701.3 (~WP(IO2))
/BLOCK DIAGRAM/MSPI_CLK: R706.2; also elsewhere on the board
/BLOCK DIAGRAM/MSPI_DI: R704.2; also elsewhere on the board
/BLOCK DIAGRAM/MSPI_DO: R705.2; also elsewhere on the board
/BLOCK DIAGRAM/W25N_~HOLD: R702.2, R709.1; also elsewhere on the board
/BLOCK DIAGRAM/W25N_~WP: R701.2, R708.1; also elsewhere on the board

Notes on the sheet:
CHECKED
CONFIG PINS
CIRCUIT
POWER 3.3V
STATUS
SPI INTERFACE

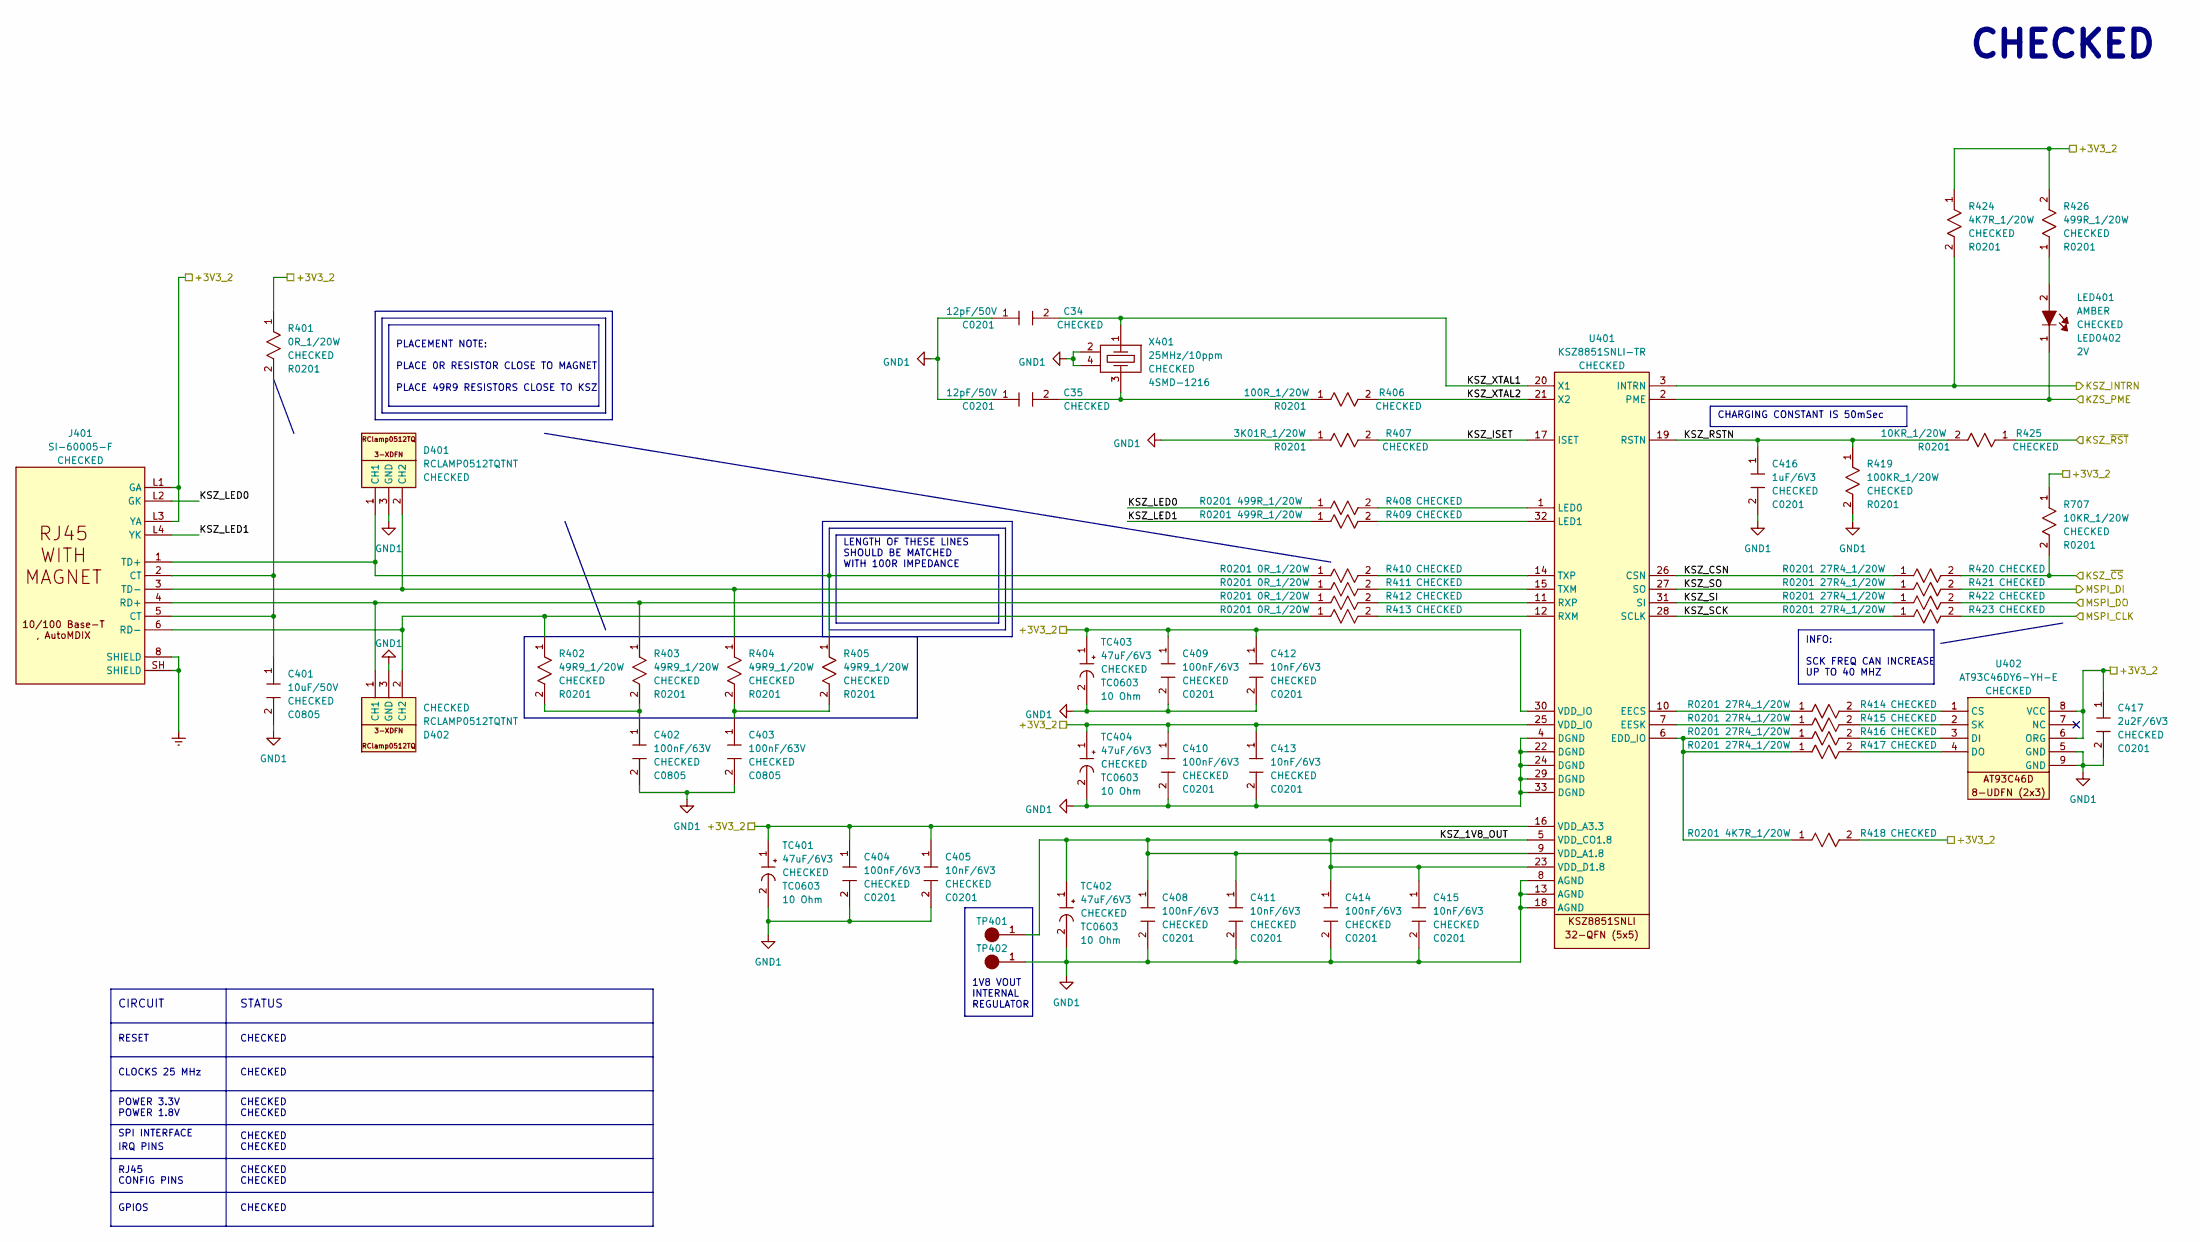
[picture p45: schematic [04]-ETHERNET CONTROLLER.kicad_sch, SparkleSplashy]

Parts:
C34, C35: 12pF/50V; C_0201_0603Metric; Part Number CC0201JRNPO9BN120
C401: 10uF/50V; C_0805_2012Metric; Part Number GRM21BR61H106KE43L
C402, C403: 100nF/63V; C_0805_2012Metric; Part Number C0805C104MMREC7210
C404, C408, C409, C410, C414: 100nF/6V3; C_0201_0603Metric; Part Number CC0201KRX7R5BB104
C405, C411, C412, C413, C415: 10nF/6V3; C_0201_0603Metric; Part Number 0201B103K6R3CT
C416: 1uF/6V3; C_0201_0603Metric; Part Number CL03A105MQ3CSNH
C417: 2u2F/6V3; C_0201_0603Metric; Part Number CM03X5R225M06AH
D401, D402: RCLAMP0512TQTNT; 3-XDFN; Part Number RCLAMP0512TQTNT
J401: SI-60005-F; RJ45_Bel_SI-60062-F; Part Number SI-60005-F
LED401: AMBER; LED_0402_1005Metric; VOLTAGE RATED 2V; Part Number B2841UY--20D000414U1930
R401, R410, R411, R412, R413: 0R_1/20W; R_0201_0603Metric; Part Number RMCF0201ZT0R00
R402, R403, R404, R405: 49R9_1/20W; R_0201_0603Metric; Part Number RMCF0201FT49R9
R406: 100R_1/20W; R_0201_0603Metric; Part Number RMCF0201FT100R
R407: 3K01R_1/20W; R_0201_0603Metric; Part Number RC0201FR-073K01L
R408, R409, R426: 499R_1/20W; R_0201_0603Metric; Part Number RMCF0201FT499R
R414, R415, R416, R417, R420, R421, R422, R423: 27R4_1/20W; R_0201_0603Metric; Part Number RC0201FR-0727R4L
R418, R424: 4K7R_1/20W; R_0201_0603Metric; Part Number RMCF0201FT4K70
R419: 100KR_1/20W; R_0201_0603Metric; Part Number ERJ-1GNF1003C
R425, R707: 10KR_1/20W; R_0201_0603Metric; Part Number RMCF0201FT10K0
TC401, TC402, TC403, TC404: 47uF/6V3; CP_EIA-1608-08_AVX-J; Part Number F980J476MMA
TP401, TP402: TestPoint_Pad_D1.0mm
U401: KSZ8851SNLI-TR; QFN-32-1EP_5x5mm_P0.5mm_EP3.1x3.1mm_ThermalVias; Part Number KSZ8851SNLI-TR
U402: AT93C46DY6-YH-E; DFN-8-1EP_3x2mm_P0.5mm_EP1.3x1.5mm; Part Number AT93C46DY6-YH-E
X401: 25MHz/10ppm; Crystal_4SMD_1216_4Pin_1.2X1.6mm; Part Number Q 25,0-JXS11-12-10/10-FU-LF

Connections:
/BLOCK DIAGRAM/ETHERNET CONTROLLER/KSZ_1V8_OUT: C408.1, C411.1, C414.1, C415.1, TC402.1, TP401.1, U401.5 (VDD_CO1.8), U401.9 (VDD_A1.8), U401.23 (VDD_D1.8)
/BLOCK DIAGRAM/ETHERNET CONTROLLER/KSZ_CSN: R420.1, U401.26 (CSN)
/BLOCK DIAGRAM/ETHERNET CONTROLLER/KSZ_ISET: R407.2, U401.17 (ISET)
/BLOCK DIAGRAM/ETHERNET CONTROLLER/KSZ_LED0: J401.L2 (GK), R408.1
/BLOCK DIAGRAM/ETHERNET CONTROLLER/KSZ_LED1: J401.L4 (YK), R409.1
/BLOCK DIAGRAM/ETHERNET CONTROLLER/KSZ_SCK: R423.1, U401.28 (SCLK)
/BLOCK DIAGRAM/ETHERNET CONTROLLER/KSZ_SI: R422.1, U401.31 (SI)
/BLOCK DIAGRAM/ETHERNET CONTROLLER/KSZ_SO: R421.1, U401.27 (SO)
/BLOCK DIAGRAM/ETHERNET CONTROLLER/KSZ_XTAL1: U401.20 (X1), X401.1; also elsewhere on the board
/BLOCK DIAGRAM/ETHERNET CONTROLLER/KSZ_XTAL2: R406.2, U401.21 (X2)
/BLOCK DIAGRAM/KSZ_PME: LED401.1, U401.2 (PME); also elsewhere on the board
/BLOCK DIAGRAM/KSZ_~RST: R425.1; also elsewhere on the board
/BLOCK DIAGRAM/MSPI_CLK: R423.2; also elsewhere on the board
/BLOCK DIAGRAM/MSPI_DI: R421.2; also elsewhere on the board
/BLOCK DIAGRAM/MSPI_DO: R422.2; also elsewhere on the board
Earth: J401.8 (SHIELD), J401.SH (SHIELD); also elsewhere on the board
unnamed: C401.1, J401.2 (CT), J401.5 (CT), R401.2
unnamed: C402.1, R402.2, R403.2
unnamed: C403.1, R404.2, R405.2
unnamed 129: R406.1, X401.3; also elsewhere on the board
unnamed: D401.1 (CH1), J401.1 (TD+), R405.1, R410.1
unnamed: D401.2 (CH2), J401.3 (TD-), R404.1, R411.1
unnamed: D402.1 (CH1), J401.4 (RD+), R403.1, R412.1
unnamed: D402.2 (CH2), J401.6 (RD-), R402.1, R413.1
unnamed: LED401.2, R426.1
unnamed: R416.1, R417.1, R418.1, U401.6 (EDD_IO)
unnamed: R414.1, U401.10 (EECS)
unnamed: R415.1, U401.7 (EESK)
unnamed: R408.2, U401.1 (LED0)
unnamed: R409.2, U401.32 (LED1)
unnamed: R413.2, U401.12 (RXM)
unnamed: R412.2, U401.11 (RXP)
unnamed: R411.2, U401.15 (TXM)
unnamed: R410.2, U401.14 (TXP)
unnamed: R414.2, U402.1 (CS)
unnamed: R416.2, U402.3 (DI)
unnamed: R417.2, U402.4 (DO)
unnamed: R415.2, U402.2 (SK)

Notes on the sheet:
LENGTH OF THESE LINES SHOULD BE MATCHED WITH 100R IMPEDANCE
IRQ PINS
CHARGING CONSTANT IS 50mSec
CHECKED CHECKED
CHECKED
INFO: SCK FREQ CAN INCREASE UP TO 40 MHZ
PLACEMENT NOTE: PLACE 0R RESISTOR CLOSE TO MAGNET PLACE 49R9 RESISTORS CLOSE TO KSZ
POWER 3.3V POWER 1.8V
SPI INTERFACE
STATUS
CLOCKS 25 MHz
RESET
GPIOS
1V8 VOUT INTERNAL REGULATOR
RJ45 CONFIG PINS
CIRCUIT

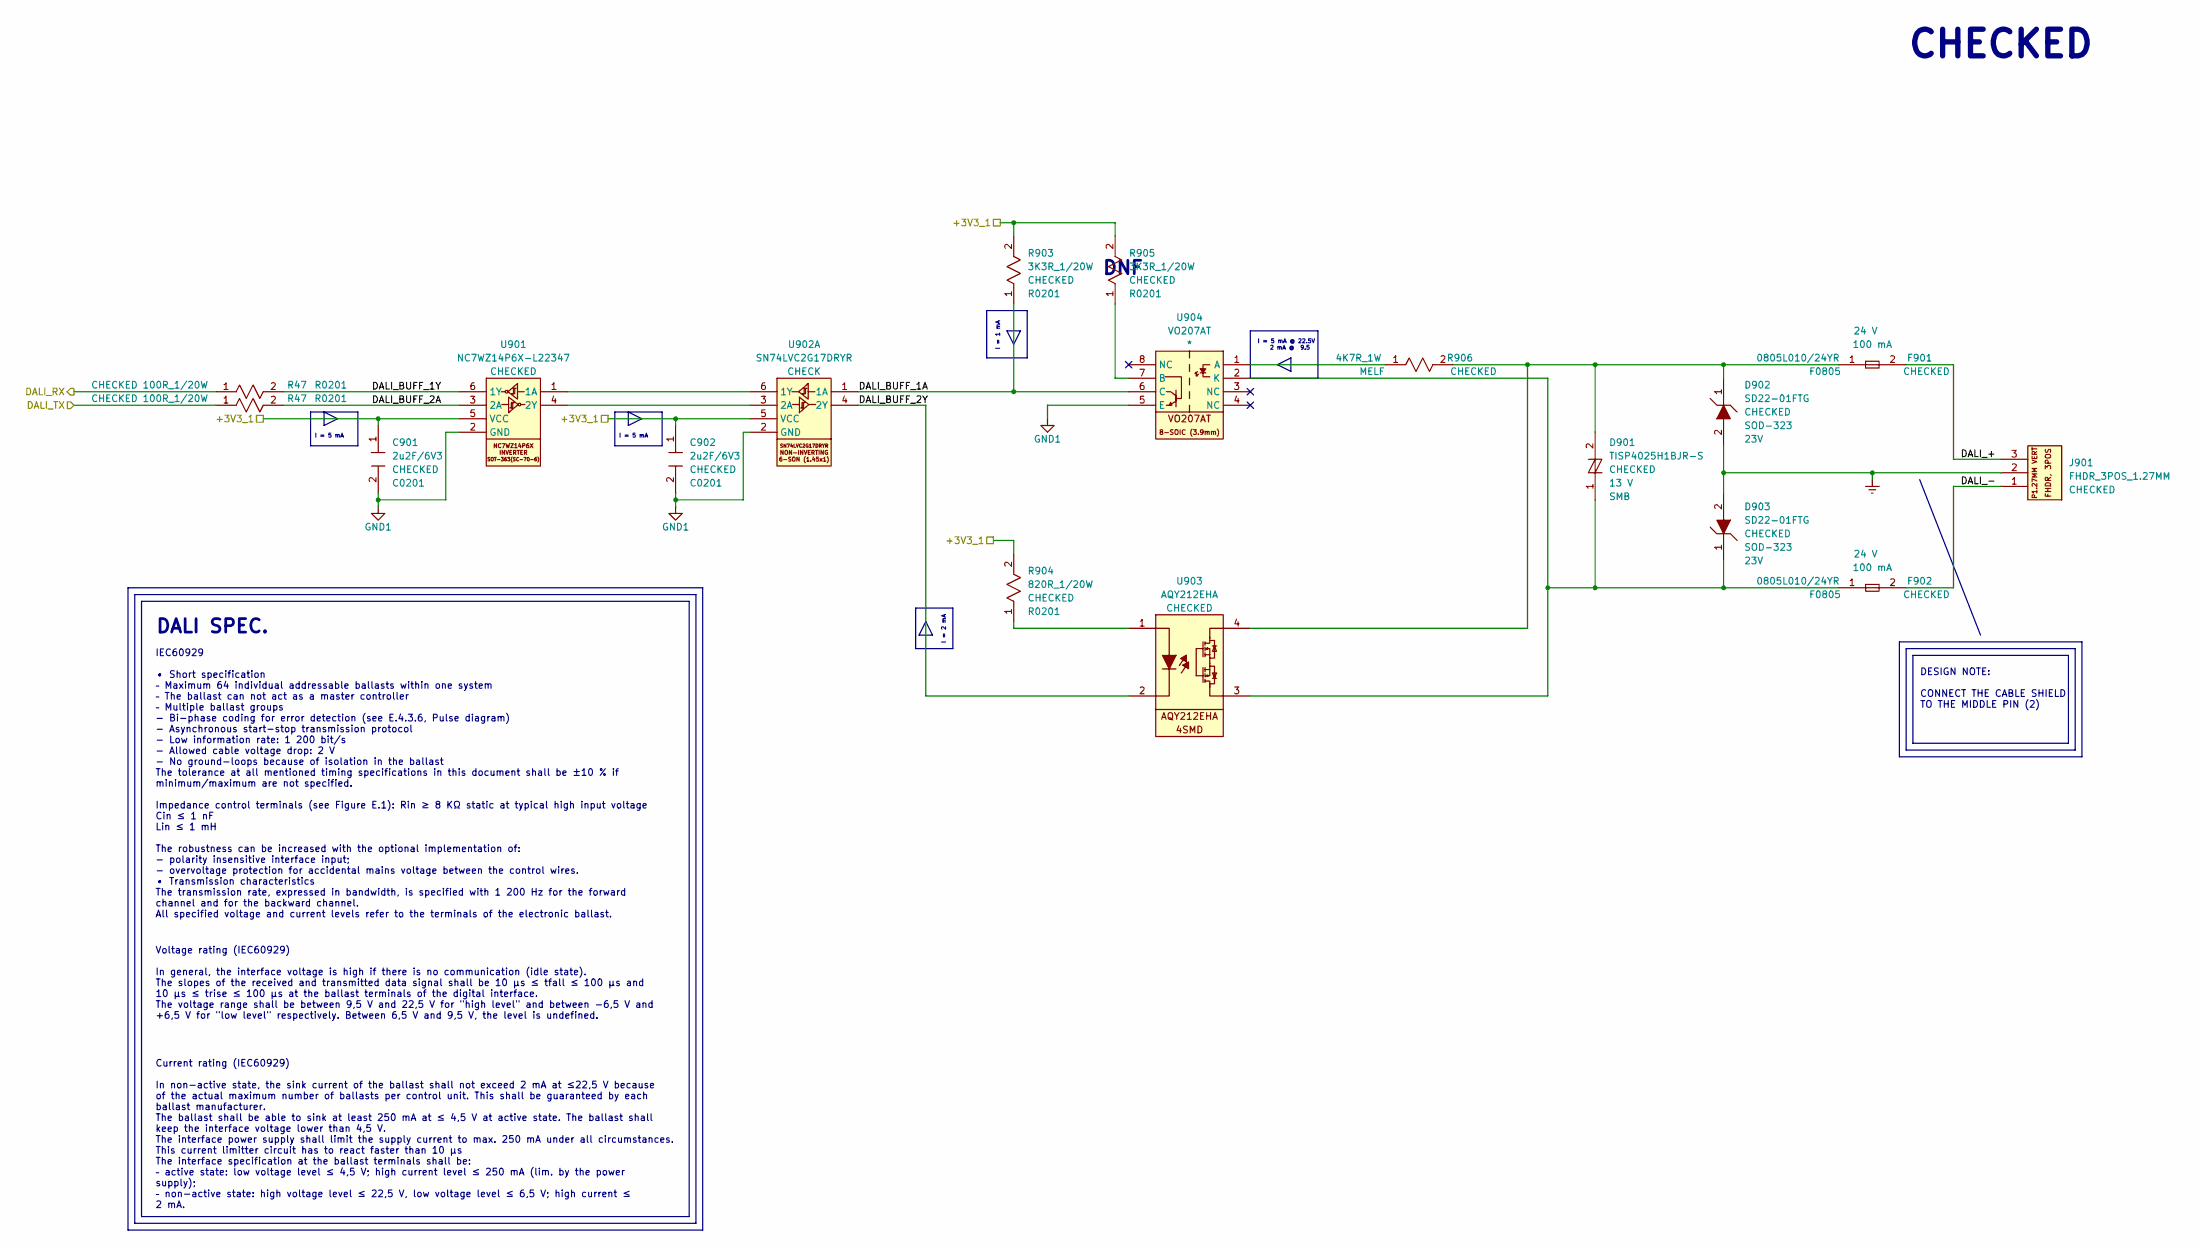
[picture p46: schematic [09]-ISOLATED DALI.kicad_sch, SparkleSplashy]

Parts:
C901, C902: 2u2F/6V3; C_0201_0603Metric; Part Number CM03X5R225M06AH
D901: TISP4025H1BJR-S; D_SMB; Voltage Off State 13 V; Part Number TISP4025H1BJR-S
D902, D903: SD22-01FTG; D_SOD-323; Part Number SD22-01FTG
F901, F902: 0805L010/24YR; Fuse_0805_2012Metric; Voltage Rated 24 V; Part Number 0805L010/24YR
J901: FHDR_3POS_1.27MM; PinHeader_1x03_P1.27mm_Vertical; Part Number BD080-03-A-0230-L-G
R47: 100R_1/20W; R_0201_0603Metric; Part Number RMCF0201FT100R
R903, R905: 3K3R_1/20W; R_0201_0603Metric; Part Number RMCF0201FT3K30
R904: 820R_1/20W; R_0201_0603Metric; Part Number ERJ-1GNF8200C
R906: 4K7R_1W; R_MELF_MMB-0207; Part Number MLFA1FTC4K70
U901: NC7WZ14P6X-L22347; SOT-363_SC-70-6; Part Number NC7WZ14P6X-L22347
U902: SN74LVC2G17DRYR; 6-SON; Part Number SN74LVC2G17DRYR
U903: AQY212EHA; SMDIP-4_W7.62mm; Part Number AQY212EHA
U904: VO207AT; SOIC-8_3.9x4.9mm_P1.27mm; Part Number VO207AT

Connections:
/BLOCK DIAGRAM/ISOLATED DALI/DALI_+: F901.2, J901.3
/BLOCK DIAGRAM/ISOLATED DALI/DALI_-: F902.2, J901.1
/BLOCK DIAGRAM/ISOLATED DALI/DALI_BUFF_1A: R903.1, U902.1 (1A), U904.6 (C)
/BLOCK DIAGRAM/ISOLATED DALI/DALI_BUFF_1Y: U901.6 (1Y); also elsewhere on the board
/BLOCK DIAGRAM/ISOLATED DALI/DALI_BUFF_2A: U901.3 (2A); also elsewhere on the board
/BLOCK DIAGRAM/ISOLATED DALI/DALI_BUFF_2Y: U902.4 (2Y), U903.2
Earth: D902.2, D903.2, J901.2; also elsewhere on the board
unnamed: D901.2, D902.1, F901.1, R906.2, U903.4
unnamed: R904.1, U903.1
unnamed: U901.1 (1A), U902.6 (1Y)
unnamed: U901.4 (2Y), U902.3 (2A)
unnamed: R906.1, U904.1 (A)
unnamed: R905.1, U904.7 (B)
unnamed: D901.1, D903.1, F902.1, U903.3, U904.2 (K)

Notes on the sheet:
DALI SPEC.
Voltage rating (IEC60929) In general, the interface voltage is high if there is no communication (idle state). The slopes of the received and transmitted data signal shall be 10 μs ≤ tfall ≤ 100 μs and 10 μs ≤ trise ≤ 100 μs at the ballast terminals of the digital interface. The voltage range shall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
I = 2 mA
DNF
I = 5 mA @ 22.5V 2 mA @ 9.5
I = 5 mA
Current rating (IEC60929) In non-active state, the sink current of the ballast shall not exceed 2 mA at ≤22,5 V because of the actual maximum number of ballasts per control unit. This shall be guaranteed by each ballast manufacturer. The ballast shall be able to sink at least 250 mA at ≤ 4,5 V at a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
IEC60929 • Short specification – Maximum 64 individual addressable ballasts within one system – The ballast can not act as a master controller – Multiple ballast groups - Bi-phase coding for error detection (see E.4.3.6, Pulse diagram) - Asynchronous start-stop transmission protocol - Low informati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
I = 1 mA
CHECKED
DESIGN NOTE: CONNECT THE CABLE SHIELD TO THE MIDDLE PIN (2)

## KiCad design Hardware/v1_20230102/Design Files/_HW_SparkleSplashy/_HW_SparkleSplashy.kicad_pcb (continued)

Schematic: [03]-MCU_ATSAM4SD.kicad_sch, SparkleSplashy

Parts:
C301, C302, C303, C304, C316, C317, C318, C324, C325, C332: 100nF/6V3; C_0201_0603Metric; Part Number CC0201KRX7R5BB104
C305, C306, C307, C308, C326, C327, C328, C329: 10nF/6V3; C_0201_0603Metric; Part Number 0201B103K6R3CT
C309, C310, C311, C312: 1nF/50V; C_0201_0603Metric; Part Number GRM0335C1H102JE01D
C313, C314, C315, C319, C331: 2u2F/6V3; C_0201_0603Metric; Part Number CM03X5R225M06AH
C320, C321, C322, C323: 12pF/50V; C_0201_0603Metric; Part Number CC0201JRNPO9BN120
C330: 470pF/50V; C_0201_0603Metric; Part Number CGA1A2X7R1H471M030BA
LED301: ORANGE; LED_0402_1005Metric; VOLTAGE RATED 2V; Part Number B2841UD--20D000614U1930
LED302: RED; LED_0402_1005Metric; VOLTAGE RATED 2V; Part Number B2841USD-20D001014U1930
LED303: AMBER; LED_0402_1005Metric; VOLTAGE RATED 2V; Part Number B2841UY--20D000414U1930
R301: 10KR_1/20W; R_0201_0603Metric; Part Number RMCF0201FT10K0
R302, R303, R304, R305, R306: 3K3R_1/20W; R_0201_0603Metric; Part Number RMCF0201FT3K30
R307, R308, R309, R310, R311: 100R_1/20W; R_0201_0603Metric; Part Number RMCF0201FT100R
R312, R313, R314: 499R_1/20W; R_0201_0603Metric; Part Number RMCF0201FT499R
R315, R316: 4K7R_1/20W; R_0201_0603Metric; Part Number RMCF0201FT4K70
TC301, TC302, TC303, TC304, TC305: 47uF/6V3; CP_EIA-1608-08_AVX-J; Part Number F980J476MMA
TP301, TP302, TP303, TP304, TP305, TP306, TP307, TP308, TP309: TestPoint_Pad_D1.0mm
U301: ATSAM4SD16BA-MU; QFN-64-1EP_9x9mm_P0.5mm_EP7.3x7.3mm_ThermalVias; Part Number ATSAM4SD16BA-MU
U302: SN74LVC2G17DRYR; 6-SON; Part Number SN74LVC2G17DRYR
X301: 16MHz/10ppm; Crystal_SMD_2016-4Pin_2.0x1.6mm; Part Number ECS-160-12-37B-CTN-TR
X302: 32.768 kHz/5ppm; Crystal_SMD_EuroQuartz_EQ161-2Pin_3.2x1.5mm; Part Number CM315D32768HZFT

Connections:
/BLOCK DIAGRAM/ATWIL_EN: U301.26 (PA26/PGMD14); also elsewhere on the board
/BLOCK DIAGRAM/ATWIL_IRNQ: U301.38 (PA28); also elsewhere on the board
/BLOCK DIAGRAM/ATWIL_~CS: U301.42 (PA30); also elsewhere on the board
/BLOCK DIAGRAM/ATWIL_~RST: R312.2, U301.57 (DDP/PB11); also elsewhere on the board
/BLOCK DIAGRAM/CTP_INT: U301.37 (PA27/PGMD15); also elsewhere on the board
/BLOCK DIAGRAM/CTP_~RST: U301.3 (PB0/AD4); also elsewhere on the board
/BLOCK DIAGRAM/DALI_RX: U301.35 (PA5/PGMRDY); also elsewhere on the board
/BLOCK DIAGRAM/DALI_TX: U301.34 (PA6/PGMNOE); also elsewhere on the board
/BLOCK DIAGRAM/DMX_RX: U301.30 (PA9/PGMM1); also elsewhere on the board
/BLOCK DIAGRAM/DMX_TX: U301.29 (PA10/PGMM2); also elsewhere on the board
/BLOCK DIAGRAM/I2C_SCL: R315.2, U301.36 (PA4/PGMNCMD); also elsewhere on the board
/BLOCK DIAGRAM/I2C_SDA: R316.2, U301.43 (PA3); also elsewhere on the board
/BLOCK DIAGRAM/KSZ_PME: U301.16 (PA20/PGMD8/AD3); also elsewhere on the board
/BLOCK DIAGRAM/KSZ_~RST: R314.2, U301.23 (PA24/PGMD12); also elsewhere on the board
/BLOCK DIAGRAM/LDO REGULATORS/ATWIL_PWR_EN: U301.56 (DDM/PB10); also elsewhere on the board
/BLOCK DIAGRAM/LDO REGULATORS/BKL_EN: U301.59 (PB13/DAC0); also elsewhere on the board
/BLOCK DIAGRAM/LDO REGULATORS/KSZ_PWR_EN: U301.25 (PA25/PGMD13); also elsewhere on the board
/BLOCK DIAGRAM/LDO REGULATORS/PWR_EN: U301.63 (PB14/DAC1); also elsewhere on the board
/BLOCK DIAGRAM/MCU_ATSAM4SD/MCU_ADVREF: R309.2, U301.1 (ADVREF)
/BLOCK DIAGRAM/MCU_ATSAM4SD/MCU_ERASE: R302.2, U301.55 (ERASE/PB12)
/BLOCK DIAGRAM/MCU_ATSAM4SD/MCU_JTAGSEL: R307.2, TP306.1, U301.50 (JTAGSEL)
/BLOCK DIAGRAM/MCU_ATSAM4SD/MCU_NRST: C324.2, R301.2, TP307.1, U301.39 (NRST)
/BLOCK DIAGRAM/MCU_ATSAM4SD/MCU_SPI_CLK: U301.21 (PA14/PGMD2), U302.3 (2A)
/BLOCK DIAGRAM/MCU_ATSAM4SD/MCU_SPI_SDO: U301.22 (PA13/PGMD1), U302.1 (1A)
/BLOCK DIAGRAM/MCU_ATSAM4SD/MCU_TCK: R305.2, U301.53 (TCK/SWCLK/PB7)
/BLOCK DIAGRAM/MCU_ATSAM4SD/MCU_TDI: R303.2, U301.33 (TDI/PB4)
/BLOCK DIAGRAM/MCU_ATSAM4SD/MCU_TDO: R304.2, U301.49 (TDO/TRACESWO/PB5)
/BLOCK DIAGRAM/MCU_ATSAM4SD/MCU_TMS: R306.2, U301.51 (TMS/SWDIO/PB6)
/BLOCK DIAGRAM/MCU_ATSAM4SD/MCU_TST: R308.2, U301.40 (TST)
/BLOCK DIAGRAM/MCU_ATSAM4SD/MCU_VOUT_1V2: C313.2, C314.2, C315.2, C316.2, C317.2, C318.2, C319.2, C325.2, C326.2, C327.2, C328.2, C329.2, C330.2, TC305.1, TP308.1, U301.8 (VDDOUT_1V2), U301.12 (VDDCORE_1V2), U301.24 (VDDCORE_1V2), U301.54 (VDDCORE_1V2), U301.64 (VDDPLL_1V2)
/BLOCK DIAGRAM/MCU_ATSAM4SD/MCU_XIN: C320.2, U301.62 (XIN/PGMCK/PB9), X301.1
/BLOCK DIAGRAM/MCU_ATSAM4SD/MCU_XIN_32: C322.2, U301.32 (PA7/XIN32/PGMNVALID), X302.2
/BLOCK DIAGRAM/MCU_ATSAM4SD/MCU_XOUT: R310.2, U301.61 (XOUT/PB8)
/BLOCK DIAGRAM/MCU_ATSAM4SD/MCU_XOUT_32: R311.2, U301.31 (PA8/XOUT32/PGMM0)
/BLOCK DIAGRAM/MCU_ATSAM4SD/PGMR_TCK: R305.1, TP304.1
/BLOCK DIAGRAM/MCU_ATSAM4SD/PGMR_TDI: R303.1, TP302.1
/BLOCK DIAGRAM/MCU_ATSAM4SD/PGMR_TDO: R304.1, TP303.1
/BLOCK DIAGRAM/MCU_ATSAM4SD/PGMR_TMS: R306.1, TP305.1
/BLOCK DIAGRAM/MSPI_CLK: U302.4 (2Y); also elsewhere on the board
/BLOCK DIAGRAM/MSPI_DI: U301.27 (PA12/PGMD0); also elsewhere on the board
/BLOCK DIAGRAM/MSPI_DO: U302.6 (1Y); also elsewhere on the board
/BLOCK DIAGRAM/RGB_1_SIG: U301.48 (PA0/PGMEN0); also elsewhere on the board
/BLOCK DIAGRAM/RGB_2_SIG: U301.47 (PA1/PGMEN1); also elsewhere on the board
/BLOCK DIAGRAM/TFT_DC: U301.41 (PA29); also elsewhere on the board
/BLOCK DIAGRAM/TFT_~RST: U301.4 (PB1/AD5); also elsewhere on the board
/BLOCK DIAGRAM/W25N_~HOLD: U301.5 (PB2/AD6); also elsewhere on the board
/BLOCK DIAGRAM/W25N_~WP: U301.13 (PA19/PGMD7/AD2); also elsewhere on the board
unnamed: C321.2, R310.1, X301.3
unnamed: C323.2, R311.1, X302.1
unnamed: LED301.2, R312.1
unnamed: LED302.2, R313.1
unnamed: LED303.2, R314.1
unnamed: LED302.1, U301.44 (PA2/PGMEN2)

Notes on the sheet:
STATUS
CLOCKS 16 MHz CLOCK 32 KHz
DNF
CHECKED CHECKED
RESET
INFO: (JTAGSEL PIN) JTAGSEL pin Must be tied to VDDIO to enter JTAG Boundary Scan. In harsh environments, it is strongly recommended to tie this pin to GND.
INFO: (CEXT FOR XTAL) Internal Equivalent Load C apacitance (CL): CL = 9.5pF Crystal Load Capacitance, ESR, Drive Level, and Shunt Capacitance to validate The external load capacitance is calculated with the following formula: CLEXT = 2 * (Ccrystal-CL) Refer to the Crystal Oscillators Design Consid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
PROGRAMMER PINS CONFIG PINS
INFO: (CEXT FOR XTAL-32) Internal parasitic capacitance Cpara=0.7pF Crystal Load Capacitance, ESR, Drive Level, and Shunt Capacitance to validate. CLEXTmax = 20pF CLEXT= 2 * (Ccrystal-Cpara- Cpcb) Refer to the Crystal Oscillators Design Consideration Information section of the SAM4S Series Datashee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
PLACEMENT NOTE: 1- NRST 2- VDD 3- GND 4- TDO/SWO 5- TCK/SWCLK 7- TDI 8- TMS/SWDIO
INFO: 3.3kR RES HAS BEEN CHOSEN TO PROTECT THE PINS FROM 5V
INFO: (TST PIN) In harsh environments, it is strongly recommended to tie TST pin to GND.
INFO: (ERASE PIN) ERASE/PB12 must be tied to VDDIO to erase the General Purpose NVM bits (GPNVMx), the whole Flash content and the security bit. Reset state: Erase Input, with a 100kΩ Internal pull down and Schmitt trigger enabled.
IRQ PINS
CIRCUIT
POWER 3.3V POWER 1.2V
SPI INTERFACE
CHECKED
INFO: (ADVREF PIN) To reduce power consumption, if analog features are not used, connect ADVREF to GND.
GPIOS
INFO: (NRST PIN) Internal pull-down resistor (100kΩ). Must be tied to VDDIO to erase the General Purpose NVM bits (GPNVMx), the whole Flash content and the security bit. Reset state: Erase Input, with a 100kΩ Internal pull down and Schmitt trigger enabled. Minimum debouncing time is 220ms

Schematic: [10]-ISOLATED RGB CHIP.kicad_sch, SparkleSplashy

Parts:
C1001, C1002, C1004: 2u2F/6V3; C_0201_0603Metric; Part Number CM03X5R225M06AH
C1003, C1005: 100nF/6V3; C_0201_0603Metric; Part Number CC0201KRX7R5BB104
J1001: FHDR_4POS_1.27MM; PinHeader_1x04_P1.27mm_Vertical; Part Number BD080-04-A-0230-L-D
Q1001, Q1002: 2N7002AQ-7; SOT-23; Part Number 2N7002AQ-7
R1001, R1002, R1003, R1004, R1007, R1008: 100R_1/20W; R_0201_0603Metric; Part Number RMCF0201FT100R
R1005, R1006: 10R_1/20W; R_0201_0603Metric; Part Number RMCF0201JT10R0
R1009, R1011: 47KR_1/20W; R_0201_0603Metric; Part Number RMCF0201JT47K0
R1010, R1012: 1KR_1W; R_MELF_MMB-0207; Part Number MLFA1FTC1K00
U1001: SN74LVC2G17DRYR; 6-SON; Part Number SN74LVC2G17DRYR
U1002: ISO7720FDR; SOIC-8_3.9x4.9mm_P1.27mm; Part Number ISO7720FDR

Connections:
/BLOCK DIAGRAM/ISOLATED RGB CHIP/ISO7720_INA: R1003.2, U1002.2 (INA)
/BLOCK DIAGRAM/ISOLATED RGB CHIP/ISO7720_INB: R1004.2, U1002.3 (INB)
/BLOCK DIAGRAM/ISOLATED RGB CHIP/ISO7720_VCC1: C1002.2, C1003.2, R1005.1, U1002.1 (VCC1)
/BLOCK DIAGRAM/ISOLATED RGB CHIP/ISO7720_VCC2: C1004.1, C1005.1, R1006.1, U1002.8 (VCC2)
/BLOCK DIAGRAM/ISOLATED RGB CHIP/RGB_BUFF_1A: R1002.2, U1001.3 (2A)
/BLOCK DIAGRAM/ISOLATED RGB CHIP/RGB_BUFF_1Y: R1004.1, U1001.4 (2Y)
/BLOCK DIAGRAM/ISOLATED RGB CHIP/RGB_BUFF_2A: R1001.2, U1001.1 (1A)
/BLOCK DIAGRAM/ISOLATED RGB CHIP/RGB_BUFF_2Y: R1003.1, U1001.6 (1Y)
/BLOCK DIAGRAM/ISOLATED RGB CHIP/RGB_DATA/CLK_1: J1001.1, Q1001.3, R1010.1
/BLOCK DIAGRAM/ISOLATED RGB CHIP/RGB_DATA/CLK_2: J1001.2, Q1002.3, R1012.1
/BLOCK DIAGRAM/RGB_1_SIG: R1002.1; also elsewhere on the board
/BLOCK DIAGRAM/RGB_2_SIG: R1001.1; also elsewhere on the board
Earth: J1001.4; also elsewhere on the board
unnamed: Q1001.1, R1007.2, R1009.2
unnamed: Q1002.1, R1008.2, R1011.2
unnamed: R1007.1, U1002.7 (OUTA)
unnamed: R1008.1, U1002.6 (OUTB)
VCC: R1010.2, R1012.2; also elsewhere on the board

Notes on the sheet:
DESIGN NOTE: OUTPUT FREQ. START FROM 800KHz AND CAN REACH UP TO 30MHz
I = 12 mA @ 12V 5 mA @ 5V
Imax = 15 mA
CHECKED
LAYOUT NOTE:
Fc = 7.23 kHz 159 kHz
I = 5 mA
I = 12 mA @ 12v 5 mA @ 5V
A minimum of four layers is required to accomplish a low EMI PCB design (see Figure 27). Layer stacking should be in the following order (top-to-bottom): high-speed signal layer, ground plane, power plane and low-frequency signal layer. • Routing the high-speed traces on the top layer avoids the us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

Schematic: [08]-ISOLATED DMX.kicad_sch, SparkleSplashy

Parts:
C801, C802, C804: 2u2F/6V3; C_0201_0603Metric; Part Number CM03X5R225M06AH
C803, C805: 100nF/6V3; C_0201_0603Metric; Part Number CC0201KRX7R5BB104
D801: TISP4011H1BJR-S; D_SMB; Voltage Off State 5.25V; Part Number TISP4011H1BJR-S
D802, D803: ESDZV5H-1BU2; Nexperia_DSN0603-2_0.6x0.3mm_P0.4mm; Part Number ESDZV5H-1BU2
F4: 0805L010/24YR; Fuse_0805_2012Metric; Voltage Rated 24 V; Part Number 0805L010/24YR
J801: FHDR_4POS_1.27MM; PinHeader_1x04_P1.27mm_Vertical; Part Number BD080-04-A-0230-L-D
JMP801, JMP802: JMP_2_OPEN; SolderJumper-2_P1.3mm_Open_TrianglePad1.0x1.5mm
R47, R48: 100R_1/20W; R_0201_0603Metric; Part Number RMCF0201FT100R
R805: 10R_1/20W; R_0201_0603Metric; Part Number RMCF0201JT10R0
R806: 1R_1/4W; R_0402_1005Metric; Part NumbeR SG73P1EWTTP1R0J
R807, R808: 680R_1/8W; R_0805_2012Metric; Part Number RMCF0805JT680R
U801: SN74LVC2G17DRYR; 6-SON; Part Number SN74LVC2G17DRYR
U802: MAX22028AWA+; SO-8_5.3x6.2mm_P1.27mm; Part Number MAX22028FAWA+

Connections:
/BLOCK DIAGRAM/ISOLATED DMX/DMX_BUFF_1A: U801.1 (1A); also elsewhere on the board
/BLOCK DIAGRAM/ISOLATED DMX/DMX_BUFF_1Y: U801.6 (1Y); also elsewhere on the board
/BLOCK DIAGRAM/ISOLATED DMX/DMX_BUFF_2A: U801.3 (2A); also elsewhere on the board
/BLOCK DIAGRAM/ISOLATED DMX/DMX_BUFF_2Y: U801.4 (2Y); also elsewhere on the board
/BLOCK DIAGRAM/ISOLATED DMX/MAX22028_A: D801.1, D803.2, R808.2, U802.6 (A); also elsewhere on the board
/BLOCK DIAGRAM/ISOLATED DMX/MAX22028_B: D801.2, D802.1, R807.1, U802.7 (B); also elsewhere on the board
/BLOCK DIAGRAM/ISOLATED DMX/MAX22028_RXD: U802.1 (RXD); also elsewhere on the board
/BLOCK DIAGRAM/ISOLATED DMX/MAX22028_TXD: U802.2 (TXD); also elsewhere on the board
/BLOCK DIAGRAM/ISOLATED DMX/MAX22028_VDDA: C802.2, C803.2, R805.2, U802.3 (VDDA)
/BLOCK DIAGRAM/ISOLATED DMX/MAX22028_VDDB: C804.1, C805.1, JMP801.1, R806.1, U802.8 (VDDB)
/BLOCK DIAGRAM/ISOLATED DMX/XLR_PIN2: J801.1; also elsewhere on the board
/BLOCK DIAGRAM/ISOLATED DMX/XLR_PIN3: J801.3; also elsewhere on the board
Earth: J801.4; also elsewhere on the board
unnamed: JMP801.2, R807.2
unnamed: JMP802.1, R808.1

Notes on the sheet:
Fc ~= 7.23 kHz 160 kHz
DESIGN NOTE: Bypass VDDB to GNDB with both 0.1μF and 1μF capacitors as close to the device as possible.
Terminals T and R correspond to the alternative line designators of A and B
I = 10 mA
INFO: Receiver Hysteresis: 410 mV
CHECKED
DESIGN NOTE: Bypass VDDA to GNDA with both 0.1μF and 1μF capacitors as close to the device as possible.
LAYOUT NOTE: Curve under the IC to provide enough creepage for Isolation Min Creepage = 5.5mm
I = +250 mA
I = 5 mA
DESIGN NOTE:
INFO:
Fc ~= 72.3 kHz 1.6 MHz

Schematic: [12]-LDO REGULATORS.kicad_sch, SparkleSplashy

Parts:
C1201, C1202, C1204, C1205: 100nF/6V3; C_0201_0603Metric; Part Number CC0201KRX7R5BB104
C1203, C1212: 10uF/16V; C_0603_1608Metric; Part Number GRT188R61C106KE13J
C1206, C1207, C1208, C1209, C1210, C1211: 2u2F/6V3; C_0201_0603Metric; Part Number CM03X5R225M06AH
D1201: NSR01F30NXT5G; Nexperia_DSN0603-2_0.6x0.3mm_P0.4mm; Voltage Rated 30 V; Current Rating 100 mA; Part Number NSR01F30NXT5G
D1202: 1N5819HW1-7-F; D_SOD-123F; Voltage Rated 40 V; Current Rating 1 A; Part Number 1N5819HW1-7-F
J1201: GRPB021VWVN-RC; PinHeader_1x02_P1.27mm_Vertical; Part Number GRPB021VWVN-RC
L1201: 10uH; L_0805_2012Metric; CURRENT RATING 300mA; Part Number MLZ2012M100HTD25
LED1201, LED1202, LED1203: GREEN; LED_0402_1005Metric; VOLTAGE RATED 2V8; Part Number B2841NG--05D000514U1930
LED1204: BLUE; LED_0402_1005Metric; VOLTAGE RATED 3V3; Part Number B2841NB--20C001414U1930
R1201, R1205, R1206, R1207, R1208, R1210: 10KR_1/20W; R_0201_0603Metric; Part Number RMCF0201FT10K0
R1202, R1203, R1204, R1209: 1KR_1/20W; R_0201_0603Metric; Part Number RMCF0201FT1K00
R1211, R1212, R1213: 100R_1/20W; R_0201_0603Metric; Part Number RMCF0201FT100R
R1214: 93K1R_1/20W; R_0201_0603Metric; Part Number RMCF0201FT93K1
R1215: 24KR_1/20W; R_0201_0603Metric; Part Number ERJ-1GNF2402C
R1216: 330R_1/10W; R_0402_1005Metric; Part Number ERJ-2RKF3300X
TC7, TC9: 47uF/10V; CP_EIA-2012-12_Kemet-R; Part Number TLJR476M010R3200
TP601: TestPoint_Pad_D1.0mm
U1201: BD33IC0WHFV-GTR; 6HVSOF; Part Number BD33IC0WHFV-GTR
U1202: AP3012KTR-G1; SOT-23-5; Part Number AP3012KTR-G1
U1203, U1204: LD56100DPU33R; 8-DFN; Part Number LD56100DPU33R

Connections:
+6V: C1212.2, D1202.1, LED1204.2, R1214.2; also elsewhere on the board
/BLOCK DIAGRAM/LDO REGULATORS/AP_FB: R1214.1, R1215.2, U1202.3 (FB)
/BLOCK DIAGRAM/LDO REGULATORS/AP_SW: D1202.2, L1201.2, U1202.1 (SW)
/BLOCK DIAGRAM/LDO REGULATORS/AP_~SHDN: R1204.2, R1206.1, U1202.4 (~SHDN)
/BLOCK DIAGRAM/LDO REGULATORS/ATWIL_PWR_EN: R1203.1; also elsewhere on the board
/BLOCK DIAGRAM/LDO REGULATORS/BD33_EN: R1203.2, R1207.1, U1201.4 (EN)
/BLOCK DIAGRAM/LDO REGULATORS/BKL_EN: R1204.1; also elsewhere on the board
/BLOCK DIAGRAM/LDO REGULATORS/KSZ_PWR_EN: R1202.1; also elsewhere on the board
/BLOCK DIAGRAM/LDO REGULATORS/LD56_1_EN: R1209.1, U1204.6 (EN)
/BLOCK DIAGRAM/LDO REGULATORS/LD56_1_LCON: R1205.2, U1204.3 (LCON)
/BLOCK DIAGRAM/LDO REGULATORS/LD56_2_EN: R1202.2, R1208.1, U1203.6 (EN)
/BLOCK DIAGRAM/LDO REGULATORS/LD56_2_LCON: R1201.2, U1203.3 (LCON)
/BLOCK DIAGRAM/LDO REGULATORS/PWR_EN: D1201.2; also elsewhere on the board
unnamed: C1205.2, D1201.1, J1201.1, R1209.2, R1210.1
unnamed: LED1201.1, R1211.2
unnamed: LED1202.1, R1212.2
unnamed: LED1203.1, R1213.2
unnamed: LED1204.1, R1216.2

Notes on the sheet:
+3V3 MCU, TFT, SPI_FLASH
PLACEMENT NOTE: This INPUT/OUTPUT capacitor must be located as close as possible to the input pin of the device and returned to a clean analog ground.
MAX OUTPUT CURRENT = 500 mA
INFO: V_EN > 2V
DESIGN NOTE:
GREEN LED FOR LDOs BLUE LED FOR BACKLIGHT DC/DC CONVERTER RED LED FOR MCU STATUS ORANGE LED FOR ETHERNET ENABLE AMBER LED FOR WIFI ENABLE +3V3_1 -> FOR MCU + TFTLCD + TOUCH +3V3_2 -> FOR ETHERNET CONTROLLER +3V3_3 -> FOR WIFI TX/RX +6VDC -> FOR TFT LCD BACKLIGHT
+3V3 KSZ
1 SECONDS
CHECKED
+6V DC/DC BOOST (BKL)
INFO: Shutdown Pin. Connect to 1.5V or higher to enable device (ON), 0.4V or lower to disable device (OFF)
PLACEMENT NOTE: Input capacitor CIN connected to VCC (Vin) should be placed as close to VCC(VIN) pin as possible.
INFO: Feedback Pin. Internally compares to 1.25V. Connect R1 and R2 resistor divider here. Calculate the Output Voltage according to the formula: VOUT=1.25V * (1+R1/R2)
PLACEMENT NOTE: Output capacitor COUT also should be placed as close to IC pin as possible. In case the part is connected to inner layer GND plane, please use several through holes.
DESIGN NOTE: A SW WILL EXTERNALLY WIRED TO THE HEADER FOR POWERING THE LDOs. IT SHOULD BE PUSHED FOR 1 SECOND, THEN THE MCU TAKE THE CONTROL OF THE EN PINs
INFO 2.4V < V_EN (BD33) < 5.5
MAX CURRENT TABLE FOR EACH SHEET DALI = +3V3/ +5mA RGB = +3V3/ +20mA DMX = +3V3/ +15mA E2PROM = +3V3/ +25mA TFT_LCD = +3V3/ +10mA CPT = +3V3/ +25mA IOVDD = +3V3/ +150mA ADC PWR = +3V3/ ~150uA USB_VDD = +3V3/ +2mA LAN7820 = +3V3/ +150mA TFT_BKL = +6V/ +100mA
PLACEMENT NOTE: This INPUT/OUTPUT capacitor must be located as close as possible to the input pin of the device and returned to a clean analog ground.
+3V3 ATWIL

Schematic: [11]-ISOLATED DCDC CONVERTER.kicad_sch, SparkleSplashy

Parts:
C1101, C1102: 100nF/63V; C_0805_2012Metric; Part Number C0805C104MMREC7210
C1103: 100nF/16V; C_0201_0603Metric; Part Numbner 0201X104K160CT
D1101: AQ1250-01ETG; SOD882; Part Number AQ1250-01ETG
EC1101, EC1102, EC1103: 10uF/50V; CP_Elec_5x5.3; Part Number 50SVPK10M
F1101: ERB-RE1R00V; Fuse_0603_1608Metric; VOLTAGE RATE 32VDC; Part Number ERB-RE1R00V
J1101, J1102, J1103: GRPB021VWVN-RC; PinHeader_1x02_P1.27mm_Vertical; Part Number GRPB021VWVN-RC
L1101: 4u7H; L_0603_1608Metric; CURRENT RATING 420mA; Part Number CWF1610-4R7K
R1101: 10KR_1/20W; R_0201_0603Metric; Part Number RMCF0201FT10K0
R1102: 0.1R_1/2W; R_0805_2012Metric; Part Number ERJ-6DSFR10V
R1103, R1104: 1KR_1/20W; R_0201_0603Metric; Part Number RMCF0201FT1K00
TC1101, TC1102: 33uF/16V; CP_EIA-3528-21_Kemet-B; Part Number TPSB336K016R0350
TC1103: 47uF/10V; CP_EIA-2012-12_Kemet-R; Part Number TLJR476M010R3200
TP601: TestPoint_Pad_D1.0mm
U1101: AP63205WU-7; SOT-23-6; Part Number AP63205WU-7
U1102: PRM3W-E12-S5-S; Converter_DCDC_XP_POWER-ITxxxxxS_THT; Part Number PRM3W-E12-S5-S
VDR1101: B72590P8200S060; R_0402_1005Metric; Part Number B72590P8200S060

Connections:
/BLOCK DIAGRAM/ISOLATED DCDC CONVERTER/AP05_BST: C1102.1, U1101.6 (BST)
/BLOCK DIAGRAM/ISOLATED DCDC CONVERTER/AP05_EN: R1101.2, U1101.2 (EN)
/BLOCK DIAGRAM/ISOLATED DCDC CONVERTER/AP05_SW: C1102.2, L1101.1, U1101.5 (SW)
unnamed: F1101.1, J1101.2
unnamed: J1102.2, R1103.2
unnamed: J1103.2, R1104.2
unnamed: C1101.2, EC1103.1, R1102.2, U1102.2 (VIN)
VCC: EC1101.1, EC1102.1, F1101.2, R1101.1, R1102.1, U1101.3 (VIN), VDR1101.2; also elsewhere on the board

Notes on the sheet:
INFO: This connector is for a green panel mount LED
DESIGN NOTE: RGB = +5V/ +45mA (CTRL CIRCUIT) DMX = +5V/ +-250mA
INFO: This connector is for a RED panel mount LED
CHECKED
Imax = 600mA
VIN = +5V TO +24V
Imax = 1000mA

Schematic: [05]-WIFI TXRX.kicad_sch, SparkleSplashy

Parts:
ANT501: 2450AT18A100E; Johanson_2450AT18x100; Part Number 2450AT18A100E
C416: 1uF/6V3; C_0201_0603Metric; Part Number CL03A105MQ3CSNH
C501, C514: 10nF/6V3; C_0201_0603Metric; Part Number 0201B103K6R3CT
C502, C505, C506, C509, C515, C516, C519, C525, C527, C528: 2u2F/6V3; C_0201_0603Metric; Part Number CM03X5R225M06AH
C503, C511, C512: 1pF/50V; C_0201_0603Metric; Part Number UMK063CG010CTHF
C504, C507, C508, C510, C520, C521, C524, C526, C529, C530: 100nF/6V3; C_0201_0603Metric; Part Number CC0201KRX7R5BB104
C513: 10uF/16V; C_0603_1608Metric; Part Number GRT188R61C106KE13J
C517, C518: 1p8F/50V; C_0201_0603Metric; Part Number UMK063CG1R8CTHF
C522, C523: 12pF/50V; C_0201_0603Metric; Part Number CC0201JRNPO9BN120
L501: L-07C3N9SV6T; L_0402_1005Metric; CURRENT RATING 300mA; Part Number L-07C3N9SV6T
L502: L-07C2N7SV6T; L_0402_1005Metric; CURRENT RATING 300mA; Part Number L-07C2N7SV6T
L503, L504: WLCM0603TGB3N3TB; L_0201_0603Metric; CURRENT RATING 400mA; Part Number WLCM0603TGB3N3TB
L505: MLZ1005M2R2WT000; L_0402_1005Metric; CURRENT RATING 350mA; Part Number MLZ1005M2R2WT000
L506: CW105550A-15NJ; L_0402_1005Metric; CURRENT RATING 560mA; Part Number CW105550A-15NJ
R419: 100KR_1/20W; R_0201_0603Metric; Part Number ERJ-1GNF1003C
R424: 10KR_1/20W; R_0201_0603Metric; Part Number RMCF0201FT10K0
R501, R502, R503, R504, R505: 0R_1/20W; R_0201_0603Metric; Part Number RMCF0201ZT0R00
R506: 100R_1/20W; R_0201_0603Metric; Part Number RMCF0201FT100R
R507, R508, R518, R520: 1MR_1/20W; R_0201_0603Metric; Part Number RMCF0201FT1M00
R509, R510, R511, R512: 27R4_1/20W; R_0201_0603Metric; Part Number RC0201FR-0727R4L
R514, R515, R516, R517: 1KR_1/20W; R_0201_0603Metric; Part Number RMCF0201FT1K00
TC501, TC502, TC503, TC504: 22uF/6V3; CP_EIA-3216-10_Kemet-I; Part Number TPSA226M006R0500
TP601: TestPoint_Pad_D1.0mm
U501: ATWILC1000B-MU-Y; QFN-40-1EP_5x5mm_P0.4mm_EP3.8x3.8mm_ThermalVias; Part Number ATWILC1000B-MU-Y
X501: 26MHz/10ppm; Crystal_SMD_2016-4Pin_2.0x1.6mm; Part Number ECS-260-12-37B2-CKM-TR

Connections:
+1V35: C501.2, C502.1, C504.1, C509.1, C510.1, C513.1, C514.1, C519.1, C524.1, C525.1, C526.1, C527.1, C529.1, L505.1, TC501.1, U501.2 (VDD_RF_RX_1V3), U501.3 (VDD_AMS_1V3), U501.4 (VDD_RF_TX_1V3), U501.14 (VDDC_1V3), U501.22 (VREG_BUCK), U501.27 (VDDC_1V3), U501.37 (VDD_SXDIG_1V3), U501.38 (VDD_VCO_1V3); also elsewhere on the board
/BLOCK DIAGRAM/ATWIL_EN: R508.1, U501.23 (CHIP_EN); also elsewhere on the board
/BLOCK DIAGRAM/ATWIL_IRNQ: R518.2, U501.11 (GPIO2/IRQN); also elsewhere on the board
/BLOCK DIAGRAM/ATWIL_~CS: R509.2, R520.2; also elsewhere on the board
/BLOCK DIAGRAM/MSPI_CLK: R512.2; also elsewhere on the board
/BLOCK DIAGRAM/MSPI_DI: R510.2; also elsewhere on the board
/BLOCK DIAGRAM/MSPI_DO: R511.2; also elsewhere on the board
/BLOCK DIAGRAM/WIFI TXRX/ATWIL_RXD: R516.1, U501.28 (GPIO3)
/BLOCK DIAGRAM/WIFI TXRX/ATWIL_SPI_CFG: R507.2, U501.9 (~SDIO_SPI_CFG)
/BLOCK DIAGRAM/WIFI TXRX/ATWIL_TXD: R517.1, U501.30 (GPIO5)
/BLOCK DIAGRAM/WIFI TXRX/ATWIL_TX_N: C518.2, U501.8 (RFION)
/BLOCK DIAGRAM/WIFI TXRX/ATWIL_TX_P: C517.2, U501.7 (RFIOP)
/BLOCK DIAGRAM/WIFI TXRX/ATWIL_VBATT: C505.1, C507.1, R501.2, U501.20 (VBATT_BUCK_3V3)
/BLOCK DIAGRAM/WIFI TXRX/ATWIL_VBATT_BUCK: C506.1, C508.1, R502.2, U501.5 (VDD_BATT_PPA_3V3), U501.6 (VDD_BATT_PA_3V3)
/BLOCK DIAGRAM/WIFI TXRX/ATWIL_VDDIO: C515.1, C516.1, C520.1, C521.1, R503.2, R504.2, U501.15 (VDDIO_3V3), U501.26 (VDDIO_3V3)
/BLOCK DIAGRAM/WIFI TXRX/ATWIL_VDDIO_A: C528.1, C530.1, R505.2, U501.39 (VDDIO_A_3V3)
/BLOCK DIAGRAM/WIFI TXRX/ATWIL_VSW: L506.2, U501.21 (VSW)
/BLOCK DIAGRAM/WIFI TXRX/ATWIL_XO_N: R506.2, U501.35 (XO_N)
/BLOCK DIAGRAM/WIFI TXRX/ATWIL_XO_P: C522.2, U501.36 (XO_P), X501.1
unnamed: ANT501.1, L501.1
unnamed: C503.1, L501.2, L502.1
unnamed: C503.2, C511.1, L504.1
unnamed: C511.2, C517.1, L503.2
unnamed: C512.2, C518.1, L504.2
unnamed: C523.2, R506.1, X501.3
unnamed: L505.2, L506.1
unnamed 163: R514.2; also elsewhere on the board
unnamed 164: R515.2; also elsewhere on the board
unnamed 165: R516.2; also elsewhere on the board
unnamed 166: R517.2; also elsewhere on the board
unnamed: R515.1, U501.32 (I2C_SCL)
unnamed: R514.1, U501.33 (I2C_SDA)
unnamed: R512.1, U501.18 (SD_CMD/SPI_SCK)
unnamed: R510.1, U501.17 (SD_DAT0/SPI_TXD)
unnamed: R509.1, U501.16 (SD_DAT1/SPI_SSN)
unnamed: R511.1, U501.13 (SD_DAT2/SPI_RXD)

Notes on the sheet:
INFO: (RESETN PIN) • Active-low hard Reset • Assert low to place the device in Reset state • Assert high to put the device in Normal state and move it out of Reset state • Connect to a host output that has default low at power-up; if the host output is tristated, add a 1 MΩ pull-down res
CHARGING CONSTANT IS 50mSec
CLOCKS 26 MHz
CIRCUIT
RESET ENABLE
GPIOS
CHECKED CHECKED
IRQ PINS
INFO: Used only for development debug purposes; It is recommended to add test point for this pin
STATUS
CHECKED
INFO: (CHIP_EN PIN) • Device enable • High level enables device, low level places device in Power-Down mode • Connect to a host output that has default low at power-up; if the host output is tristated, add a 1 MΩ pull-down resistor to ensure a low level at power-up
ANTENNA CONFIG PINS
INFO: (SDIO_SPI_CFG) • Tie to VDDIO through a 1 MΩ resistor to enable the SPI interface • Tie to GND to enable the SDIO interface
SPI INTERFACE
INFO: (TEST MODE PIN) Test Mode – User must tie this pin to GND
POWER 3.3V POWER 1.3V

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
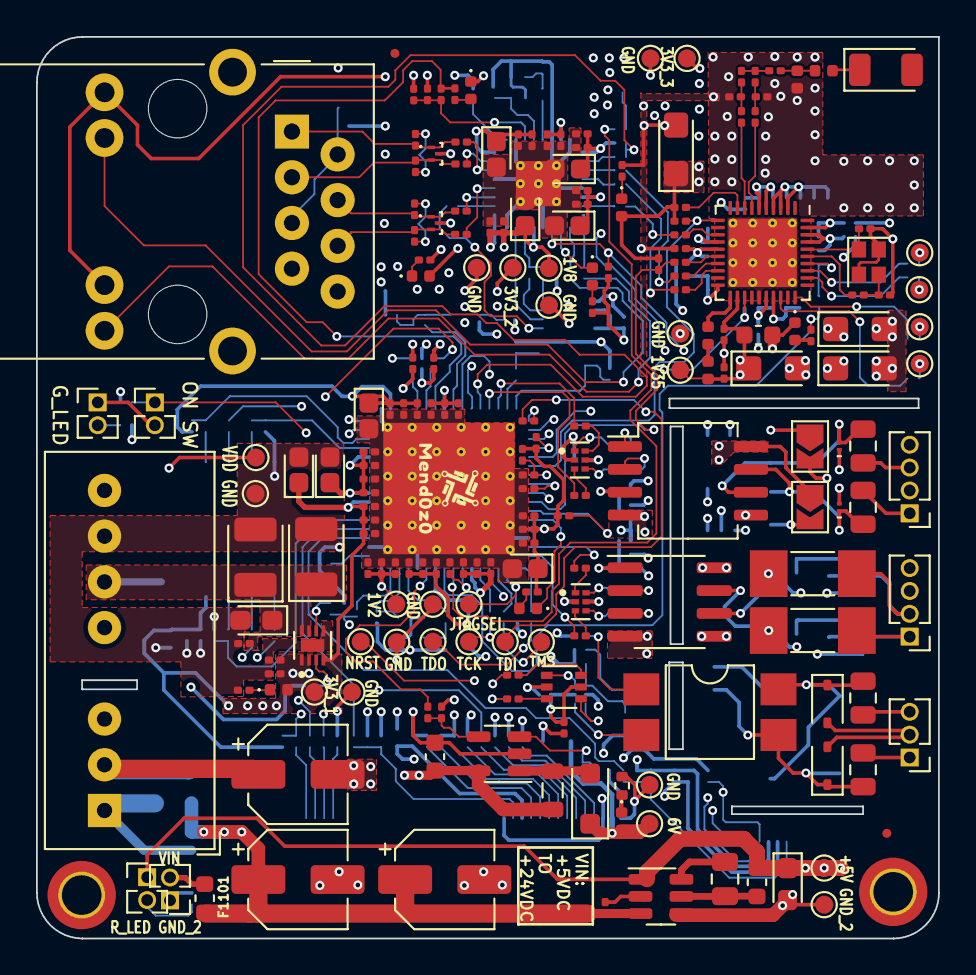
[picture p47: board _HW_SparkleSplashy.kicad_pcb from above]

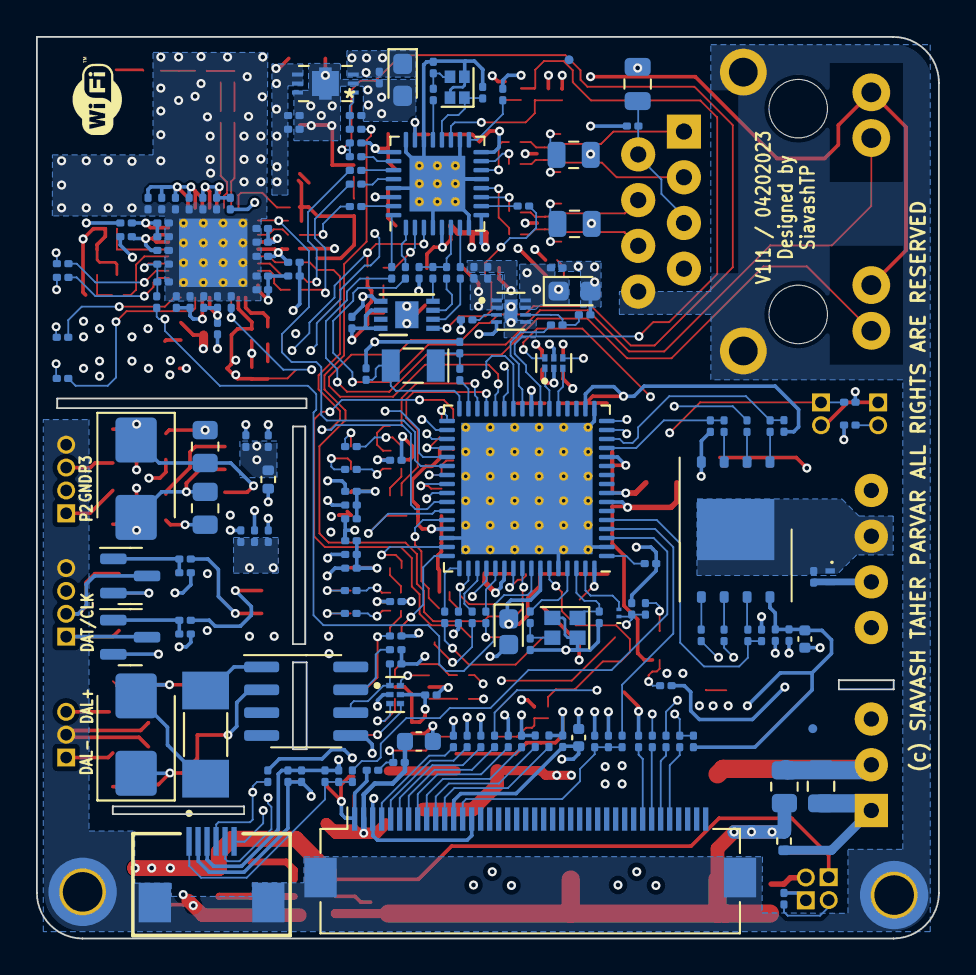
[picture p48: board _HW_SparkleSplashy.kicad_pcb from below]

Board: 4 copper layers, 50.1 x 50.1 mm, 381 parts (178 on the bottom side), 212 nets.

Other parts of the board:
C406, C407: 12pF/50V; C_0201_0603Metric
C531, C601, C606: 1uF/6V3; C_0201_0603Metric
F801, F802: 0805L010/24YR; Fuse_0805_2012Metric
R427, R519, R601, R603, R605: 10KR_1/20W; R_0201_0603Metric
R513, R602, R618: 100KR_1/20W; R_0201_0603Metric
R801, R802, R803, R804, R901, R902: 100R_1/20W; R_0201_0603Metric
TC1201, TC1202, TC1203: 47uF/10V; CP_EIA-2012-12_Kemet-R
TP501, TP502, TP503, TP504, TP505, TP506, TP1101, TP1102, TP1103, TP1104, TP1201, TP1202, TP1203, TP1204, TP1205, TP1206, TP1207, TP1208: TestPoint_Pad_D1.0mm

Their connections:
+1V35: TP501.1; also elsewhere on the board
+6V: TP1201.1; also elsewhere on the board
/BLOCK DIAGRAM/ATWIL_~RST: R519.1; also elsewhere on the board
/BLOCK DIAGRAM/CTP_~RST: R601.1; also elsewhere on the board
/BLOCK DIAGRAM/DALI_RX: R901.1; also elsewhere on the board
/BLOCK DIAGRAM/DALI_TX: R902.1; also elsewhere on the board
/BLOCK DIAGRAM/DMX_RX: R801.1; also elsewhere on the board
/BLOCK DIAGRAM/DMX_TX: R802.1; also elsewhere on the board
/BLOCK DIAGRAM/ETHERNET CONTROLLER/KSZ_XTAL1: C406.2; also elsewhere on the board
/BLOCK DIAGRAM/ISOLATED DALI/DALI_BUFF_1Y: R901.2; also elsewhere on the board
/BLOCK DIAGRAM/ISOLATED DALI/DALI_BUFF_2A: R902.2; also elsewhere on the board
/BLOCK DIAGRAM/ISOLATED DMX/DMX_BUFF_1A: R803.1; also elsewhere on the board
/BLOCK DIAGRAM/ISOLATED DMX/DMX_BUFF_1Y: R801.2; also elsewhere on the board
/BLOCK DIAGRAM/ISOLATED DMX/DMX_BUFF_2A: R802.2; also elsewhere on the board
/BLOCK DIAGRAM/ISOLATED DMX/DMX_BUFF_2Y: R804.1; also elsewhere on the board
/BLOCK DIAGRAM/ISOLATED DMX/MAX22028_A: F802.1; also elsewhere on the board
/BLOCK DIAGRAM/ISOLATED DMX/MAX22028_B: F801.1; also elsewhere on the board
/BLOCK DIAGRAM/ISOLATED DMX/MAX22028_RXD: R803.2; also elsewhere on the board
/BLOCK DIAGRAM/ISOLATED DMX/MAX22028_TXD: R804.2; also elsewhere on the board
/BLOCK DIAGRAM/ISOLATED DMX/XLR_PIN2: F801.2; also elsewhere on the board
/BLOCK DIAGRAM/ISOLATED DMX/XLR_PIN3: F802.2; also elsewhere on the board
/BLOCK DIAGRAM/TFT_~RST: R605.1; also elsewhere on the board
unnamed 129: C407.2; also elsewhere on the board
unnamed 163: TP503.1; also elsewhere on the board
unnamed 164: TP504.1; also elsewhere on the board
unnamed 165: TP505.1; also elsewhere on the board
unnamed 166: TP506.1; also elsewhere on the board

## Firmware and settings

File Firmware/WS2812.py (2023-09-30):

# Example using PIO to drive a set of WS2812 LEDs.

import array, time
from machine import Pin
import rp2

# Configure the number of WS2812 LEDs.
NUM_LEDS = 64
PIN_NUM = 22
brightness = 0.1

@rp2.asm_pio(sideset_init=rp2.PIO.OUT_LOW, out_shiftdir=rp2.PIO.SHIFT_LEFT, autopull=True, pull_thresh=24)
def ws2812():
    T1 = 2
    T2 = 5
    T3 = 3
    wrap_target()
    label("bitloop")
    out(x, 1)               .side(0)    [T3 - 1]
    jmp(not_x, "do_zero")   .side(1)    [T1 - 1]
    jmp("bitloop")          .side(1)    [T2 - 1]
    label("do_zero")
    nop()                   .side(0)    [T2 - 1]
    wrap()


# Create the StateMachine with the ws2812 program, outputting on pin
sm = rp2.StateMachine(0, ws2812, freq=8_000_000, sideset_base=Pin(PIN_NUM))

# Start the StateMachine, it will wait for data on its FIFO.
sm.active(1)

# Display a pattern on the LEDs via an array of LED RGB values.
ar = array.array("I", [0 for _ in range(NUM_LEDS)])

##########################################################################
def pixels_show():
    dimmer_ar = array.array("I", [0 for _ in range(NUM_LEDS)])
    for i,c in enumerate(ar):
        r = int(((c >> 8) & 0xFF) * brightness)
        g = int(((c >> 16) & 0xFF) * brightness)
        b = int((c & 0xFF) * brightness)
        dimmer_ar[i] = (g<<16) + (r<<8) + b
    sm.put(dimmer_ar, 8)
    time.sleep_ms(10)

def pixels_set(i, color):
    ar[i] = (color[1]<<16) + (color[0]<<8) + color[2]

def pixels_fill(color):
    for i in range(len(ar)):
        pixels_set(i, color)

def color_chase(color, wait):
    for i in range(NUM_LEDS):
        pixels_set(i, color)
        time.sleep(wait)
        pixels_show()
    time.sleep(0.2)
 
def wheel(pos):
    # Input a value 0 to 255 to get a color value.
    # The colours are a transition r - g - b - back to r.
    if pos < 0 or pos > 255:
        return (0, 0, 0)
    if pos < 85:
        return (255 - pos * 3, pos * 3, 0)
    if pos < 170:
        pos -= 85
        return (0, 255 - pos * 3, pos * 3)
    pos -= 170
    return (pos * 3, 0, 255 - pos * 3)
 
 
def rainbow_cycle(wait):
    for j in range(255):
        for i in range(NUM_LEDS):
            rc_index = (i * 256 // NUM_LEDS) + j
            pixels_set(i, wheel(rc_index & 255))
        pixels_show()
        time.sleep(wait)

BLACK = (0, 0, 0)
RED = (255, 0, 0)
YELLOW = (255, 150, 0)
GREEN = (0, 255, 0)
CYAN = (0, 255, 255)
BLUE = (0, 0, 255)
PURPLE = (180, 0, 255)
WHITE = (255, 255, 255)

GRAY = (0X1F, 0XaF, 0X3F)

COLORS = (BLACK, RED, YELLOW, GREEN, CYAN, BLUE, PURPLE, WHITE)

def PixelFadeInOut(number, color):
    fadedColor = [0,0,0]
    flag = 0;
    for i in range (255):
        if(fadedColor[0] < color[0]):
            fadedColor[0] += 1
        if(fadedColor[1] < color[1]):
            fadedColor[1] += 1
        if(fadedColor[2] < color[2]):
            fadedColor[2] += 1
        if((fadedColor[2] == color[2]) and (fadedColor[1] == color[1]) and (fadedColor[0] == color[0])):
            break
        pixels_set(number, fadedColor)
        pixels_show()
        time.sleep(0.1)
    flag = 0
    for i in range(255):
        if(fadedColor[0] > 0):
            fadedColor[0] -= 1
        if(fadedColor[1] > 0):
            fadedColor[1] -= 1
        if(fadedColor[2] > 0):
            fadedColor[2] += 1
        if((fadedColor[2] == 0) and (fadedColor[1] == 0) and (fadedColor[0] == 0)):
            break
        pixels_set(number, fadedColor)
        pixels_show()
        time.sleep(0.1)

class ColorSet:
        
    def __init__(pixel, number, color, rs, fs):
        pixel.color = color
        pixel.number = number
        pixel.rs = rs
        pixel.fs = fs
        pixel.pixelColor = [0,0,0]
        pixel.idFlag = 0
    
    
    def SetColor(color):
        
        if((color.pixelColor[0] >= color.color[0]) and (color.pixelColor[1] >= color.color[1]) and (color.pixelColor[2] >= color.color[2])):
            color.idFlag = 1
            
        if(color.idFlag == 0):
            if(color.pixelColor[0] < color.color[0]):
                color.pixelColor[0] += color.rs
            if(color.pixelColor[1] < color.color[1]):
                color.pixelColor[1] += color.rs
            if(color.pixelColor[2] < color.color[2]):
                color.pixelColor[2] += color.rs
        elif(color.idFlag == 1):
            if((color.pixelColor[0] < 1) or (color.pixelColor[0] < 1) or (color.pixelColor[0] < 1)):
                color.pixelColor[0] = 0
                color.pixelColor[1] = 0
                color.pixelColor[2] = 0
                color.idFlag = 0
            else:
                color.pixelColor[0] -= color.fs
                color.pixelColor[1] -= color.fs
                color.pixelColor[2] -= color.fs
                
        pixels_set(color.number, color.pixelColor)

        
def RGBFadeInOut():
    for i in range(64):
        pixels_set(i, (0X0F, 0X0F, 0X0F))
    pixels_show()
    p1 = ColorSet(1, GREEN, 1, 1)
    p2 = ColorSet(2, RED, 2, 5)
    p3 = ColorSet(3, BLUE, 7, 2)
    p30 = ColorSet(30, PURPLE, 5, 5)
    p40 = ColorSet(40, GRAY, 3, 6)
    while True:
        p1.SetColor()
        p2.SetColor()
        p3.SetColor()
        p30.SetColor()
        p40.SetColor()
        pixels_show()
        #time.sleep(0.1)


RGBFadeInOut()

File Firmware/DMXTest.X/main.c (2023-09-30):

#include "p24fj256ga705.h"
#define FCY (4000000UL)
#include "libpic30.h"

// FSEC
#pragma config BWRP = OFF               // Boot Segment Write-Protect bit (Boot Segment may be written)
#pragma config BSS = DISABLED           // Boot Segment Code-Protect Level bits (No Protection (other than BWRP))
#pragma config BSEN = OFF               // Boot Segment Control bit (No Boot Segment)
#pragma config GWRP = OFF               // General Segment Write-Protect bit (General Segment may be written)
#pragma config GSS = DISABLED           // General Segment Code-Protect Level bits (No Protection (other than GWRP))
#pragma config CWRP = OFF               // Configuration Segment Write-Protect bit (Configuration Segment may be written)
#pragma config CSS = DISABLED           // Configuration Segment Code-Protect Level bits (No Protection (other than CWRP))
#pragma config AIVTDIS = OFF            // Alternate Interrupt Vector Table bit (Disabled AIVT)

// FBSLIM
#pragma config BSLIM = 0x1FFF           // Boot Segment Flash Page Address Limit bits (Enter Hexadecimal value)

// FOSCSEL
#pragma config FNOSC = FRC              // Oscillator Source Selection (Internal Fast RC (FRC))
#pragma config PLLMODE = DISABLED       // PLL Mode Selection (No PLL used; PLLEN bit is not available)
#pragma config IESO = OFF               // Two-speed Oscillator Start-up Enable bit (Start up with user-selected oscillator source)

// FOSC
#pragma config POSCMD = NONE            // Primary Oscillator Mode Select bits (Primary Oscillator disabled)
#pragma config OSCIOFCN = OFF           // OSC2 Pin Function bit (OSC2 is clock output)
#pragma config SOSCSEL = ON             // SOSC Power Selection Configuration bits (SOSC is used in crystal (SOSCI/SOSCO) mode)
#pragma config PLLSS = PLL_PRI          // PLL Secondary Selection Configuration bit (PLL is fed by the Primary oscillator)
#pragma config IOL1WAY = ON             // Peripheral pin select configuration bit (Allow only one reconfiguration)
#pragma config FCKSM = CSDCMD           // Clock Switching Mode bits (Both Clock switching and Fail-safe Clock Monitor are disabled)

// FWDT
#pragma config WDTPS = PS32768          // Watchdog Timer Postscaler bits (1:32,768)
#pragma config FWPSA = PR128            // Watchdog Timer Prescaler bit (1:128)
#pragma config FWDTEN = OFF             // Watchdog Timer Enable bits (WDT and SWDTEN disabled)
#pragma config WINDIS = OFF             // Watchdog Timer Window Enable bit (Watchdog Timer in Non-Window mode)
#pragma config WDTWIN = WIN25           // Watchdog Timer Window Select bits (WDT Window is 25% of WDT period)
#pragma config WDTCMX = WDTCLK          // WDT MUX Source Select bits (WDT clock source is determined by the WDTCLK Configuration bits)
#pragma config WDTCLK = LPRC            // WDT Clock Source Select bits (WDT uses LPRC)

// FPOR
#pragma config BOREN = OFF              // Brown Out Enable bit (Brown Out Disabled)
#pragma config LPCFG = OFF              // Low power regulator control (No Retention Sleep)
#pragma config DNVPEN = ENABLE          // Downside Voltage Protection Enable bit (Downside protection enabled using ZPBOR when BOR is inactive)

// FICD
#pragma config ICS = NONE               // ICD Communication Channel Select bits (Reserved, do not use)
#pragma config JTAGEN = OFF             // JTAG Enable bit (JTAG is disabled)

// FDEVOPT1
#pragma config ALTCMPI = DISABLE        // Alternate Comparator Input Enable bit (C1INC, C2INC, and C3INC are on their standard pin locations)
#pragma config TMPRPIN = OFF            // Tamper Pin Enable bit (TMPRN pin function is disabled)
#pragma config SOSCHP = ON              // SOSC High Power Enable bit (valid only when SOSCSEL = 1 (Enable SOSC high power mode (default))
#pragma config ALTI2C1 = ALTI2CDIS      // Alternate I2C pin Location (ASDA1 and ASCL1 on RB5 and RB6)

// #pragma config statements should precede project file includes.
// Use project enums instead of #define for ON and OFF.


/*******************/

#define MSG "HELLO! WHY IT'S LIKE THIS?! \r\n"


void _init_UART( void );
int SendByteOnUART( char data );
int SendDataOnUART(const char *p_data);

int main(){
    char data[7] = {0XAA, 0X77, 0X00, 0Xff, 0X33, 0X00, 0XAA};
    _init_UART();
    __delay_ms(5000);
    while(1){
        SendDataOnDMX( data, 7);
        __delay_ms(5);
    }
}

void _init_UART( void ){
    /*asm volatile (  "MOV #OSCCON, w1 \n"
                    "MOV #0x46, w2 \n"
                    "MOV #0x57, w3 \n"
                    "MOV.b w2, [w1] \n"
                    "MOV.b w3, [w1] \n"
                    "BCLR OSCCON, #6") ;*/
    //configure the GPIO pin RB7->TX, RB8->RX
    TRISBbits.TRISB7 = 0;   //  SET PINB.0 AS OUTPUT
    LATBbits.LATB7 = 1;     //  SET HIGH AT START UP
    RPOR3bits.RP7R = 3;    //   Assign U1TX To Pin RP7
    //configure the UART
    U1BRG = 0;             //  !!!!!!!!!!! SET IT TO 250K !!!!!!!!!!!Set the baud-rate to 9600 for Fcy = 4MHz.
    U1MODEbits.STSEL = 1;   // TWO STOP BITS!
    U1MODEbits.UARTEN = 1;  //  Enable UART peripheral.
    U1STAbits.UTXEN = 1;    //  Enable transmit
}

void SendBRKOnUART( int duration /*value in microseconds*/){
    // Disable UART
    U1STAbits.UTXEN = 0;
    // Set the GPIO to 0
    LATBbits.LATB7 = 0;
    // Wait for the desired duration
    __delay_us(duration);
    // Set the GPIO to 1
    LATBbits.LATB7 = 1;
    // Enable the UART
    U1STAbits.UTXEN = 1;  
}

int SendByteOnUART( char data ){
   //Waiting until the transmission ends
    while(U1STAbits.TRMT == 0){
    }
    //since the buffer is empty we upload new data;
    U1TXREG = data;
    return 1;
}

int SendDataOnUART(const char *p_data){
    char data = 1;
    while(data){
        data = (char)*p_data;
        SendByteOnUART(data);
        p_data += 1;
    }
    return 1;
}

int SendDataOnDMX( const char *p_data, int size){
    SendBRKOnUART(88);
    __delay_us(8);
    SendByteOnUART(0);
    for(int counter = 0; counter < size; ++counter){
       SendByteOnUART(*(p_data + counter)); 
    }
    return 1;
}

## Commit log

2023-12-26 Some modification in file structure
    [F305-1A7H1-11006-E100--3DModel-STEP-533217.STEP, HVSOF6_ROM.step, LAN8720A-CP.step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]
2024-01-07 Change in directory date
    [F305-1A7H1-11006-E100--3DModel-STEP-533217.STEP, HVSOF6_ROM.step, LAN8720A-CP.step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]
2024-02-04 Exporting BOM
    [_HW_SparkleSplashy.csv, _HW_SparkleSplashy.kicad_pcb]
2024-02-04 Creating CAD folder for 3D CAD model
2024-02-04 3D CAD Mech has been created.
    [_MECH_SparkleSplashy.cfg]
2024-02-04 Enclosure sides have been created!
    [_MECH_SparkleSplashy.cfg]
2024-02-04 Some dimensions have been added and a 3D model has been modified
    [_HW_SparkleSplashy.kicad_pcb]
2024-02-05 Working on 3D CAD Model
    [Hex Standoff, Male-Female, M2.5, L8mm.stp, M2.5 Nut.SLDPRT, User Library-M2_5-A4-socket-cap-screw-din 912.step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]

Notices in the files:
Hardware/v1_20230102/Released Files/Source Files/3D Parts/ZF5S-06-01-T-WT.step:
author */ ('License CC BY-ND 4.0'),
